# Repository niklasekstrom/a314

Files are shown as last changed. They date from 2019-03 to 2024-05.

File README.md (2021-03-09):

# A314

## What is it?

The *A314* is an expansion board for the Amiga 500 that goes in the trapdoor expansion slot. A Raspberry Pi (RPi) is attached to the A314, and the A500 and the RPi can communicate through a shared memory.

| | |
| --- |---|
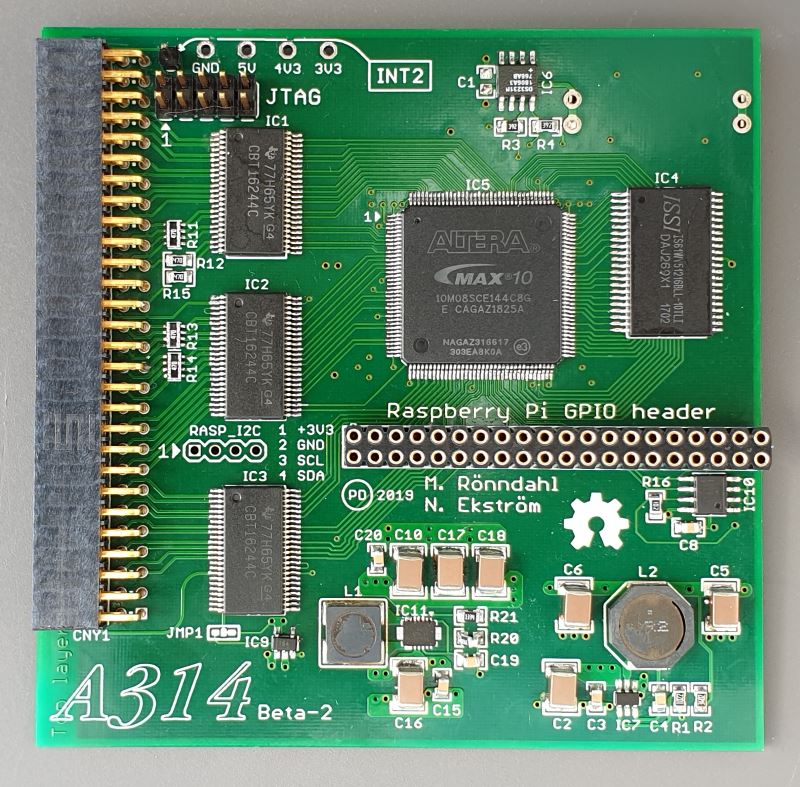
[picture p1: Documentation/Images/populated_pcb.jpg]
PCB
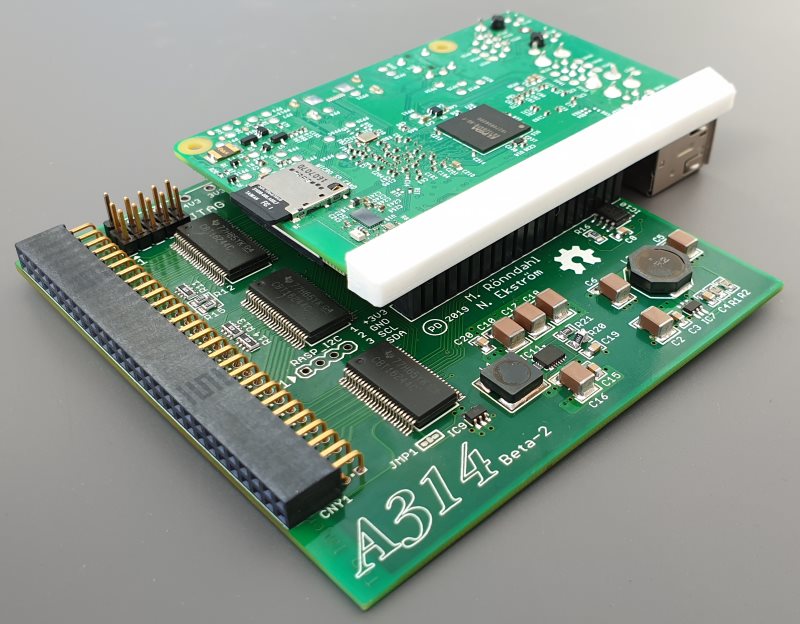
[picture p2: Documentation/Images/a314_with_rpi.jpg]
A314 with RPi attached
|  |  |

We have constructed a communication protocol through which associated processes on each platform (Amiga and RPi) can allocate logical channels, carried over one physical SPI channel. The protocol is handled by a driver on each side ([*a314.device*](Software/a314device) on the Amiga and [*a314d*](Software/a314d) on the RPi). The drivers are responsible for alerting receiving processes of incoming data via an interrupt.

## What can you do with it today?

We have implemented a few services that run on the RPi and on the A500:

*  [*a314fs*](Software/a314fs) is a file system that is mounted in AmigaDOS as a device, PI0:  
The volume in PI0: is called PiDisk:, and is mapped to a directory in the RPi.

*  [*pi*](Software/picmd) is a command that lets you invoke executables on the RPi from the AmigaDOS CLI. For example, if your current working directory is on PiDisk: and you run "pi vc hello.c -o hello", then the vc program (the VBCC cross-compiler) is executed on the RPi with the given arguments. It will cross-compile “hello.c” into the Amiga executable file “hello”. The resulting binary is immediately accessible through the a314fs.  
You may also launch Interactive applications using the pi command, such as "pi mc -a" which will run Midnight Commander. Running pi without any arguments is equivalent to "pi bash" and will present you with a bash prompt from the RPi.

| | |
| --- |---|
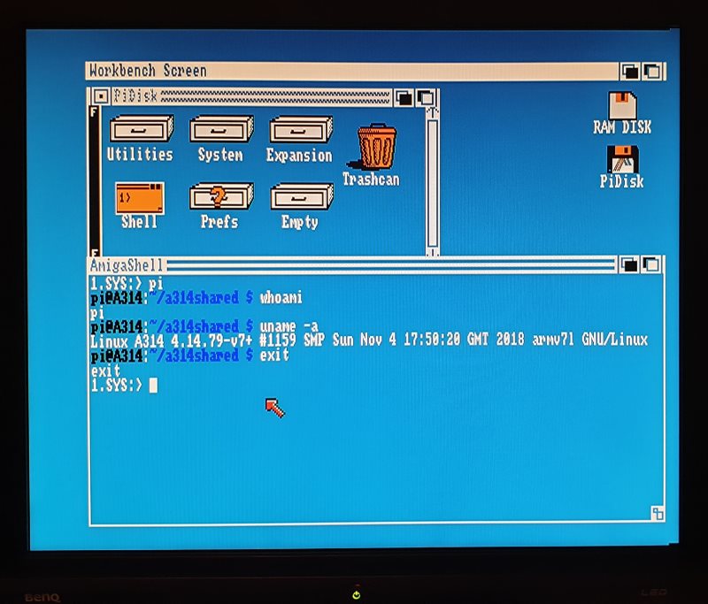
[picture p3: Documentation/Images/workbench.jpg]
Pi command
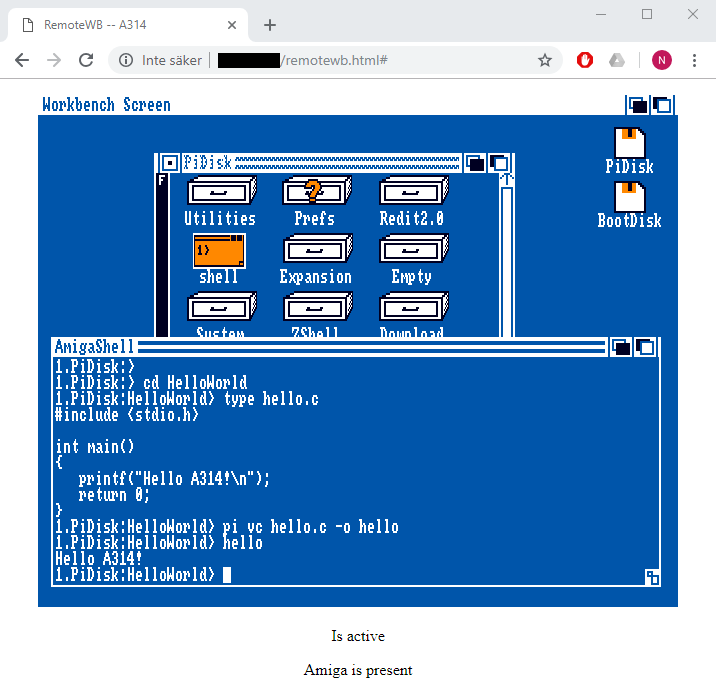
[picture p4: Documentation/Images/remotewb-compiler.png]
Cross-compiling in RemoteWB
|   |  |

* [*PiAudio*](Software/piaudio) lets the RPi stream audio samples directly to the shared chip memory, from where Paula plays those samples. PiAudio is integrated with [ALSA](https://www.alsa-project.org) on the RPi so that any program that plays audio through ALSA can be used, i.e. "pi mpg123 -a amiga song.mp3" plays song.mp3 using the program mpg123 to the Amiga.

*  [*RemoteWB*](Software/remotewb) works by moving the Workbench bitplanes over to the chip memory on the A314. This requires that the A500 has at least a 8372 Agnus. During drawing of each frame on the Amiga, the RPi reads those bitplanes, encodes them into a [GIF image](Software/bpls2gif), and transmits that image to a web browser through a web socket. The web browser in turn, returns key presses and mouse movements back to the Amiga through the same web socket. In effect, this becomes a web browser based remote control application, comparable to VNC but with near zero performance impact on the Amiga CPU!

*  [*VideoPlayer*](Software/videoplayer) is a simple program that displays a sequence of images on the A500 by letting the RPi write bitplanes directly to the shared memory (this again requires that the A314 memory is chip memory, and not "ranger" memory).

* [*ethernet*](Software/ethernet) is a SANA-II driver that forwards Ethernet packets to the network interface of the RPi. Together with an Amiga TCP/IP stack this provides network access to the Amiga.

## What could it potentially be used for in the future?

Here are some services that we have considered but not gotten around to implement:

* Networking through a *bsdsocket.library* implementation that forwards socket operations to the RPi and executes those operations there. This would give a higher degree of offloading than using the SANA-II driver with a TCP/IP stack running on the Amiga.

* Your ideas?

## Do you want to get involved?

If this sounds interesting, you'll probably want an A314 of your own to play with. We have released all the information needed to make a board, freely available in this GitHub repository.

In the [Hardware](Hardware) directory there are [schematics](Hardware/v1.1/Schematics/A314v1.1.pdf) and [Gerber files](Hardware/v1.1/Gerbers) that can be used to produce a PCB.

The Verilog source code used to generate a programming object file (.pof) for the Intel MAX 10 FPGA is available in the [HDL](HDL) directory. You'll need a USB-Blaster download cable (or a clone) to connect to the JTAG connector on the A314 board. You can compile the design using the [Quartus Prime Lite Edition](http://fpgasoftware.intel.com/?edition=lite).

The source code for the software that runs on the Amiga and on the RPi is available in the [Software](Software) directory.

If you have an idea about something cool to make using the A314, but you don't have the means to build a PCB on your own, then we have a small number of pre-built boards that we plan to hand out, given the idea sounds interesting enough. Send a message to Eriond on EAB and describe what you would like to make, and perhaps you can get one.

There used to be an IRC channel for discussing A314, but we have since moved to Discord. [Here's the invite link](https://discord.gg/TGZNKnA).

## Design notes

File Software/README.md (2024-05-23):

# A314 Software

The A314 software supports multiple variants of A314 hardware.
The variants of the software use the following acronyms:

- a314-td (trapdoor), works with A314-500 and A314-600
- a314-cp (clockport), works with A314-cp
- a314-fe (front expansion), works with A314-1000

## How to install

Software needs to be installed on both the Raspberry Pi side and on the Amiga side.

### Raspberry Pi

To build and install the software on the Raspberry Pi side, do the following:

- Install Raspberry Pi OS (I tend to use Raspberry Pi OS Lite 64-bit,
  but any recent version should work):
  <https://www.raspberrypi.com/software/operating-systems/>
- Update apt packages: `sudo apt update`, `sudo apt upgrade`
- Install Dependencies: `sudo apt install python3-dev python3-distutils python3-pip python3-virtualenv build-essential git iptables libraspberrypi-dev`
- Obtain a copy of the repository, either:
  - Clone the a314 repository: `git clone https://github.com/niklasekstrom/a314.git`, or
  - Download the sources from a release. Pick a release from
    <https://github.com/niklasekstrom/a314/releases>, download the file linked to as
    Source code (tar.gz), and extract with `tar xvf <filename>.tar.gz`.
- Change into the Software directory: `cd a314/Software`
- Run the installer script: `sudo ./install-pi.sh <model>`, where `<model>` is
  `td`, `cp` or `fe` depending on which variant of A314 is used.
- Reboot the Raspberry Pi: `sudo reboot now`

### Amiga

The binaries for the Amiga side are already built and are available as part of a release on the GitHub page: <https://github.com/niklasekstrom/a314/releases>

There are multiple sub directories in the release archive, and the files in those sub directories should be copied to the corresponding sub directories in the AmigaOS system volume.

Note that in the Devs directory there are multiple different versions of a314.device:
`a314-td.device`, `a314-cp.device`, `a314-fe.device`.
Copy only the version that matches your A314 hardware and rename it to `a314.device`.

After these files are copied to the Amiga it should be possible to run the pi command.
The pi command can be invoked by `pi` without any arguments to get an interactive bash terminal,
or with arguments to run a particular Linux command.

#### Configuration file

For the a314-cp driver it is possible to write a configuration file to `DEVS:a314.config`.
The configuration file is a text file, where each line has the format `<key> = <value>`.
The keys are:

- `ClockportAddress`: the address (in hexadecimal) of the clock port.
- `Interrupt`: the interrupt number used, either: 2 (INT2), 3 (Vertical blank), or 6 (INT6).

If the configuration file is not present then the default values are used, which for
a314-cp are:

```text
ClockportAddress = D80001
Interrupt = 6
```

#### Building

It is also possible to build the Amiga binaries from source, either on the Raspberry Pi or on a Linux PC.
To do so, follow these steps:

- Download and install VBCC:
  - On the bottom of this page, <http://www.compilers.de/vbcc.html>, there are archives with VBCC
    pre-compiled for different plattforms such as Linux (x64) and Raspberry Pi
  - Download the appropriate archive, e.g.: `wget http://www.ibaug.de/vbcc/vbcc_linux_x64.tar.gz`
  - Unpack to some suitable directory: `tar xvf vbcc_linux_x64.tar.gz -C ~/amiga/`
  - Set the VBCC environment variable: `export VBCC=~/amiga/vbcc`
  - Add VBCC to PATH: `export PATH=$VBCC/bin:$PATH`
- Download and add NDK3.2:
  - Download archive from Aminet: `wget http://aminet.net/dev/misc/NDK3.2.lha`
  - Install lha extraction software: `sudo apt install lhasa`
  - Extract archive: `lha xw=~/amiga/NDK3.2 NDK3.2.lha`
  - Add environment variable: `export NDK32=~/amiga/NDK3.2`
- Clone the a314 repo: `git clone https://github.com/niklasekstrom/a314.git ~/amiga/a314`
- Change into the Software directory: `cd ~/amiga/a314/Software`
- Build binaries by running: `make -f Makefile-amiga`

The binaries are now available in the sub directories of the `bin_amiga` directory.

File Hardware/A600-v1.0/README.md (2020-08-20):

# A314-600 PCB v1.0

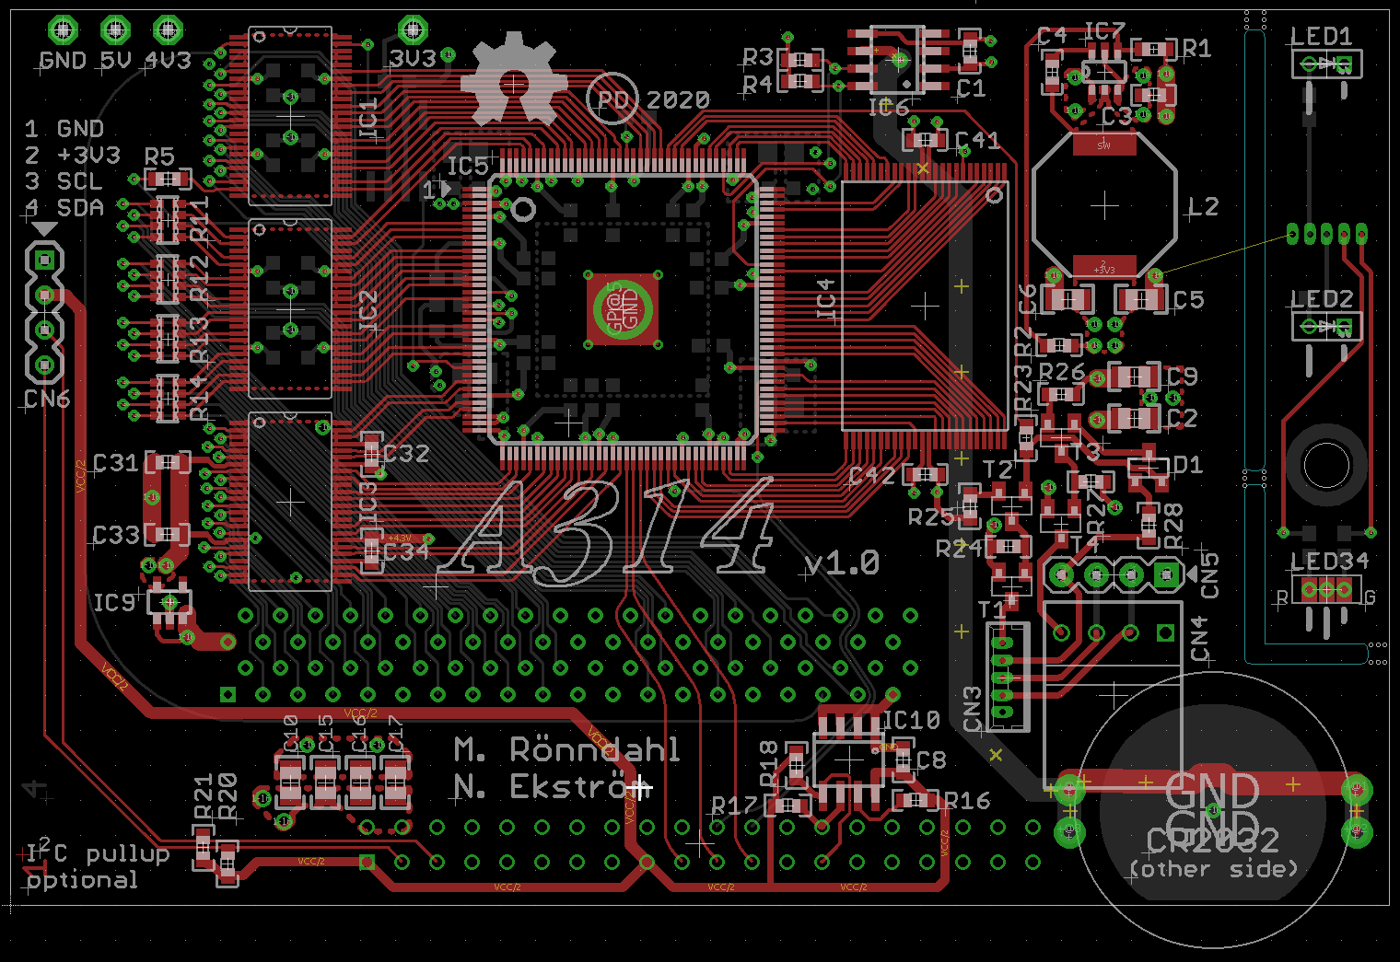
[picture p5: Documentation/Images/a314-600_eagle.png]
Layout screenshot

## Changelog

Initial commit of the **Amiga 600** version of the A314 board. Main differences compared to the Amiga 500 version:
 - 2MB chipRAM available as A314 shared memory (Disables the motherboard RAM)
 - Mechanical restrictions of the expansion bay implies Raspberry *Zero* form factor. The low power consumption and more generous voltage tolerances of the Zero* allowed for a simpler design, elliminating the 5V DC/DC converter (IC11 & Co.). 
 *see: https://raspberry-projects.com/pi/pi-hardware/raspberry-pi-zero/raspberry-pi-zero-hardware-general-specifications
  - Replacement LED board included. Allows for distinction between HardDrive and A314 activity on the same LED (Bi-colour)
 - Original LED overlay. If you don't want to use the included replacement LED board, then use your existing one, but connect it through the A314! A314 activity is then multiplexed on the HDD LED.
## Notes
This PCB has NPT milled slots with a narrow width (1.5mm) which some board houses won't accept. I have successfully used WellPCB with excellent results. Check with you favourite board house if they accept such narrow slots, before submitting a job.
At the moment of writing, AllPCB and JLCPCB could not handle this PCB. This may change in the future.

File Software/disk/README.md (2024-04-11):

# Disk Service

The disk service lets you mount disk images (ADF or HDF files) on the Raspberry
Pi as disk drives on the Amiga, PD0: through PD3:.

The a314disk.device is *romable* so it is possible to add it to a kickstart ROM
image and then it is possible to boot from a virtual drive. In the following
we focus on using a314disk.device as a normal device driver stored on disk.

## Disk geometry

The first time that a disk image (an ADF/HDF file) is inserted in a virtual
drive, the size of the ADF file is read, and from the size the disk geometry is
inferred. If the size of the image is 80\*2\*11\*512 = 901120 bytes then
the disk is assumed to be a standard floppy, with CHS geometry (80, 2, 11).
Otherwise the image is assumed to be an HDF file that has geometry (1, 32, x)
where x is the size of the image divided by 16384 (16 kB). This means that the
size of the disk image must be a multiple of 16 kB. The HDF image must also be
at least 1 MB.

The first time after each Amiga reboot that a disk image is inserted into a
virtual drive, the disk geometry for that drive becomes locked to the geometry
of the image. If the disk image is ejected from the drive and another image is
inserted then the newly inserted image must have the same geometry as the
previous one.

## Auto-insert

In the configuration file `/etc/opt/a314/disk.conf` on the Pi it is possible to
configure disk images that are automatically inserted when a virtual drive is
mounted on the Amiga. You specify the name of the disk image, which drive unit
the image should be inserted into, and if the image should be writable
(`"rw": true`) or only readable (`"rw": false`). A list of images can be
specified to be inserted into different drives.

## Manually insert and eject images

It is possible to manually insert and eject images. The commands for doing so
are a bit cryptic, and perhaps someone can write scripts that make this simpler.

The command to insert the disk image `/home/pi/disk.adf` into drive unit 0 and
make it readable and writable is:

`echo insert 0 -rw /home/pi/disk.adf | nc localhost 23890`

Remove the `-rw` to not make the image writable (i.e., only readable).

The above command should be executed on the Pi. By using the `Pi` command you
can run it from the Amiga as:

`pi bash -c "echo insert 0 -rw /home/pi/disk.adf | nc localhost 23890"`

Ejecting the image from drive unit 0 is done similarly using the following
command:

`echo eject 0 | nc localhost 23890`

## Mounting the drive

Before being able to use the virtual drive you have to mount it on the Amiga.
This is done using the `Mount` command. If you have an entry for drive PD0: in
the mount list file `DEVS:MountList` then you can mount PD0: with the command:

`mount PD0: from DEVS:MountList`

Note that you must first edit the mount list to set the geometry (Surfaces,
BlocksPerTrack, LowCyl and HighCyl) to match the geometry of the disk image.
I'm not sure if there is some way that the geometry can be taken from the values
reported by a314disk.device.

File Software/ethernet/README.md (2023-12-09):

# a314eth.device - SANA-II driver for A314

This SANA-II driver works by copying Ethernet frames back and forth between the Amiga and a virtual ethernet interface (tap0) on the Raspberry Pi. The Pi will, when configured properly, do network address translation (NAT) and route packets from the Amiga to the Internet.

## Configuring the Raspberry Pi

If the `install-pi.sh` script was run to setup the Raspberry Pi then the following
steps have already been carried out, and no more configuration should be needed
unless your network require some special configuration.

- Install pytun: `sudo pip3 install python-pytun`.
- Copy `ethernet.py` to `/opt/a314/ethernet.py`.
- Update `/etc/opt/a314/a314d.conf` with a line that starts `ethernet.py` on demand.
  - In order for `a314d` to pick up the changes in `a314d.conf` you'll have to restart `a314d`, either by `sudo systemctl restart a314d` or by rebooting the Pi.
- Copy `pi-config/tap0` to `/etc/network/interfaces.d/tap0`. This file creates a tap device with ip address 192.168.2.1 when the Raspberry Pi is booted up.
- Enable ip forwarding by uncommenting the line in `/etc/sysctl.conf` that says `net.ipv4.ip_forward=1`.
- Add the lines in `pi-config/rc.local` to the bottom of `/etc/rc.local` just before `exit 0`. This create iptables rules that forwards packets from the `tap0` interface to the `wlan0` interface.
  - Please note that if the Pi is connected using wired ethernet then `wlan0` should be changed to `eth0`.

## Configuring the Amiga

This has been tested with the Roadshow and the MiamiDX TCP/IP stacks. These instructions show how to configure Roadshow and Miami for a314ethernet, they do not describe how to install either.

### Common

- Copy `a314eth.device` to `DEVS:`.

### Roadshow

- Copy `amiga-config/A314Eth` to `DEVS:NetInterfaces/A314Eth`.
- Copy `amiga-config/routes` to `DEVS:Internet/routes`.
- Copy `amiga-config/name_resolution` to `DEVS:Internet/name_resolution`.
  - You should change the nameserver to a DNS server that works on your network.
  - Note that there may be settings in the above two files (`routes` and `name_resolution`) that you wish to keep, so look through the changes you are about to make first.

Reboot the Amiga and with some luck you should be able to access the Internet from your Amiga.

### Miami

- Create new device entry under **Hardware**
  - Click **New** and select **Ethernet**
  - Name it accordingly, for example `a314eth`
  - **Type** should be **SANA-II driver**
  - For **Driver**, type in, or browse to and select, `DEVS:a314eth.device` and click **OK**
- Create a new network interface in **Interfaces**
  - Click **New** and select **Ethernet** and **Internet**, click **OK**
  - Select the previously created **a314eth** and click **OK**
  - Set **IP** to **static** and type in `192.168.2.2`
  - Set **Netmask** to **static** and type in `255.255.255.0`
  - Set Gateway to **static** and type in `192.168.2.1`
  - Click **OK**
- Add a nameserver in **Database**
  - Select **DNS servers** from the spinner
  - Click **Add** and type in the address of your DNS server and press enter (you can use for example Google's DNS server at `8.8.8.8` if unsure)
- Remember to save your settings!

Click **Online** and hopefully your Amiga now has internet access.

Autostarting Miami and further configuration is left to the user.

## Networking Tips and Tricks

### Accessing services on your Amiga from other computers on the network

The above described configuration uses a method called masquerading to create a separate network for your Amiga behind the Pi. While this has the advantage of shielding it from attacks from other computers, sometimes you may want to be able to access network services on your Amiga from other computers besides the Pi.

To facilitate that access, the firewall on the Pi needs to be configured to forward incoming traffic on specific ports on the external interface to the Amiga. The example below assumes that the Pi and Amiga have both been setup as described earlier in this document.

```bash
iptables -A PREROUTING -t nat -i wlan0 -p tcp --dport 21 -j DNAT --to 192.168.2.2:21
iptables -A FORWARD -p tcp -d 192.168.2.2 --dport 21 -j ACCEPT
```

By adding these lines to `/etc/rc.local` directly following the other /iptables/ lines, the Pi firewall will start accepting connections to port 21 (FTP) and forwarding them to port 21 on the Amiga allowing an FTP client to connect to an FTP server running on the Amiga.

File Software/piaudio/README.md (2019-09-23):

# PiAudio

PiAudio is a service that integrates with ALSA, the sound sub-system on the Raspberry Pi, and lets sound samples be played via Paula on the Amiga.

The *piaudio* program should run on the Amiga. It allocates two sounds channels, one left and one right. Using the following command the piaudio program can run in the background:
```
run piaudio >NIL:
```

The file *.asoundrc* should be stored in `/home/pi` on the RPi. Most programs that play audio on the RPi can then be used. One such program is mpg123, which is started as:
```
mpg123 -a amiga song.mp3
```

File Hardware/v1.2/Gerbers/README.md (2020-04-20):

# Note
These Gerber files in this folder have been prepared according to the recommendation of JLCPCB.
If you whish to use them with a different board house, you may have to adapt some of the file extensions. Check what your favourite board house requires.

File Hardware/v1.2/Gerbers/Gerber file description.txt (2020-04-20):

The following files are supplied, and should be stacked as follow (top to bottom):

GKO : Board outline information

GTO : Top silkscreen
GTS : Top soldermask
GTL : Gerber top layer
G2L : Gerber first inner layer (Ground plane)
G3L : Gerber second inner layer (Power plane and some signals)
GBL : Gerber bottom layer
GBS : Bottom soldermask
GBO : Bottom silkscreen

TXT : Excellon Drill data

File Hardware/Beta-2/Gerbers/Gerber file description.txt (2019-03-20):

The following files are supplied, and should be stacked as follow (top to bottom):

GOL : Board outline information

GTO : Top silkscreen
GTS : Top soldermask
GTL : Gerber top layer
G1  : Gerber first inner layer (Ground plane)
G2  : Gerber second inner layer (Power plane)
GBL : Gerber bottom layer
GBS : Bottom soldermask
GBO : Bottom silkscreen

TXT : Excellon Drill data

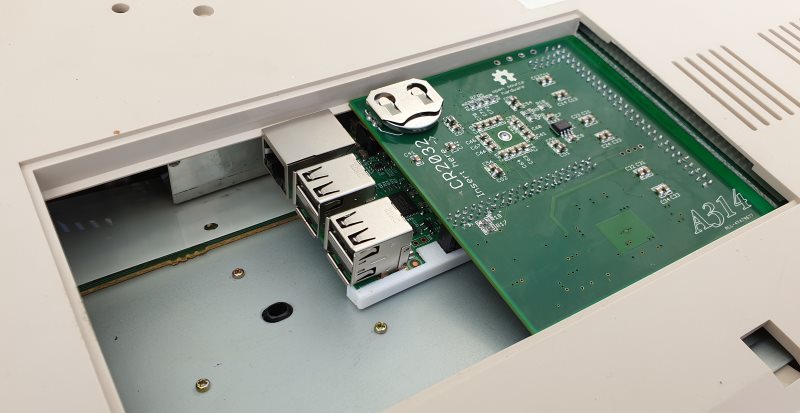
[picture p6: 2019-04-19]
Documentation/Images/a314_inserted.jpg

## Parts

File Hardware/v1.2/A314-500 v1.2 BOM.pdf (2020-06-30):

Mfg. part # | Mfg. | Digi-Key part # | Part | Amount Description
RC0805FR-0710K2L | Yageo | 311-10.2KCRCT-ND | R1 | 1 | RES SMD 10.2K OHM 1% 1/8W 0805
RC0805JR-071KL | Yageo | 311-1.0KARCT-ND | R10,16,22 | 3 | RES SMD 1K OHM 5% 1/8W 0805
EXB-V8V470JV | Panasonic Electronic Components Y4470CT-ND | R11,12,13,14 | 4 | RES ARRAY 4 RES 47 OHM 1206
RMCF0805JT68R0 | Stackpole Electronics Inc | RMCF0805JT68R0CT-ND | R15 | 1 | RES 68 OHM 5% 1/8W 0805
RC0805FR-0734KL | Yageo | 311-34.0KCRCT-ND | R2 | 1 | RES SMD 34K OHM 1% 1/8W 0805
RC0805FR-07143KL | Yageo | 311-143KCRCT-ND | R20 | 1 | RES SMD 143K OHM 1% 1/8W 0805
RC0805FR-071M33L | Yageo | 311-1.33MCRCT-ND | R21 | 1 | RES SMD 1.33M OHM 1% 1/8W 0805
RMCF0805JT3K90 | Stackpole Electronics Inc | RMCF0805JT3K90CT-ND | R3,4,17,18 | 4 | RES 3.9K OHM 5% 1/8W 0805
RMCF0805JT10K0 | Stackpole Electronics Inc | RMCF0805JT10K0CT-ND | R5,6,7,8,9,19 | 6 | RES 10K OHM 5% 1/8W 0805
CL21B104KACNNNC | Samsung Electro-Mechanics | 1276-1099-1-ND | C generic | 42 | CAP CER 0.1UF 25V X7R 0805
C4532X5R1E226M250KA TDK Corporation | 445-1444-1-ND | C2,5,6,10,16,17,18 | 7 | CAP CER 22UF 25V X5R 1812
GRM21BR60G336ME15L Murata Electronics | 490-16621-1-ND | C50,51,52,53 | 4 | CAP CER 33UF 4V X5R 0805
744062001 | Würth Elektronik | 732-3670-1-ND | L1 | 1 | FIXED IND 1UH 4.8A 14 MOHM SMD
7440650022 | Würth Elektronik | 732-1055-1-ND | L2 | 1 | FIXED IND 2.2UH 6.2A 15 MOHM SMD
BAT-HLD-001-THM | Linx Technologies Inc. | BAT-HLD-001-THM-ND | BAT1 | 1 | BATTERY RETAINER COIN PC PIN
SSW-128-02-S-D-RA | Samtec Inc. | SAM1218-28-ND | CNY1 | 1 | CONN RCPT 56POS 0.1 GOLD PCB R/A
76342-320LF | Amphenol ICC (FCI) | 609-5996-ND | RP1 | 1 | CONN RCPT 40POS 0.1 GOLD PCB
PRPC001SAAN-RC | Sullins Connector Solutions | S1011EC-01-ND | INT2 | 1 | CONN HEADER VERT 1POS
M20-9980245 | Harwin Inc. | 952-2119-ND | JMPB3 | 1 | CONN HEADER VERT 4POS 2.54MM
SPC02SYAN | Sullins Connector Solutions | S9001-ND | JUMPER | 3 | CONN JUMPER SHORTING GOLD FLASH
0022112026 | Molex | WM19460-ND | ACT.LED | 1 | CONN HEADER VERT 2POS 2.54MM
0797580015 | Molex | WM15725-ND | LED cbl.C | 2 | KK 8500113, 22 AWG,UL1061,300MM
0022013027 | Molex | 900-0022013027-ND | LED cn | 1 | CONN HOUS 2POS .100 W/RAMP/RIB
SSL-LXA228SYC | Lumex Opto/Components Inc. | 67-1139-ND | LED | 1 | LED YELLOW CLEAR AXIAL T/H AXIAL
MMBT4401LT1G | ON Semiconductor | MMBT4401LT1GOSCT-ND | T1 | 1 | TRANS NPN 40V 0.6A SOT23
SN74CBT16244CDLR | Texas Instruments | 296-19177-1-ND | IC1,2,3 | 3 | IC SWITCH BUS 16BIT FET 48-SSOP
CAT24C512WI-GT3 | ON Semiconductor | CAT24C512WI-GT3OSCT-ND IC10 | 1 | IC EEPROM 512K I2C 1MHZ 8SOIC
TPS63020DSJR | Texas Instruments | 296-36491-1-ND | IC11 | 1 | IC REG BCK BST ADJ 3.5A 14VSON
IS61WV51216BLL-10TLI ISSI, Integrated Silicon Solution Inc 706-1107-ND | IC4 | 1 | IC SRAM 8M PARALLEL 44TSOP II
10M08SCE144C8G | Intel | 544-3070-ND | IC5 | 1 | IC FPGA 101 I/O 144EQFP
DS3231MZ/V+ | Maxim Integrated | DS3231MZ/V+-ND | IC6 | 1 | IC RTC CLK/CALENDAR I2C 8-SOIC
TPS565208DDCR | Texas Instruments | 296-48755-1-ND | IC7 | 1 | IC REG BUCK ADJ 5A TSOT23-6
NB3N502DG | ON Semiconductor | NB3N502DGOS-ND | IC8 | 1 | IC CLK MULTIPLIER PLL 8-SOIC
TPS73643DBVR | Texas Instruments | 296-17498-1-ND | IC9 | 1 | IC REG LINEAR 4.3V 400MA SOT23-5

# A314 Bill Of Materials

Resistors

Capacitors

Integrated circuits

Inductors

Connectors & other HW

Semiconductors

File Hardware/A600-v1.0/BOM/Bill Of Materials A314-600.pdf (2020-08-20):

General Notes:

Mfg. Part Number | Manufacturer | Supplier | Supplier Part Number | PCB Reference | Quantity Unit Price Extended Price Description
BAT‐HLD‐001‐THM | Linx Technologies Inc. | Digi‐Key | BAT‐HLD‐001‐THM‐ND | BAT1 | 1 | 0,26 | 0,26 € BATTERY RETAINER COIN PC PIN
CL10B104KO8NNNC | Samsung Electro‐Mechanics | Digi‐Key | 1276‐1005‐1‐ND | Decoup. gen. | 38 | 0,031 | 1,17 € CAP CER 0.1UF 16V X7R 0603
CL21A226KQCLRNC | Samsung Electro‐Mechanics | Digi‐Key | 1276‐6687‐1‐ND | Decoupl. medium | 8 | 0,17 | 1,36 € CAP CER 22UF 6.3V X5R 0805
C2012X5R0J336M125AC | TDK Corporation | Digi‐Key | 445‐5986‐1‐ND | Decoupl. FPGA | 4 | 0,79 | 3,16 € CAP CER 33UF 6.3V X5R 0805
? | Valcon | Toby.co.uk | VEC‐127‐080‐R | CN1 | 1 | 0,69 | 0,69 £ 1.27mm Pitch Right Angle Card Edge Connector
76342‐320LF | Amphenol ICC (FCI) | Digi‐Key | 609‐5996‐ND | CN2 | 1 | 4,16 | 4,16 € CONN RCPT 40POS 0.1 GOLD PCB
0530470510 | Molex | Digi‐Key | WM1734‐ND | CN3, CN7 | 2 | 0,29 | 0,58 € CONN HEADER VERT 5POS 1.25MM
171826‐4 | TE Connectivity AMP Connectors | Digi‐Key | A112643‐ND | CN4 | 1 | 0,56 | 0,56 € CONN HEADER R/A 4POS 2.5MM
PH1RA‐04‐UA | Adam Tech | Digi‐Key | 2057‐PH1RA‐04‐UA‐ND | CN5, CN6 | 2 | 0,15 | 0,3 | CONN HEADER R/A 4POS 2.54MM 0 €
RB715UMTL | Rohm Semiconductor | Digi‐Key | 846‐RB715UMTLCT‐ND | D1 | 1 | 0,20 | 0,2 | RB715UM IS SCHOTTKY BARRIER DIOD 0 €
SN74CBT16244DGGR | Texas Instruments | Digi‐Key | 296‐6399‐1‐ND | IC1, IC2, IC3 | 3 | 1,30 | 3,90 € IC 16‐BIT FET BUS SW 48‐TSSOP
IS61WV102416DBLL‐10TLI | ISSI, Integrated Silicon Solution Inc | Digi‐Key | 706‐1541‐ND | IC4 | 1 | 12,18 | 12,18 € IC SRAM 16M PARALLEL 48TSOP I
10M08SCE144C8G | Intel | Digi‐Key | 544‐3070‐ND | IC5 | 1 | 15,90 | 15,90 € IC FPGA 101 I/O 144EQFP
DS3231MZ/V+ | Maxim Integrated | Digi‐Key | DS3231MZ/V+‐ND | IC6 | 1 | 6,88 | 6,88 € IC RTC CLK/CALENDAR I2C 8‐SOIC
TPS565208DDCR | Texas Instruments | Digi‐Key | 296‐48755‐1‐ND | IC7 | 1 | 1,32 | 1,3 | IC REG BUCK ADJ 5A TSOT23‐6 2 €
NB3N502DG | ON Semiconductor | Digi‐Key | NB3N502DGOS‐ND | IC8 | 1 | 3,01 | 3,01 € IC CLK MULTIPLIER PLL 8‐SOIC
TPS73643DBVR | Texas Instruments | Digi‐Key | 296‐17498‐1‐ND | IC9 | 1 | 1,42 | 1,42 | IC REG LINEAR 4.3V 400MA SOT23‐5 €
CAT24C512WI‐GT3 | ON Semiconductor | Digi‐Key | CAT24C512WI‐GT3OSCT‐NDIC10 | 1 | 0,51 | 0,51 € IC EEPROM 512K I2C 1MHZ 8SOIC
7440650022 | Würth Elektronik | Digi‐Key | 732‐1055‐1‐ND | L2 | 1 | 1,64 | 1,64 € FIXED IND 2.2UH 6.2A 15 MOHM SMD
SSL‐LX2573GD | Lumex Opto/Components Inc. | Digi‐Key | 67‐1046‐ND | LED1 | 1 | 0,37 | 0,37 € LED GREEN DIFF RECT 2MMX5MM T/H
SSL‐LX2573YD | Lumex Opto/Components Inc. | Digi‐Key | 67‐1050‐ND | LED2 | 1 | 0,43 | 0,43 € LED YELLOW DIFF RECT 2MMX5MM T/H
SSL‐LX2577IGW | Lumex Opto/Components Inc. | Digi‐Key | 67‐1051‐ND | LED34 | 1 | 0,54 | 0,54 € LED GRN/RED DIFF RECT 2X5MM T/H
RMCF0603FT10K2 | Stackpole Electronics Inc | Digi‐Key | RMCF0603FT10K2CT‐ND R1 | 1 | 0,09 | 0,09 € RES 10.2K OHM 1% 1/10W 0603
RMCF0603FT34K0 | Stackpole Electronics Inc | Digi‐Key | RMCF0603FT34K0CT‐ND R2 | 1 | 0,09 | 0,09 € RES 34K OHM 1% 1/10W 0603
RMCF0603JT3K90 | Stackpole Electronics Inc | Digi‐Key | RMCF0603JT3K90CT‐ND | R3,4,17,18,20,21 | 6 | 0,09 | 0,54 € RES 3.9K OHM 5% 1/10W 0603
RMCF0603JT47R0 | Stackpole Electronics Inc | Digi‐Key | RMCF0603JT47R0CT‐ND | R5 | 1 | 0,09 | 0,09 € RES 47 OHM 5% 1/10W 0603
RMCF0603JT10K0 | Stackpole Electronics Inc | Digi‐Key | RMCF0603JT10K0CT‐ND | R6,8,9,24,27 | 5 | 0,09 | 0,45 € RES 10K OHM 5% 1/10W 0603
RMCF0603JT150R | Stackpole Electronics Inc | Digi‐Key | RMCF0603JT150RCT‐ND | R7,15,19,22 | 4 | 0,09 | 0,36 € RES 150 OHM 5% 1/10W 0603
RMCF0603JT1K00 | Stackpole Electronics Inc | Digi‐Key | RMCF0603JT1K00CT‐ND | R10, R16 | 2 | 0,09 | 0,18 € RES 1K OHM 5% 1/10W 0603
RMCF0603JT4K70 | Stackpole Electronics Inc | Digi‐Key | RMCF0603JT4K70CT‐ND | R23, R28 | 2 | 0,09 | 0,18 € RES 4.7K OHM 5% 1/10W 0603
RMCF0603JT470R | Stackpole Electronics Inc | Digi‐Key | RMCF0603JT470RCT‐ND | R25, R26 | 2 | 0,09 | 0,18 € RES 470 OHM 5% 1/10W 0603
EXB‐V8V470JV | Panasonic Electronic Components | Digi‐Key | Y4470CT‐ND | R11,12,13,14 | 4 | 0,13 | 0,52 € RES ARRAY 4 RES 47 OHM 1206
MMBT4403LT1G | ON Semiconductor | Digi‐Key | MMBT4403LT1GOSCT‐ND T1, T4 | 2 | 0,13 | 0,26 € TRANS PNP 40V 0.6A SOT23
MMBT4401LT1G | ON Semiconductor | Digi‐Key | MMBT4401LT1GOSCT‐ND T2, T3 | 2 | 0,13 | 0,26 € TRANS NPN 40V 0.6A SOT23
0151340501 | Molex | Digi‐Key | WM15261‐ND | CBL1 | 1 | 3,31 | 3,31 € PICOBLADE 5 CIRCUIT 100MM
106 60,41 €
171822‐4 | TE Connectivity AMP Connectors | Digi‐Key | A121828‐ND | CBL2 | 1 | 0,25 | 0,25 € CONN RECEPT HOUSING 4POS
170262‐4 | TE Connectivity AMP Connectors | Digi‐Key | A100881CT‐ND | CNP1,2,3,4 | 4 | 0,20 | 0,80 € CONN SOCKET 20‐26AWG CRIMP TIN
110990080 | Seeed Technology Co., Ltd | Digi‐Key | 1597‐1502‐ND | CBL2, CBL3 | 1 | 3,13 | 3,13 € 4 PIN DUAL‐FEMALE JUMPER WIRE 30 (x5)
Floppy power cable assy. | ? | eBay | 1 | 4,00 | 4,00 € May need adjustments. Buy at least 80mm long.

Option A

Option B

This BOM is for a single board. Most components become cheaper when you buy more of them. Some are even cheaper in lots of 10 than in single quantaties.
The two options at the bottom of the list are for connecting the motherbords LED header to the A314. If you don't intend to use the new LED board, you don't need the cable.

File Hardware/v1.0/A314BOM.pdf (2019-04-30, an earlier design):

Amount Part | Description | Mfg. Part # | DigiKey Part #
1 | R1 | RES SMD 10.2K OHM 1% 1/8W 0805 | RC0805FR-0710K2L | 311-10.2KCRCT-ND
1 | R2 | RES SMD 34K OHM 1% 1/8W 0805 | RC0805FR-0734KL | 311-34.0KCRCT-ND
4 | R3,4,17,18 | RES 3.9K OHM 5% 1/8W 0805 | RMCF0805JT3K90 | RMCF0805JT3K90CT-ND
6 | R5,6,7,8,9,19 | RES 10K OHM 5% 1/8W 0805 | RMCF0805JT10K0 | RMCF0805JT10K0CT-ND
2 | R10,16 | RES SMD 1K OHM 5% 1/8W 0805 | RC0805JR-071KL | 311-1.0KARCT-ND
3 | R11,13,14 | RES ARRAY 4 RES 47 OHM 1206 | EXB-V8V470JV | Y4470CT-ND
2 | R12,R15 | RES 47 OHM 5% 1/8W 0805 | RMCF0805JT47R0 | RMCF0805JT47R0CT-ND
1 | R20 | RES SMD 143K OHM 1% 1/8W 0805 | RC0805FR-07143KL | 311-143KCRCT-ND
1 | R21 | RES SMD 1.33M OHM 1% 1/8W 0805 | RC0805FR-071M33L | 311-1.33MCRCT-ND
7 | C2,5,6,10,16,17,18 | CAP CER 22UF 25V X5R 1812 | C4532X5R1E226M250KA | 445-1444-1-ND
42 | C generic | CAP CER 0.1UF 25V X7R 0805 | CL21B104KACNNNC | 1276-1099-1-ND
4 | C50,51,52,53 | CAP CER 33UF 4V X5R 0805 | GRM21BR60G336ME15L | 490-16621-1-ND
1 | L1 | FIXED IND 1UH 4.8A 14 MOHM SMD | 744062001 | 732-3670-1-ND
1 | L2 | FIXED IND 2.2UH 6.2A 15 MOHM SMD | 7440650022 | 732-1055-1-ND
1 | CNY1 | CONN RCPT 56POS 0.1 GOLD PCB R/A | SSW-128-02-S-D-RA | SAM1218-28-ND
1 | RP1 | CONN RCPT 40POS 0.1 GOLD PCB | 76342-320LF | 609-5996-ND
1 | JTAG | CONN HEADER VERT 10POS 2.54MM | TSW-105-07-F-D | SAM8999-ND
1 | INT2 | CONN HEADER VERT 1POS | PRPC001SAAN-RC | S1011EC-01-ND
1 | BAT1 | BATTERY RETAINER COIN PC PIN | BAT-HLD-001-THM | BAT-HLD-001-THM-ND
3 | IC1,2,3 | IC SWITCH BUS 16BIT FET 48-SSOP | SN74CBT16244CDLR | 296-19177-1-ND
1 | IC4 | IC SRAM 8M PARALLEL 44TSOP II | IS61WV51216BLL-10TLI | 706-1107-ND
1 | IC5 | IC FPGA 101 I/O 144EQFP | 10M08SCE144C8G | 544-3070-ND
1 | IC6 | IC RTC CLK/CALENDAR I2C 8-SOIC | DS3231MZ/V+ | DS3231MZ/V+-ND
1 | IC7 | IC REG BUCK ADJ 5A TSOT23-6 | TPS565208DDCR | 296-48755-1-ND
1 | IC8 | IC CLK MULTIPLIER PLL 8-SOIC | NB3N502DG | NB3N502DGOS-ND
1 | IC9 | IC REG LINEAR 4.3V 400MA SOT23-5 | TPS73643DBVR | 296-17498-1-ND
1 | IC10 | IC EEPROM 512K I2C 1MHZ 8SOIC | CAT24C512WI-GT3 | CAT24C512WI-GT3OSCT-ND
1 | IC11 | IC REG BCK BST ADJ 3.5A 14VSON | TPS63020DSJR | 296-36491-1-ND

# A314 Bill of Materials

Resistors

Capacitors

Inductors

Connectors & other HW

Integrated circuits

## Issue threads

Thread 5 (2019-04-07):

JTAG pin header is slightly too close to trapdoor pin list

niklasekstrom, 2019-04-07:
The JTAG connector cannot be inserted all the way down on the JTAG header, because the connector hits the pins on the trapdoor pin list. The JTAG connection works fine anyway, but if the JTAG pin header is moved 1 mm (or so) away from the trapdoor the problem will likely go away.

Closed 2019-04-28.

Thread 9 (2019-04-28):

Alter footprint for IC11 to improve solderability

Eriond, 2019-04-28:
Due to the boards DIY nature, the footprint of IC11 should include a stopmask at the bottom layer to allow for through-PCB-heating reflow process as shown in this video: https://www.youtube.com/watch?v=d-f-SBC0GrU
Adding such a stopmask won't affect other mounting methods of the component.
To further enhance the through-PCB-heating process, a GND polygon should be placed in layer 3 (power layer) beneath the IC. This should assist heat conductivity through the board at that specific location.

Closed 2019-04-28.

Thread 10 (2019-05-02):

Add jumper that either connects EXMEM to ground or leaves it disconnected

niklasekstrom, 2019-05-02:
The mod that makes A500 rev 6A get 1 MB chip mem (instead of 0.5 MB chip and 0.5 MB slow) which is described here, https://s6.postimg.cc/53hat1xkh/A500_6a_1_MBCHIP.png, requires soldering two jumpers on the motherboard. By adding a jumper on A314 it would be possible to avoid soldering JP7; however JP2 still needs soldering.

Eriond, 2019-09-10:
Modifications are done. New PCBs are ordered, and once we get to verify them in the coming weeks, the repo will be updated with new files.

niklasekstrom, 2019-09-28:
Fixed by the PCB 1.1 update.

Closed 2019-09-28.

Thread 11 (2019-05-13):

Add jumper that disconnects RAS0

niklasekstrom, 2019-05-13:
It is possible to cut traces on JP3 on the A500 motherboard, and thereby disable the on-motherboard DRAM. In that case, A314 should respond to DRAM-requests for RAS0 as well as RAS1. But if the firmware is modified so that A314 responds to RAS0-requests then there will be collisions when running on an A500 whose JP3 traces are not cut. Therefore a jumper on A314 would be useful to disconnect RAS0 when the JP3 traces are not cut.

This jumper would also be useful for A500+, so that a single FPGA programming file can be used regardless if the A314 is going to be used in an A500 or an A500+.

Eriond, 2019-09-10:
Modifications are done. New PCBs are ordered, and once we get to verify them in the coming weeks, the repo will be updated with new files.

niklasekstrom, 2019-09-28:
Fixed by the PCB 1.1 update.

Closed 2019-09-28.

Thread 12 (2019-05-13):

Replace GetA314MemBase with a more generic function

niklasekstrom, 2019-05-13:
Currently the a314.device driver exports a function named GetA314MemBase, which returns a memory base address, such that the A314 memory starts at this position in the Amiga memory map.

However, this is a bit restricting. If the A500's internal DRAM is disabled it is possible to let A314 take over all memory, but in that case the memory mapping could be more complicated. For example, the 0-0.5 MB chip mem could be mapped to 0-0.5 MB A314 memory, but $c00000-$c80000 is mapped to 0.5-1MB A314 memory.

A more general solution would be to let a314.device export a function that takes an Amiga address and returns the corresponding A314 address. This would replace GetA314MemBase completely. Thus, all existing applications would have to be updated (which is still easy because they are all in this repository).

Closed 2019-08-17.

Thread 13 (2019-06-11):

Create a preconfigured boot floppy

niklasekstrom, 2019-06-11:
It would help if there was a preconfigured floppy that could be download with all software on it needed to boot up an A314 board.

arnljot, 2020-01-24:
This could be built upon the AROS m68k boot floppy. This way all license issues are avoided, and one still has a floppy in adf (I presume) that one can write, boot and install from on the amiga.

niklasekstrom, 2023-08-13:
The files for this disk are now available in the release, so I'm closing the issue for now.

Closed 2023-08-13.

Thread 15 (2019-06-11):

The repo shouldn't contained compiled binaries; instead make releases

niklasekstrom, 2019-06-11:
Currently the compiled binaries are included in the Git repository. It turns out it's easy to forget to compile one binaries after a change, and then the source and binaries are out of sync; this has already happened and led to unnecessary trouble shooting. Probably remove the binaries from the repo and make proper releases (that can be hosted on GitHub as well.)

terriblefire, 2019-08-16:
My suggestion would be a top level makefile that traverses the structure and produces all the binaries in a new top level folder.

Make clean would wipe all the binaries in the repo.

You could probably even get a Quartus docker container and build the firmware at the same time. I’d have to look into that latter bit. Container might be too big to be practical

niklasekstrom, 2019-08-16:
"My suggestion would be a top level makefile that traverses the structure and produces all the binaries in a new top level folder."

This sounds like a good improvement. I tried to do something like this but wasn't able to have make automatically create the sub-folders in the output folder corresponding to the sub-folders in the source folder. Probably creating the needed sub-folders explicitly in the Makefile should be good enough.

I was also thinking about setting it up so that files can be compiled on a raspberry pi, as some people may use Windows laptops, but everyone with an interest in this project has at least one RPi.

niklasekstrom, 2023-08-13:
This was fixed at some point.

Closed 2023-08-13.

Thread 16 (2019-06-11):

Add power buffer to allow for proper RPi shutdown

Eriond, 2019-06-11:
Add a power buffer to the A314 5V power line, possibly in the form of a supercap, in order to maintain a short-lived supply to the RPi after the Amiga has been powered off. Also connect a "power sense" to an unused GPIO pin, to trigger proper shutdown procedure on the RPi.

Eriond, 2019-09-10:
This enhancement did not make into the 1.1 update. It is still pending for now; there is no committed time-frame.

arnljot, 2020-01-23:
This can be done in software, no need for any special hardware. Many open souce raspi based projects have solved this. OctoPi, and also MISTER Fpga for instance is running of a read only system partition, and has the read write partitions as memdisks. If the user wants a persistant r/w partition on the SD card, it can be provided, but just as with a real amiga hd, he'd be warned not to power on without letting write operations "settle in". Could even send an "unmount" command before power off.

I'd rather suggest that effort is spent by raspbian able techs so make a A314 distro that can download updates from this github, and mostly only be mounted in r/w mode for online updates.

Normal operation r/w is either in a memdisk or a user-partition that can be recovered without risking loosing system partition integrity. The boot partition should be read only, given the hw limitations of the raspi which is shares with it's host, the amiga.

Closed 2024-05-21.

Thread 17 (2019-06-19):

Does that board also allow CHIP RAM extensions?

hlide, 2019-06-19:
It is not very clear if that board also offers true chip RAM extension to allow A500 rev6A to get 1 MB or A500+ to get 2 MB. Moreover, there are some moddings which allow to get 2 MB on an A500 ev6A involving the change of an Agnus chip.

There is also the case of [the Boobip board](http://www.boobip.com/hardware/A500_2MB) which allow a clever way to maximize the chip RAM size and getting the rest as slow RAM. I wonder if it would be possible to make A314 compatible with the Boobip in such a way you only need a Gary adapter board, connecting cables and jumper wires (for full 2MB mod) while A314 may acte as the memory board.

niklasekstrom, 2019-06-20:
Hi!

> It is not very clear if that board also offers true chip RAM extension to allow A500 rev6A to get 1 MB or A500+ to get 2 MB.

A314 has 1MB SRAM on the board, and behaves as a normal A501(+) memory expansion. This means that on an A500 rev 6A with the 1MB chip mem mod (as described here https://s6.postimg.cc/53hat1xkh/A500_6a_1_MBCHIP.png) the A314 provides another 512kB chip mem, for a total of 1MB chip. In an A500+ A314 provides an extra 1MB chip mem, for a total of 2MB chip mem. We actually tried the A314 in an A500+ for the first time yesterday night and it works well; currently there's a separate branch for A500+, https://github.com/niklasekstrom/a314/tree/one_mb, but it will be merged into master shortly.

> There is also the case of the Boobip board which allow a clever way to maximize the chip RAM size and getting the rest as slow RAM.

There is currently no support for using the other 512kB memory in an A500 rev 6A with a Gary adapter, as is done with the Boobip board, but maybe that is something that someone can add in the future?

Another option is to disable the internal 512kB chip mem in an A500 rev 6A, as described here https://github.com/niklasekstrom/a314/issues/11, and let A314 provide all 1MB chip; the benefit is that the whole 1MB is then accessible to the raspberry pi.

Closed 2019-07-19.

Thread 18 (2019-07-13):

A600 support

tangorri, 2019-07-13:
Would be nice to add support for Amiga 600, or if it is allready supported, validate it by test and clarify the support in documentation and description of the project.

Eriond, 2019-07-13:
We're working on a A600 version of the hardware, and while it's still in the design phase, we can already now conclude it will only be able to support the Pi Zero form factor due to mechanical restrictions. More info will be posted once there is some real hardware produced. Probable time frame is Q1 2020.

Eriond, 2019-11-09:
**Update:** A600 version is now actively being worked on. We can already now see that there will be a couple of differences compared to the A500 version:
- The memory will be increased to 2MB, thus allowing for all chip memory to reside on the A314. (prices for 2MB SRAM chips have dropped recently to apx the same levels as 1MB had previously)
- Our intention is that programming (and re-programming) of the FPGA flash is made possible directly from the Raspberry Pi, without any additional hardware. Those who wish to continue using a classic JTAG interface can still do so, but will have to make a custom adaptor cable.

plasticuser, 2020-03-01:
If the A600 version can only support a Pi Zero due to physical limitations, could it alternatively support a CM3 compute module?

Eriond, 2020-03-01:
It could, but it won't because we see it as a too big re-design for very little, if any, advantages. So the cost/performance ratio is not justifiable.

plasticuser, 2020-03-02:
The cost is exactly the same as being able to use a full Pi 3 B+. It's more than a Pi Zero, but then the design brief calls using a Pi Zero a "design limitation"... ;)

The physical advantages are numerous.  Being able to place the connectors exactly where they are best suited. Being able to place only the connectors required. Lower power footprint by not using devices that are not installed. Extremely compact form.

I'd be happy to design this PCB.

niklasekstrom, 2020-03-02:
@plasticuser If you feel up to designing and building a version of A314 for A600 using a CM3 compute module then of course that would be a very positive development :)

My initial thoughts about such a design is: how will you add back networking (wifi) and USB capabilities that are not available in CM3 (as compared to in Pi Zero)? And what is the combined cost of CM3 + additional chips? If the cost is not a lot more than a Pi3 then this sounds very interesting.

plasticuser, 2020-03-03:
I recognize it would cost a "little" more. I'm estimating about $7-$9.

The fun bit is that I could supply the board with build time configuration options to lower the price point. Happy with ethernet? Cool! Want lots of I2C or SPI break outs on the board? Cool! 2MB SRAM? Yisss!

It is worth $10 on the final product price to have the four cores, and the option of SSD or eMMC - which is MUCH faster and more reliable. The CM4 is going to have a different pinout, but it would be easy to adapt the design at that point for the new connector.

So, yes, I'll happily do it, and I'd prefer to do it within your project than forking it and creating confusion and lots of extra work for myself ;)

niklasekstrom, 2020-03-03:
@plasticuser That sounds great! Let us know if you have any questions or need help with anything.

plasticuser, 2020-03-04:
I shall.

niklasekstrom, 2020-08-21:
Fixed by commit c04a5190c468d0750ad19860da7e57ba250490ec.

Closed 2020-08-21.

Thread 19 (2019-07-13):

Raspian usecase?

apocalypse2012, 2019-07-13:
Hello,
Thanks for this innovative contribution.
I wanted to ask about use-cases for the a314. I am wondering if this device would make it possible to use the Amiga 500 as a peripheral dock for an Amibian based Raspberry Pi? Either using the Pi’s HDMI output or the a500s graphics via the shared graphics memory? Either way, using all the Amigas IO devices (floppy, mouse, ports, etc) as devices exposed to Amibian through the a314 device. This would allow a great old school user experience while enabling a much broader and more modern set of functionality that emulation provides.
Is this part of your concept or otherwise on the roadmap?

Raymond

niklasekstrom, 2019-07-14:
Hi Raymond,

Thanks for sharing your idea! It's not something I had considered before.

The way we have been thinking about A314 is that the RPi becomes a co-processor to the Amiga. It seems that what you are proposing is turning that assumption upside down, and instead the A500 (or at least the input/output devices of the A500) are under the control of the RPi.

I guess what you are proposing should be doable for some motivated individual, but at the same time it seems non-trivial. I don't think it's something that me or Eriond is going to pursue, as none of us is using Amibian. If you or anyone else wants to pursue this idea I'll be happy to answer any questions about A314!

apocalypse2012, 2019-07-14:
I would be interested in pursuing this, but it would be slow going in the near term with my current load. I am a developer with some programming experience. My question is where to start. It seems you already have a base driver, and building a higher level protocols and driver APIs should be possible, possibly trivial for the most basic features. Can you give me any guidance on how to proceed from a hardware perspective? How are you provisioning dev hardware for yourselves?
I have a 500 and an rpi3 I can dedicate to this right now, but my hardware and soldering skills are not up to board fabrication.

Eriond, 2019-07-15:
As mentioned in the EAB A314 thread, there is a "program" where we are giving away hardware to motivated programmers with bold/interesting ideas, but that lack the skill to assemble the boards themselves. You may fall into that category :)
However, the supply of free boards is extremely limited, so we would like to see some sort of proof that you may be up to the task you're pursuing. One way to go would be to read up on the currently available source, and tell us your strategy on how you intend to proceed. Asking relevant programming-related questions, maybe forking the project, etc. will help as well.
At best, we could send you a board somewhere mid-August (since I'm on vacation right now).

Closed 2019-07-14.

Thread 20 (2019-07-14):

Create an audio device in Linux (running on the RPi) that outputs sound via Paula

niklasekstrom, 2019-07-14:
I'm not sure how hard this would be, but if possible it could be nice to make a sound device for Linux, running on the RPi, that writes the sound samples to A314 memory and then sets it up on the Amiga side so that the sound is played by Paula. I'm guessing this would allocate two of the four Amiga audio channels.

aiobofh, 2019-07-15:
This would be really cool. Kind of a channel-mixer outputting 14-bit sound!? :)

niklasekstrom, 2019-07-16:
It seems like it may be possible to use the ALSA file (or shm) plugin (https://www.alsa-project.org/alsa-doc/alsa-lib/pcm_plugins.html) to obtain samples in a format suitable to write to Amiga chip memory.

This is what I've got so far for .asoundrc:

pcm.tofile {
    type file
    format raw
    file /tmp/out.raw
    slave.pcm null
}

pcm.amiga {
    type plug
    slave {
        pcm tofile
        format S8
        channels 2
        rate 16000
    }
    hint {
        description "Changes format to match Amiga"
    }
}

Closed 2019-07-18.

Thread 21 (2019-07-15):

Idea: Make Chucky add this to the ReAmiga1200 and ReAmiga3000 motherboards in the future

aiobofh, 2019-07-15:
By being able to access chip-RAM the same ways on these new-school remakes of Amiga motherboards there should be a solid user-base that would be able to benefit from A314 :D

I guess the guys behind Amy and remakes of varius A4000 PCB's could do it too.

Just a crazy idea.

aiobofh, 2019-07-15:
:) he's looking in to it

niklasekstrom, 2019-07-15:
This idea isn't exactly an issue related to A314, but to those motherboards you mention. That being said, I think it would be completely awesome if someone integrated A314 into an Amiga motherboard! I'm all for it.

Closed 2019-07-15.

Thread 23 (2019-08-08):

Component kits?

aiobofh, 2019-08-08:
Is there somewhere I can get already sourced komponent kits? I already have the PCB on the way, but just sourcing a few components (if you're not a die-hard electronics hoarder) is quite boring. :) I'm looking forward to be USING my A314 and start developing interesting things A.S.A.P. :) And not being used to sourcing, it feels both time consuming and quite pricy ordering just a few components here and there (or a shit-load of them that will just lay around).

A zip-loc with all the things needed for the build for sale? Someone? :) - I could also go for a already built one if anyhone have one extra.

nonarkitten, 2019-08-08:
https://octopart.com/bom-tool/1Z6N9nNS

aiobofh, 2019-08-08:
Brilliant! Thanks @nonarkitten :) You learn every day.

Eriond, 2019-08-08:
I made a DigiKey BOM a while ago that still should be valid: https://www.digikey.se/BOM/Create/CreateSharedBom?bomId=7822225
And to comment on _aiobofh_'s statement; yes, sourcing and building DIY hardware is not everybody's cup of tea. It is both time consuming and sometime pricey. That's just a decision you have to make: Either take on the challenge of building it yourself or wait around until someone else makes a batch that you could buy from.
It's not my intention to scare you away, but do mind that the A314 PCB is not a beginners project. I would place it somewhere 3-4 on a scale to 5. (1 being breadboard projects and 5 being BGA components) Considering myself a senior hardware developer, I have still made soldering mistakes/fails on 3 out of the 6 boards that I've built so far. And I had to use a really good microscope to find and correct two of them.
I sincerely wish you the best of luck, and hope that you will be able to enjoy our own A314 as soon as possible. If you get stuck, drop us a message on EAB forum, and we will do our best to help you out.

aiobofh, 2019-08-08:
@Eriond ordered the stuff :) Build time is comming. The BOM-import thing was quite convenient. Did not know about it :D

Closed 2024-05-21.

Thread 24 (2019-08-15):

Docker suggestion

terriblefire, 2019-08-15:
Hi, great project

You could reuse my dockerfile and docker code to give people build environments for the drivers...

Take a look

https://github.com/terriblefire/cdtv.device

terriblefire, 2019-08-15:
I just did this for you quickly.. here's a pull request.. doesnt touch any existing files

https://github.com/niklasekstrom/a314/pull/25

niklasekstrom, 2019-08-15:
Hey Stephen, that's a great suggestion. I will try it out this evening. Thanks!

niklasekstrom, 2019-08-16:
That's excellent, thanks again.

I was planning to reorganize the directory structure a bit at some point, related to issue #15. If you have any thoughts or ideas about ways to do that I would be happy to hear them :)

Closed 2019-08-16.

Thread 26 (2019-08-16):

A2000 support?

amipieTOASTER2K, 2019-08-16:
Great work...

  Amiga 2000 support should be fairly straight forward... Has a version for the A2000 commenced? Do I need to produce an adapter board of sorts for the A500 version to fit in an A2000? Unlike the A600, space shouldn't be an issue here.

  I already have a raspberry PI mounted on a blank PCB in an unoccupied slot inside my A2000 case. A2000 supplying only power. Also using some KVM switches and sum A234 and more for I/O... Running AmiBerry... Need to have some Ami-Pie sex happening soon... Faster File transfers?, Perhaps shared storage and more... I do have an A500... I would rather install the A314 in the A2000... Currently sourcing components for build... Thanks guys...

niklasekstrom, 2019-08-16:
Hi amipieTOASTER2K,

Amiga 2000 support is actually not as straight forward as one might think. The A500 expects the board that is inserted in the trapdoor expansion slot to be DRAM chips and not much else, so the FPGA on the A314 must communicate using the same protocol as expected from DRAM chips. A board in an A2000 however communicates with the Amiga using the Zorro II protocol, which is quite different.

Moreover, memory that sits on a board in a Zorro II slot cannot be directly accessed by the custom chips (i.e. is not chip mem), which prevents some applications (VideoPlayer, PiAudio, RemoteWB) from working. There are, however, several applications that would still work well (a314fs, pi, bsdsocket.library), so I think a version for A2000 could still be interesting.

I don't know of any effort to build a Zorro II-version of A314. My feeling is that it shouldn't be all that hard, especially since the A500 version of A314 already exists. If someone were to design a Zorro II board I would certainly help out with adapting the A314 Verilog and software for it.

nonarkitten, 2019-08-16:
What you would want to do is make a small board that sockets into Agnus, this is where most of the signals from the Amiga 500 trapdoor come from as well as a few from Gary. This could be combined with a pin-shift to use the more common 8375 Agnus and would almost be a simple straight pin-out to the header.
```
DRD 15:0     AGNUS
DRA 8:0      AGNUS
_EXTICK      GARY
_CASL        AGNUS
_CASU        AGNUS
_RAS0        AGNUS
_RAS1        AGNUS
_WE          AGNUS
_CCK_A       AGNUS, Invert CCK*
_CLKRD       GARY
_CLKWR       GARY
D 3:0        AGNUS
A 5:2        AGNUS
```
* Note about CCK_A; the Amiga 500 inverts CCK to make CCK_A using a 74F04.

amipieTOASTER2K, 2019-08-17:
Hi Guys,
  Thanks for the quick response. I will initially test an A314 on my A500... I was planning on using a non occupied Zorro-II slot (ultimately my current non-linked ami-pie slot). A Zorro board incorporating a header plug for your A314 board as well as a shielded ribbon cable to an Agnus socket module/board (daughter-board). I would hope to include the Megachip 2MB on the zorro card. Shielded clip (or solder) leads to Gary or A larger Agnus socket daughter-board incorporating a Gary via a through socket? (old wire wrap i.e long legs).
  Yes, the Amiga's ability (or lack thereof) to drive signals as well as signal interference is a concern. I am willing to try though.... Out of the question with modern hardware. The Amiga is a little more forgiving at its frequencies.... Though I lack the experience here. A shielded ribbon cable might not be enough. Impedance mismatches, signalling/timing issues-skew/overshoot etc.
  I have a modified Amiga 2000 utilizing a [Super-obese (EXTREMELY-FAT-LADY) Agnus 8372B 318069-03] he...he... ;-) and 2MB chip ram.
Compatibilty issues with the Toaster also I guess... I would remove it first... Thanks for the heads up on the Hex inverter... which would live on the daughter-board with other buffering...
  A2000 support could be a real can-o-worms... at least in my perceived form factor. Perhaps I should stop being a tight a$$ and just buy a Vampire... Anyone using a Vampire with a VideoToaster? I do love to tinker with my Amiga's... Cheers,

nonarkitten, 2019-08-19:
There should be no compatibility issues with Toaster with the A314 and we have users who use the Vampire and Lightwave all the time, so I'm assuming it works fine, but it's untested.

The Agnus/Gary adapter is the only solution for the A314 in the Amiga 2000. The Zorro slots will not work -- there is no try. It's a simple enough board -- maybe an afternoon of routing and adding one MOSFET to invert the CLK_A signal?

rdesaintleger, 2023-10-13:
Hi.

I'm quite new to Amiga Hardware addons. But according to schematics, the Amiga 2000 already have a clock chip on board. Isn't there a risk to have two clock chips sharing the same signals ?

A solution would be to use the _OVR signal to disable Gary address decoding process (but I have to admit that this way of doing things is not clear to me).

About Zorro implementation of the A314 it would be much more complicated. From my understanding of hardware and schematics, cards on the Zorro bus can master the 68k bus by issuing a request/acknowledge to buster. Once they do so, they can read/write anywhere including chip and fast as long as the target address is within the 24bits addressing of the original 68k bus (that may not be the case for the blizzard 2060 fast ram for example).

Closed 2024-05-21.

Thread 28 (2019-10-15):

AHI Audio via Raspi?

hgw77, 2019-10-15:
First of all, the a314 is a realy nice idea!
To use the trapdoor expansion slot in that way could bring complete new possiblitys to the Amiga500 :-)

As I read about `piaudio` the first idea was, why it is not the other way? For Amiga500 there is no modern soundcard available so I was thinking it would be very nice to have a `ahi.device` or something to play amiga audio through the soundcard of the raspi :-)

aiobofh, 2019-10-15:
I am also in to trying to create an AHI-device with 14bit paula playback... Stereo mixer in the pi in other words.

Also a MHI-device for decoding mp3:s and such would be wonderful.

I will try to get my card working tonight, if I am lucky

niklasekstrom, 2019-10-15:
Sounds like a great idea! 👍

Eriond, 2019-10-15:
@hgw77: Thank you for the kind words.
Before you do a driver to use the Raspberry Pi's audio output for the Amiga, you should consider the wide-spread criticism against the audio quality of Pi (https://hackaday.com/2018/07/13/behind-the-pin-how-the-raspberry-pi-gets-its-audio/ , the comments are especially interesting).
There is however a good reason for letting the Pi do the audio decoding, and that is if it was part of a RTG solution, where the HDMI would not only carry the video output from the Amiga, but the audio as well.
Even if the Amiga's "sound card" isn't modern, I would argue that it still produces audio with better quality compared to the output from the Raspberry's 3.5mm jack. But maybe it's just me being forgiving and nostalgic :) Perceived audio quality is such a personal experience.

hgw77, 2019-10-16:
@Eriond: thank you for your repsonse, and you are right the audio quality of the internal raspi is not that good but there are a wide range of USB-Soundcards with much better sound quality that you can use instead? :-)

By the way, I love the good old `Paula` and I am always impressed what this sound chip can do ;-) but on the other side I was always `dreaming` to have a better soundcard on my Amiga500 to play audio in 16bit quality.

aiobofh, 2019-10-16:
@hgw77 you can get as much as 14bit stereo at 56kHz (with more exotic screen modes) thats where AHI _mixing_ in the pi comes in, but then shuffle the mixed left/right as 14bit-hack sample data to Paula... it's an AWESOME upgrade without having to buy expensive audio hardware. :)

hgw77, 2019-10-16:
@aiobofh: yes thats what I mean with impressed. The `Paula` is more than 30 years old and can play audio in 14bit and 56kHz? Thats awesome and `C=` didn't know about that killer feature ;-)
But that feature comes at a cost, it needs a very powerfull CPU. With the installed Pi in the trapdoor maybe a standard Amiga500 (or with 68020/30) could play (with the help of the pi) an mp3 in 16bit quality ;-)

aiobofh, 2019-10-16:
@hgw77 yeah. But with a314 allowed to write chipmem the CPU usage (for playback) is close to zero om the Amiga side.

hgw77, 2019-10-16:
A now I understand! the PI is doing all the prepartions so the paula only needs to play :-)

On the other side if you have an PI-AHI Device you can use any player on amiga side (like Eagleplayer or AmigaAMP) to play audio on the PI, but than the amiga needs to handle the encoding of an mp3 or playing a mod file by itself and send the audio data to the PI.

aiobofh, 2019-10-16:
@hgw77 correct. And we could also have a MHI-device (the API used for stand-alone hardware mp3-decoders) too. just shuffle the mp3-data to the pi, let it decode it, and shuffle the 16bit wav back to the Amiga and then AmigaAmp or whatever shuffels it back to the PI using this AHI-device for 14bit stereo encoding. :) There could also be a short-cut raw-allocating paula directly with the MHI device, but it's not as system friendly, but would reduce the traffic between Amiga and Pi with that bidirectional raw 16bit stereo sample.

aiobofh, 2019-10-16:
... Hm. On second thought. I think MHI is supposed to hijack Paula directly, since it's constructed for stand-alon output devices. But I have not studied the interace enough to be 100% sure.

aiobofh, 2020-01-22:
OK, sadly newer AHI versions will probably not compile for a stock A500 with 68000. I guess if one have a 020-or-better accelerator the idea is still on. I will however not have such card in any near future :(

nonarkitten, 2020-01-23:
> OK, sadly newer AHI versions will probably not compile for a stock A500 with 68000. I guess if one have a 020-or-better accelerator the idea is still on. I will however not have such card in any near future :(

Have you tried [Run68017](http://aminet.net/package/util/misc/Run68017)? It implements many 68020 opcodes and might let your 68000 run AHI compiled for 68020.

aiobofh, 2020-01-24:
> Have you tried [Run68017](http://aminet.net/package/util/misc/Run68017)? It implements many 68020 opcodes and might let your 68000 run AHI compiled for 68020.

Nope, I have not tried this. Seems a bit of a flimsy solution. Besides... I can't really see why e.g. 6.0 should not work to compile for low-end 68k - at least not for just a simple PAULA mode (other drivers might not compile, but it's not really needed in this case since I've based my patch on the existing PAULA driver). I'll revisit this project... But then again. The Run68017 might be more useful to get any AHI-capable softwares (players) to actually run on 68000 tho. So it's stil a valuable tip. Thanks @nonarkitten :)

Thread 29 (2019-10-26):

Program FPGA firmware from RPi

niklasekstrom, 2019-10-26:
It chould be possible to connect additional pins from the RPi pin header to the FPGA JTAG pins, and then use the RPi for programming the FPGA firmware.

The program described on this page has been used successfully to program the firmware: https://weekly-geekly.github.io/articles/343524/index.html

niklasekstrom, 2019-12-22:
The program mentioned above have been modified by its author (as suggested by Marcin) to make it configurable which RPi pins are used for the JTAG connection. https://translate.google.com/translate?hl=&sl=ru&tl=en&u=https%3A%2F%2Fmarsohod.org%2F397-pi4-m2rpi

peon374, 2020-04-20:
The program talked about looks like it is intended to be a JTAG debugging server.  If you just wanted to use the connection to be able to upgrade the firmware on the MAX10, I think openOCD should be able to do this.  If the build process used to make the POF goes one step further and makes a SVF file as part of your release, it could be pulled in and flashed without any Quartus toolchain.

Eriond, 2020-04-20:
That sounds really interesting! We would appreciate it if you could consider trying it out?

Eriond, 2020-04-23:
Issue resolved with updated PCB layout, v1.2

Closed 2020-04-23.

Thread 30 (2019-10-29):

USB access via ANAIIS

nonarkitten, 2019-10-29:
This would grant access to the Pi's USB ports from ANAIIS, a USB stack for the Amiga which is compatible with the stock  7MHz 68000 CPU. They provide a libusb-based proxy driver for running on UAE which should serve as a good foundation. There is far less API here to implement than BSD sockets.

http://aminet.net/package/driver/other/anaiis_hostusb

aiobofh, 2019-10-31:
@nonarkitten yepp! Lovely! This is a good alternative for more powerful Amigas with A314, most def. For the purist this would be heavenly. Also Poseidon could be supported (since it seems more main-stream).

For low-end Amigas that want to benefit from the off-loading by the Pi other solutions are more appropriate - But the one does not rule out the other.

alexchaney, 2020-02-24:
Too much work.  Let Linux manage the mounting and unmounting of USB device natively and then just have a softlink to the pi0: directory.  Keep it super simple and let Linux just handle it all.

aiobofh, 2020-02-25:
@alexchaney the ANAIIS/Poseidon approach would enable more powerful A500/A600's to get ("any") USB device in native-world, not only storage devices. But I think the A314 makes most sense on an unaccelerated (or modestly accelerated) A500/A600 - hence doing the USB termination Linux-side and make special/minimal stuff to enable the Amiga-side to access it makes more sense, as you say.

But... It would still be a nice option to have the complete USB-stack Amiga-side, if someone is to implement #30 :)

neilDGD, 2023-12-20:
Been thinking of this, did anyone take this on and make a start and have anything to share? My thoughts are - PI side management of the usb itself (Os level or if need be another service), and hook into Poseidon on the Amiga side, but use the a314fs as a template because who wants to reproduce all that packet logic etc? Not sure i'm digging myself a hole into oblivion here...

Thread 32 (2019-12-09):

Include 2MB of ram and use it as chipmem with 2 extra pins for RAS/CAS

jcagigal, 2019-12-09:
It could be a good idea to add 2MB and use A314 for keeping the entire chipmem in A314. This could have many advantages like full control of the chipmem contents (autoboot may be possible creating the required structures on chipmem).

Check out this card that swaps expansion memory with on board chipmem:
http://www.boobip.com/hardware/A500_2MB/A500-_chip_RAM_mod

Mobo memory could be used as ranger/slow mem.

It would be even better if a Gary adapter was used so more addresses could be accessed. That way expansions could be mapped to memory, e.g. a window of 4MB of memory for RTG memory.

niklasekstrom, 2020-01-30:
The A600 version of A314 has 2MB SRAM. Using the /ROE pin which is available on A600 the trapdoor expansion port (but not on A500) the DRAM on the motherboard is disabled, so that all 2MB chip memory is provided by A314.

I don't believe there are currently any plans to add a Gary adapter, but anyone is certainly free and encouraged to do so.

Closed 2020-01-30.

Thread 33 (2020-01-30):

Implement more dynamic method for detecting A314 memory ranges

niklasekstrom, 2020-01-30:
The [current code](https://github.com/niklasekstrom/a314/blob/master/Software/a314device/a314driver.c#L105) for deciding which memory ranges are provided by A314 is fairly inflexible, and it has proved to cause problems on several occasions.

As an example, an A500+ with a Vampire has both 2MB chip memory and 0.5MB slow mem at address 0xc00000. This combination was not anticipated and therefore didn't work correctly. A fix for this particular configuration was easy to make, but in general it would be nice to have a more dynamic method of detecting which memory ranges are provided by A314.

One method I have been considering is that when a314.device is starting it could disable interrupts (and maybe DMA as well?) and then put the A314's FPGA in a special detection mode, and read and write to potential A314-addresses, and at the same time communicate with the FPGA through the clock port, to find out if a particular address is handled by A314.

The reason why DMA might have to be disabled is that the blitter can write to memory, and a write by the blitter during the detection procedure could be mistaken for a write by the CPU. Disabling all DMA, even bitplanes, could make for a slightly annoying user experience, if the screen goes blank (for a short period). It may be possible to only disable blitter DMA, but this is still not completely unproblematic since the copper could start blitter DMA, so maybe disabling both blitter and copper DMA would work (this needs some experimentation).

Another method would be to have a configuration file that is stored in DEVS: or S:, that describes which memory ranges are mapped to A314. This is less dynamic but avoids performing the detection procedure each time the Amiga boots up.

Closed 2020-08-07.

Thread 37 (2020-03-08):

Make a314d check spidev.bufsiz setting.

arnljot, 2020-03-08:
We've got experience that this setting is very important and that users are missing out on setting it correctly.

a314d should check this on startup, and refuse to run if not set correctly. Maybe just start in a minimal mode without services so that a314.device won't hang on the amiga side? Investigation needed.

if not spidev.bufsiz=65536 then log.error "spidev.bufsiz not set to correct value, check spelling?"

niklasekstrom, 2020-04-23:
I noticed that the value that is currently in use can be read from /sys/module/spidev/parameters/bufsiz, so it should be easy to do this check when a314d is started.

Closed 2023-11-18.

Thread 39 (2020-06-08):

Amiga 1200 version

w-A-L-L-e, 2020-06-08:
Really cool board, makes me want to swap my a1200 for an a500 (almost ;) ). I know the expansion port differs in the a1200 but would it theoretically be possible to have a similar expansion board for the a1200? This looks like a really cool way to get a modern linux combined with the old amiga I especially liked the cross compile and pi command line features that and the drive mounting and gfx/chip memory sharing gives endless possibilities. So the trick to share the chipmem ram is that possible on the a1200 also? Maybe we need to emulate a 68020 as well to allow this on a1200?

nonarkitten, 2020-06-08:
In theory yes. It would have to live on top of the clock port header and use pogo pins to hit the unpopulated header pads. There are two signals which I believe disable the on-board memory and could allow the board to take over. Ensuring good signal contact could be very challenging without a major motherboard modification (installing the missing headers).

w-A-L-L-e, 2020-06-08:
Cool, how do you know this ? I mean is there some good book or documentation you recommend? I have no problem in soldering some extra headers to my clockport and converting an a314 with jumper wires to an accelerator connector for my a1200 ;) (price is doable in belgium https://amigastore.eu/738-amiga-1200-accelerator-connector-for-the-edge-expansion.html). Also my trials might help you creating an a1200 version after this project is matured.

Eriond, 2020-06-08:
Hold your horses... Even though you'll probably get the signals from point A to point B correctly, there is the issue of "signal integrity", which will cause all kind of issues for you. I don't mean to rain on you parade, but if you rush into this without too fast, you will be disappointed.
This is an interesting idea though, and I will most certainly look into the matter.

nonarkitten, 2020-06-08:
To disable on-board chip RAM you need to bring /ROE high. This is pin 22 of P9A.

nonarkitten, 2020-06-08:
> Hold your horses... Even though you'll probably get the signals from point A to point B correctly, there is the issue of "signal integrity", which will cause all kind of issues for you. I don't mean to rain on you parade, but if you rush into this without too fast, you will be disappointed.

Yes, I did say that good signal contact would be the big challenge here.

niklasekstrom, 2020-06-08:
Hi @w-A-L-L-e!

The custom chip signals (those in the custom chip section in [this image](http://amigadev.elowar.com/read/ADCD_2.1/Hardware_Manual_guide/node02CB.gif)) are not available on the A1200 trapdoor expansion port unfortunately. The needed signals are available on the P9A/B ports however, but to get to those signals reliably you'd probably have to solder pin headers onto the motherboard (they are typically not populated, as seen in [this picture](https://bigbookofamigahardware.com/bboah/media/download_photos/a1200mb_rev1d4.jpg)).

Then there is the issue that the data bus to the chip ram is 32-bit on the A1200 but 16-bit on the A500. All pins on the MAX10 FPGA chip that is used on the current version of A314 are already taken, so another chip package would be needed (probably a BGA package). Moreover, the DRAM on the A1200 uses fast page mode, so the logic that arbitrates accesses between Amiga and Pi would have to be reworked completely probably.

So to your question if it is theoretically possible to build A314 for A1200; I guess so :) But in practice I think it would be a significant undertaking.

w-A-L-L-e, 2020-06-18:
Thanks for the more detailed info. I was indeed hoping for something only described in first paragraph (just some extra jumper wires and a header to solder). However your explanation in second paragraph clears a lot of questions up for me.

So basically a similar device could be made for the A1200 but we can't reuse the current A314 board. For A1200 we need a new pcb with larger fpga and quite some extra software development to make it possible. So maybe someday when you've exhausted customers from A500, A600, A1000 owners, hope you get around to the A1200 version of this type of expansion.

It's a really cool idea using a modern SBC as expansion device and if it ever gets an A1200 version I'll be first in line to pre-order one. What really surprised me is that just a 4 wire spi connection is fast enough to do that bi-directional memory copying back and forth between pi and amiga 500.

Closed 2020-06-12.

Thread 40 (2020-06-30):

V1.2 BOM is wrong

peon374, 2020-06-30:
This is why you should machine generate the BOM.  Your resistor pack in the BOM has the wrong quantity (3 instead of 4)

Eriond, 2020-06-30:
This has now been corrected. thank you for pointing it out.
The BOM is machine generated using the BOM.ulp from Eagle CAD. But there are components that aren't present in the schematic such as wires, LED connectors and jumpers, so manual modifications had to be made. I guess that during this process, a human error snuck by.

Closed 2020-06-30.

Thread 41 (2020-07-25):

a314eth.device should avoid calling AllocSignal() on the schedule of the client, which happens to be the TCP/IP stack

obarthel, 2020-07-25:
I know, a314eth.device is still new :-)

Some rules for device drivers are peculiar, and the device init/exit code still needs work.

But for network device drivers for which the TCP/IP stack (or Envoy) is the only client, there are additional perils. If you call AllocSignal() in the device open/close function, it may actually fail. You don't know how many free signals are still available for the taking.

At the minimum, please check if AllocSignal() returns failure.

If the point is just to have a signal for communicating with the unit Process, you can avoid calling AllocSignal() altogether by using SIGB_SIGNAL (and its corresponding flag SIGF_SIGNAL) instead. There are some precoditions for doing so, though.

Happy to help you out if you want me to :-)

niklasekstrom, 2020-07-25:
Thanks Olaf for pointing out this issue!

Please let me know if you see any other issues I should handle.

Closed 2020-07-27.

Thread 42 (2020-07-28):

Raspian lite doesn't come with some required python libs

peon374, 2020-07-28:
If you add
```
sudo apt install python3-distutils python3-dev
```
to your build instructions or the build script it will make sure they are present and you won't get:
```
**bpls2gif.c:5:10: fatal error: Python.h: No such file or directory
 #include <Python.h>
          ^~~~~~~~~~
compilation terminated.**
```
or
```
cd bpls2gif ; python3 setup.py install
Traceback (most recent call last):
  File "setup.py", line 4, in <module>
    from distutils.core import setup, Extension
ModuleNotFoundError: No module named 'distutils.core'
```

niklasekstrom, 2020-07-28:
Sound good to me. I will add it to the wiki.

Regarding the change to the makefile, would you like to fork the repo, do the change, and then create a pull request?

I can of course do the change to the makefile myself, but I think it's better if you do the pull request because then it it is clear that it was contributed by you.

aiobofh, 2020-07-28:
Side-note: I completely stoped using raspbian in favor of ubuntu-server - i feel it's more stable when bumping release versions than raspbian. and more current packages, along with a richer repository.

peon374, 2020-07-28:
Done.

Also I will give ubuntu-server a go with all the PI variants I have.  I assume that raspbian has a more comprehensive kernel but that is an assumption made because RPI foundation promotes Raspbian over other distros.

niklasekstrom, 2020-07-28:
Excellent, thanks!

Closed 2020-07-28.

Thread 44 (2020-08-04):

HowTo for flashing FPGA from Raspi on V1.2

MC68060, 2020-08-04:
Would be nice if there is a HowTo... I've never flashed a device from a Raspi.

Eriond, 2020-08-04:
I agree. We should add that to the wiki.
Today it's a bit cumbersome, because it requires specialized software. A preferable solution would be if there was a utility, command-line or other, that could do the complete flashing procedure "in one go". AFAIK we don't have that. It would be a much appreciated contribution to the project, if someone was willing to take on such a task.

The MAX10 FPGA that we use in this project has a dual configuration feature, that allows to have one config "running" and another one in stand-by. The concept is that you could either flash the stand-by area and then reset, swapping the two, or use one of them as a "factory default" for a fall-back scenario (in case something doesn't work out with the primary config).
This does in theory allow for flashing from the Amiga side too, but of course requires quite some additional work on the HDL. More information about this feature can be found in [https://www.intel.com/content/dam/www/programmable/us/en/pdfs/literature/hb/max-10/ug_m10_config.pdf](https://www.intel.com/content/dam/www/programmable/us/en/pdfs/literature/hb/max-10/ug_m10_config.pdf)

niklasekstrom, 2023-01-05:
A wiki page about this was created here: https://github.com/niklasekstrom/a314/wiki/Program-FPGA-using-openocd-on-the-Pi

Closed 2023-01-05.

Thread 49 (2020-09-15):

The latest versions of Raspbian are not working with A314

niklasekstrom, 2020-09-15:
It seems that something has changed in the latest versions of Raspbian in a way so that the communication with A314 is not working any longer. The latest version that has been tested and known to work is from February 2020.

Places I can think of to start looking is changes that were made to the SPI driver, or something with the device tree. Investigate.

From the bottom of this list, https://en.wikipedia.org/wiki/Raspberry_Pi_OS#Version_history, it seems that two versions of Raspbian were released in February, then a version in May, and then a version in August (all in 2020). The version in August has upgraded the kernel from 4.19 to 5.4.51. It would be helpful to know if the problem exists in the May version, or if the problem were introduced with the move to the new kernel version.

niklasekstrom, 2020-09-16:
Apparently the SPI_CS_HIGH handling has changed between Linux kernel 4.19 and 5.4: https://github.com/raspberrypi/linux/issues/3745#issuecomment-663078159

As far as I can tell, [the driver](https://github.com/raspberrypi/linux/blob/1c64f4bc22811d2d371b271daa3fb27895a8abdd/drivers/spi/spi-bcm2835.c) doesn't take the SPI_CS_HIGH flag into account at all.

Closed 2020-09-16.

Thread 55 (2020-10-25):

Attempting to move directory into subdirectory of itself should be an error

cnilsson, 2020-10-25:
Using WB 2.1 and a directory structure of a/b/c you can drag a into c without any error message on a314fs. This triggers a 202 object in use error when done on other devices.

Fortunately Linux refuses to do the impossible move on a filesystem level.

It is up to ACTION_RENAME_OBJECT to not allow this:

> In particular, the RENAME_OBJECT action allows
moving files across directory bounds and as such must ensure that it
doesn't create hidden directory loops by renaming a directory into a
child of itself.

Closed 2021-08-13.

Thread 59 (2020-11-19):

Implement support for ACTION_DISK_INFO and ACTION_INFO to a314fs

Eriond, 2020-11-19:
Implementing support for the two INFO commands isn't as trivial as one might think at first. This has to do with how the PiDisk volume is presented to the AmigaOS.
Normally a volume is the whole logical space on a physical disk, or in the case of a partitioned disk, part of that space. But generally, the AmigaOS assumes that it has exclusive control over that space, and as such it only asks for two key parameters: Total blocks and Used blocks, assuming that the obvious third parameter, Free blocks, can be calculated using the first two.
In the case of A314fs, where the presented volume (usually) is a sub-folder on the Raspberry OS disk, the "Total" amount of block presented to AmigaOS isn't necessary equal to the actual amount of blocks on Raspberry OS disk. Or is it?
This really depends on what the user is expecting to see when they, for instance open a PiDisk window on the WorkBench.
Consider this: The first time you open a PiDisk (after initial installation of A314), the a314shared folder on the RPi is empty. Let's assume you are using a 16GB SD card, where apx. 4GB is used by the Raspberry OS. What should the title bar of the PiDisk window display?
a) `0% full, 12 GB free, 0KB in use`
b) `25% full, 12 GB free, 4GB in use`
Option "a" may seem intuitive if you're only interested in the Amiga-part of things, but then you have to consider that the free space can suddenly change - regardless of any files you may, or may not have added to the volume, depending on what is happening over at the Raspberry side. Not so intuitive, and maybe confusing. "b" on the other hand makes no sense from a Amiga point of view; "how can there be 4GB in use when I can't see any files?"
One way to circumvent the issue, could be to create a real partition on the RPi SD card, that is exclusive to the AmigaOS, and this is where the a314fs.conf would point to.
There is (at least) one more thing to consider, and that is how the different sizes (Total, Used) are forwarded to the AmigaOS. It uses a concept of "blocks", not bytes, and accompanying these blocks is a conversion factor called "BLOCKSIZE", indicating number of bytes per block. The variables holding the sizes are of type LONG, ie. 32bits. This puts an upper limit on what can be reported back to the AmigaOS, depending on which blocksize is chosen. As storage media evolves, we see increasingly large SD cards, and it can be tempting to choose a large blocksize to accomodate for a very large Volume size. But this will then be at the expense of "resolution" or granularity; adding small amounts of data to the volume won't cause any changes in the reported used space, thus there is no visible change in usage to the Amiga user.

cnilsson, 2020-11-21:
Thought I would put my two cents in!

Regarding free space, in my opinion option b seems like the more reasonable one. Having the amount of used/free space changing is a lot less confusing than having the total size of the volume change. As a bonus I think the implementation would be more straight forward as you don't have to check how much space is used by the a314shared directory, you only care about the whole filesystem.

So, blocksize. Are there any good reasons against going for the native Linux filesystem block size (usually 4kB)? After all, that is the least amount of data a file can occupy on the filesystem anyway so reporting fractions of the native block size makes little sense. With 4kB blocks the max size is 16TB right? Good enough, at least for SD card storage, for a while I think. Famous last words perhaps? :)

Eriond, 2020-11-21:
If that is the case (4kB blocks), then it sounds like an obvious choice. I was not aware of it (getting too old, I guess :).
And yes, as long as the reason for the missing/occupied space is communicated to the end user, I think option b is the better one.

Eriond, 2020-11-21:
Given it some more though, I appreciate the concept of transparency towards AmigaOS even more. Basically, I didn't think that modern OS's used the concept of "blocks" any more, and were completely byte-oriented. So you're completely on target by forwarding the actual values from Linux. I noticed that there are even ready-to-use replies from the statvfs() method (f_blocks, f_bfree and f_bsize).
One thing to dig deeper about is how early versions on the AmigaOS handle the possibly large values that could come from modern SD-card sizes. My initial trials with AmigaOS 3.1.4 shows that it can handle values above 4GB  without issues. (up to 32GB tested OK)

niklasekstrom, 2020-11-23:
Option b sounds good to me too, for the reasons @cnilsson mentioned. os.statvfs() seems like a good function to use.

A question is whether AmigaDOS handles block sizes that are not 512 bytes. I know that a314fs assumes that blocks are 512 bytes in a few places, but that can be changed I guess. Another option is to keep the 512 byte block size and just recompute the number of blocks to match that (512 bytes); this will work for disk sizes up to 1 TB, which may very well be "forever" (or not, in which case the code needs to be changed again later).

idrougge, 2022-12-22:
AmigaDOS definitely handles varying block sizes; I have 4 kB blocks on some of my partitions to save memory.

dcutugno, 2024-08-08:
#96 fixed this

Closed 2024-08-09.

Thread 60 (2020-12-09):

a314fs crashes with yellow screen if directory does not exist

gmcn42, 2020-12-09:
Hi everyone!

First off: great work, I'm really impressed by the whole project, especially the professional-looking hardware design!

Today I tried to get mine working, it's a Rev. 1.1 I bought off AmiBay.
My System: A500+, Kick 3.1, TF536 68030/50MHz, Indivision ECS V2

The A314 is jumpered to 2MB mode and Amiga Test Kit is reporting 2M Chip, memory test runs flawless. INT2 is connected.

After working out I had to explicitly enable the SPI bus on the Pi, I was able to use the pi command and videoplayer.

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

When I try to use a314fs, though, the Amiga crashes (Blinking LED of death, Yellow Screen).

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

`mount PI0:` seems to work fine but once I either `cd PI0:` or click `PI0:` in DirOpus, the crash occurs.

<del>Any idea how I can narrow down what's wrong? I thought about removing the accelerator and trying it on plain 68000 but I'd have to scavenge the CPU from another machine.</del>

**EDIT2:** Sorry, nevermind, **my fault**. I had to copy `a314fs.conf` file to `/opt/a314` and create the a314shared directory. Now everything works fine. I am leaving this issue up though as I believe a314fs should handle this error more gracefully than throwing a Guru. Also apparently I can report compatibility between A314 and TF536, yay! :)

EDIT: a314eth.device is working great as well (even with an old version of MiamiDX I had lying around). <del>So I guess if a314fs refuses to work with my setup, FTP file transfer is just fine.</del> :)

niklasekstrom, 2020-12-10:
Hi @gmcn42,

First, well done with the troubleshooting and great to hear that everything is finally working well! We can add both A314+TF536 and a314eth+MiamiDX to the "tested and seems to work" list :)

Secondly, this is definitively a bug that should be fixed, so thanks for reporting it. That the Amiga crashes with a yellow screen is a bit surprising (and interesting!). I suppose it should be a simple fix though, to check in a314fs.py if the shared directory exists, and if not then perhaps create it, or print a helpful error message (and certainly not crash).

A related thing that has been talked about, but no one got around to (yet), is to write a small program that installs the software needed on the Pi, and verifies that all files and configurations are as they should.

cnilsson, 2021-08-13:
I've reproduced this using kickstart 2.0 (albeit without the yellow screen - guru "only").

There is no error handling when there is no a314shared directory leading to a314fs.py throwing an exception and bailing out and thus stops responding to requests. The easiest way to fix this is probably to have a314fs.py create the directory as suggested. It looks like @niklasekstrom already had plans to handle problems such as a non responsive a314fs in a314fs.c but understandably moved on since everything worked.

niklasekstrom, 2023-08-13:
An installer script has been added, that amongst other things creates an a314shared directory.

Possibly/probably the code for a314fs should handle that the a314shared directory is missing, but I'll close this issue for now in any case.

Closed 2023-08-13.

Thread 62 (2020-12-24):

PCB standoff holes for securing Raspberry PI

prgp, 2020-12-24:
I noticed that the image [a314_with_rpi.jpg](https://github.com/niklasekstrom/a314/blob/bc3836feaac5206eead7e3241f3c7c8cd64175b7/Documentation/Images/a314_with_rpi.jpg) shows a Raspberry Pi (model unknown) dangling from the GPIO pins - modern Raspberry PI (later revision 1 plus models and later IIRC) have common hole placements for standoffs, would it be possible to incorporate at least one if not two of the standoff holes on the top of the board so that the Raspberry Pi can be secured properly to the board (as one would a normal Raspberry HAT).

Likewise on both the A500 and A600 boards having at least one standoff hole that conforms with a Raspberry Pi Zero would also be most helpful.

Eriond, 2020-12-24:
The RPi in question on that picture is the Model 3. Yes, you're right about it not having any stand-offs, but that is the result of numerous iterations and thorough tests of the PCB and it's mechanical integrity. You see, stand-offs are intentionally excluded for several reasons:
1) Excluding them allow for a a better and more relaxed routing of the PCB traces, avoiding us to use unnecessary thin traces or close track spacing.
2) The A314 system (meaning the A314 board together with the RPi attached on top, inside an Amiga) is in a physically secure location in space, not prone to vibration or chock. The RPi is secured by the 40-pin header as well as being fixed between the A314 PCB and the Amiga keyboard backplate. The connector isolator which you see in the picture you linked to (the white TPU strip on top of the RPi GPIO connector) makes contact with said backplate. There is just no room for lateral movement.
3) Further, the RPi lays with its video and audio connectors resting on top of the trapdoor side ledge, providing excellent support for the board. The only situation where this could be a possible issue, is if you were to use your Amiga upside-down. I'd say that is a an edge-case scenario...
I hope this eases your worries about the mechanical aspects of the A314 construction.

prgp, 2020-12-24:
I just saw the reverse of the board on Ebay and noticed that one of the distance standoff holes would have in the same location as the CP2032 battery holder, so that one is definitely not practical :-D

I assume that whilst a Raspberry Pi Zero would not suffer from the same level mechanical stress as a full sized model, but it would also not benefit from the video and audio connectors positioning - looking at the current design it would also put a hole rather close to IC4 (SRAM) and that is impractical to move.

What are the expected height specifications for the GPIO socket and pin headers (I assume that the pins are assumed to add little to no separation, so something like [this header](https://thepihut.com/products/colour-coded-gpio-headers) would cause issues) ?

Eriond, 2020-12-24:
We have based the design upon the RPi 3 as it is supplied by the RPF. For that model (and compatible ones), you will find the appropriate header component listed in the BOM.

Closed 2024-05-21.

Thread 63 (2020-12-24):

Raspberry Pi Compatibility

prgp, 2020-12-24:
I checked the wiki and was not able to locate a Raspberry Pi compatibility list.

As I understand it the Raspberry Pi is drawing power via the A500's trapdoor - what are the draw limits that this imposes on the Rapsberry Pi ? (a Zero has a maximum draw of about 300 mA and a Model 2B has a maximum draw of about 820 mA, but a model 4B has a maximum draw of about 1250 mA)

Would it be possible to add to the wiki which Raspberry Pi models have been used successfully.

alestanga, 2020-12-30:
I'm using a RPi 2B in my Amiga 500 and it works flawlessly, well, if you don't mind the absence of WiFi.
ethernet works just fine though.

Eriond, 2020-12-30:
compatibility list added. Issue may be closed.

Closed 2021-02-09.

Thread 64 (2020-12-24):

Automatic Pi Shutdown

prgp, 2020-12-24:
The wiki suggests that before you power off the Amiga that

> Before powering off your Amiga you should do `pi sudo shutdown now` and wait a few seconds to let the Raspberry shutdown properly.

Would it be possible to have power loss on the Amiga trigger a safe shutdown on the Raspberry Pi ?

I have seen Raspberry Pi projects that have used 'soft power' buttons connected to he GPIO to trigger a safe shutdown, but there would still need to be power to facilitate the shutdown (other projects such as [this](https://www.sensorsiot.org/safe-shutdown-for-raspberry-pi-with-super-capacitors-133/) appear to provide this, but the capacitors seem a little large for that purpose - 2A @ 5V for 5s should need only about 2F unless my maths is way off and much less than that for a Zero).

This could be implemented as an optional 'sister-board` to the Raspberry Pi thus allowing the rating (or inclusion) to be determined by the person attaching the Raspberry Pi.  The board probably would not need that many pins - Vin and Vout, GND and the control ('shutdown') line.

Eriond, 2020-12-24:
I suggest this is linked with issue #16

prgp, 2020-12-25:
I looked at the open and closed issues to see if it had been suggested, some how completely missing #16 ...

The only issue that I could see and could not come up with a simple solution for was if the PSU power-cycles too quickly then the shutdown could complete after power has been restored which means that the Raspberry Pi would not turn on again.

Maybe some sort of timer / latch that begins on power loss and should not complete unless power is returned too soon then interrupt the power, but this feels kludgey to me - the grounding RUN (via resistor for safety) reset method seems to rely on pogo pins or modifying the Raspberry Pi.  Also the Zero,  model 3 and model 4 do no have RUN in the same location so pogos are probably doubly out.

Closed 2020-12-25.

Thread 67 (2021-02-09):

Change to Compute Module instead of RPI GPIO Header

ryanm101, 2021-02-09:
I was thinking that if the compute module was used it might provide for neater installation and it might also allow full size rpi to fit in the A600.

Key issue I see is that there is now CM3 and CM4 which use a different connector and it might mean seperate board layouts for each due to them being very different.
https://www.raspberrypi.org/documentation/hardware/computemodule/datasheet.md

This would also mean that if required things like ethernet connector could be offloaded to the A314 pcb

niklasekstrom, 2021-02-09:
The issue of using CM3 (or not) for the A314-600 version has been discussed a few times, see for example the discussion in issue #18. I think it comes down to the price of adding back the components that are missing on the CM3 (compared to the full Pi 3B+), and the work to redesign the board. If you are interested in taking on this work then definitively let us know, as it would be nice to have the power of the Pi 3 in the smaller form factor.

Closed 2021-02-09.

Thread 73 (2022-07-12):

Installation instructions miss out a step

Fastdruid, 2022-07-12:
On the software instructions it states to run
./rpi_docker_build.sh

If you follow the instructions exactly, this errors with
```
RPi:~/a314/Software $ ./rpi_docker_build.sh
docker: Got permission denied while trying to connect to the Docker daemon socket at unix:///var/run/docker.sock: Post "http://%2Fvar%2Frun%2Fdocker.sock/v1.24/containers/create": dial unix /var/run/docker.sock: connect: permission denied.
See 'docker run --help'.
FATAL ERROR: Couldn't open output file bin/spi-a314.dtbo: No such file or directory
chown: cannot access 'bin': No such file or directory
```
You need to log out and back in again to pick up the permissions that you granted in one of the previous steps ( sudo usermod -aG docker pi), once you have done this the build will then work.

Closed 2022-09-26.

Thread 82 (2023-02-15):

A314cp problems using a Pi4 or CM4 under emu68 (PiStorm/PiStorm32 Lite)

katzazakis, 2023-02-15:
Using a Pi4 or CM4 (both versions) with a PiStorm or PiStorm32 under emu68 unfortunately makes the A314 clockport version unusable. All inputs, e.g. in the shell, are processed at a snail's pace and sometimes require multiple calls. It was tested on A500 with Lazarustorm and Clockport Adapter on the 68k socket and CM4 Lite/CM4 EMMC, second test with PiStorm32 Lite and Raspberry Pi4.
No problem using a Raspberry 3A+ on either configuration.

niklasekstrom, 2023-10-01:
I was told that this issue has been fixed by an update to Emu68.

Closed 2023-10-01.

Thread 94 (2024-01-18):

`Unable to connect to picmd service` / `Unable to open a314.device` on A1200 with clockport if

gmcn42, 2024-01-18:
Hi there,

I am trying to set up the clockport version of A314 with no luck so far. I got the hardware from a nice person on Discord who seemed to know what he was doing and tested it thoroughly before sending it to me, so here's hoping it's not a hw fault.

# What I did

1. Installed everything in the Amiga, the Pi with a pre-setup SD card
2. Boot amiga, connect to raspi via ssh
3. follow raspi-side installation instructions from latest `main` and reboot. systemd reports:
```
sudo service a314d status
● a314d.service - A314 Daemon
     Loaded: loaded (/lib/systemd/system/a314d.service; enabled; vendor preset: enabled)
     Active: active (running) since Thu 2024-01-18 23:30:40 CET; 3min 14s ago
    Process: 504 ExecStartPre=/opt/a314/start_gpclk (code=exited, status=0/SUCCESS)
   Main PID: 513 (a314d)
      Tasks: 1 (limit: 421)
        CPU: 41ms
     CGroup: /system.slice/a314d.service
             └─513 /opt/a314/a314d

Jan 18 23:30:40 a314-1200 systemd[1]: Starting A314 Daemon...
Jan 18 23:30:40 a314-1200 start_gpclk[504]: Starting GPCLK0 with frequency=85 (requested=90), divisor=14
Jan 18 23:30:40 a314-1200 systemd[1]: Started A314 Daemon
```
4. copied over the Amiga binaries using ADF opus and FlashFloppy
5.  Copied everything from virtual floppy to hard disk using DOpus 4
6.  rename a314-cp.device to a314.device, delete -fe and -td devices
7. Try out `pi` command
```
Unable to connect to picmd service
```

# What I already tried

1. Re-flashing the CPLD using openFPGALoader and the v1.1 firmware blob available in the clockport_interface repo
    - openFPGALoader takes a long time to flash (minutes) but reports success
    - a314d is fine after reboot
    - still same error
2. Using a314d from 1.2.2 tag instead of main to match amiga binary versions
    - now I am getting a few seconds of wait after typing `pi`, and then `Unable to open a314.device`
3. reseating the module on the clockport header multiple times
    - no effect

# Ideas

* While the Pi side seems to have a good connection to the cpld, I am unsure about the Amiga side. Is there any way to get more verbose output and/or check if the CPLD is present without actually trying to connect to the Pi?

gmcn42, 2024-01-19:
Additional info: For flashing I used the instructions at https://github.com/katzazakis/A314cp-SD-brew/wiki/How-to-flash-your-A314cp with the JED file https://github.com/niklasekstrom/clockport_pi_interface/releases/download/v1.1/cp_pi_if.jed

The board is the original design, not the eriond one and carrying a Pi 3A+

niklasekstrom, 2024-01-19:
Hi,

If you are following instructions other than the ones given in this repo (or the clockport_pi_interface repo) then you need to ask whoever wrote those instructions if they are not working.

In general, if you are buying a board that someone else built, then the person who built that board should flash it and test it, and you should not need to flash it again. Please don't flash a working board.

gmcn42, 2024-01-19:
Alright, two remaining questions then:

1. For debugging: Does `Unable to connect to picmd service` imply the CPLD was reachable but not the Pi? Does `Unable to open a314.device` mean it can't reach the CPLD?

2. Regarding flashing instructions: Are there official ones? In the clockport-interface repo I am only seeing build instructions but nothing related to flashing the CPLD

niklasekstrom, 2024-01-19:
2. If you didn't build the board then you shouldn't have to flash the cpld. If you are building boards then likely you can figure out how to flash the cpld, or you can come to the Discord server to ask how to do it.

1. Unable to open a314.device typically means that the Amiga side is unable to communicate with the cpld. This can happen for several reasons, such as software configuration/versioning issues.

Feel free to ask more questions in the Discord server.

Closed 2024-01-19.

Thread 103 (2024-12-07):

Failed pi install

SanguineBrah, 2024-12-07:
I had a working system but messed up my pi install and had to rebuild again, so I followed the instructions in the software directory again. I'm using the trapdoor variant.

The pi command works on the Amiga side but the SANA driver no longer works. This is the log from systemctl (a314d)

Dec 07 17:29:51 a314 systemd[1]: Started a314d.service - A314 Daemon.
Dec 07 17:29:52 a314 a314d[541]: ERROR, 2024-12-07 17:29:52,646, __main__, line 218: Unable to open tap device at tap0
Dec 07 17:29:52 a314 a314d[541]: Traceback (most recent call last):
Dec 07 17:29:52 a314 a314d[541]:   File "/opt/a314/ethernet.py", line 263, in <module>
Dec 07 17:29:52 a314 a314d[541]:     tap.close()
Dec 07 17:29:52 a314 a314d[541]:     ^^^
Dec 07 17:29:52 a314 a314d[541]: NameError: name 'tap' is not defined. Did you mean: 'map'?

ifconfig does not list any tun0 inferface

This is the output from the install script:

g++ -DMODEL_TD=1 a314d/a314d.cc -O3 -o bin_pi/a314d-td
dtc -I dts -O dtb -o bin_pi/spi-a314.dtbo a314d/spi-a314-overlay.dts
created virtual environment CPython3.11.2.final.0-64 in 1570ms
  creator CPython3Posix(dest=/opt/a314/venv, clear=False, no_vcs_ignore=False, global=False)
  seeder FromAppData(download=False, pip=bundle, setuptools=bundle, wheel=bundle, via=copy, app_data_dir=/root/.local/share/virtualenv)
    added seed packages: pip==23.0.1, setuptools==66.1.1, wheel==0.38.4
  activators BashActivator,CShellActivator,FishActivator,NushellActivator,PowerShellActivator,PythonActivator
Looking in indexes: https://pypi.org/simple, https://www.piwheels.org/simple
Processing ./bpls2gif
  Preparing metadata (setup.py) ... done
WARNING: Retrying (Retry(total=4, connect=None, read=None, redirect=None, status=None)) after connection broken by 'NewConnectionError('<pip._vendor.urllib3.connection.HTTPSConnection object at 0x7f8289c9d0>: Failed to establish a new connection: [Errno -3] Temporary failure in name resolution')': /simple/pyudev/
Collecting pyudev
  Downloading https://www.piwheels.org/simple/pyudev/pyudev-0.24.3-py3-none-any.whl (62 kB)
     ━━━━━━━━━━━━━━━━━━━━━━━━━━━━━━━━━━━━━━━━ 62.8/62.8 kB 67.9 kB/s eta 0:00:00
Collecting websockets
  Downloading websockets-14.1-cp311-cp311-manylinux_2_17_aarch64.manylinux2014_aarch64.whl (169 kB)
     ━━━━━━━━━━━━━━━━━━━━━━━━━━━━━━━━━━━━━━━━ 169.4/169.4 kB 937.9 kB/s eta 0:00:00
Collecting python-pytun
  Downloading python-pytun-2.4.1.tar.gz (8.5 kB)
  Preparing metadata (setup.py) ... done
Building wheels for collected packages: python-pytun, bpls2gif
  Building wheel for python-pytun (setup.py) ... done
  Created wheel for python-pytun: filename=python_pytun-2.4.1-cp311-cp311-linux_aarch64.whl size=28170 sha256=f464f5e52f9bfd8bc69dbb53358c1d3ebc55e5ae5d0a42838aa9b2f43c9fe280
  Stored in directory: /root/.cache/pip/wheels/96/05/30/49ad90b4a08cc1fd6a875874f2c3f11b1650ae00ed279bec7b
  Building wheel for bpls2gif (setup.py) ... done
  Created wheel for bpls2gif: filename=bpls2gif-1.0-cp311-cp311-linux_aarch64.whl size=14423 sha256=ad20d7f726fd1cd9727d2b2126be862a66ae036d93bd565c9917617ea30727e2
  Stored in directory: /tmp/pip-ephem-wheel-cache-yv0ws32i/wheels/3f/57/8a/5111eee2bf6156a17289951e2ecf8e60a4b4678cf303d0402c
Successfully built python-pytun bpls2gif
Installing collected packages: python-pytun, bpls2gif, websockets, pyudev
Successfully installed bpls2gif-1.0 python-pytun-2.4.1 pyudev-0.24.3 websockets-14.1
./install-pi.sh: line 15: /etc/network/interfaces.d/tap0: No such file or directory
Created symlink /etc/systemd/system/multi-user.target.wants/a314d.service → /lib/systemd/system/a314d.service.
Created symlink /etc/systemd/system/multi-user.target.wants/a314net.service → /lib/systemd/system/a314net.service.

Installation complete
Restart the Raspberry Pi (sudo reboot now) to automatically start a314 software

niklasekstrom, 2024-12-08:
Hi, can you try running the script again? It looks in the output like the network connection was broken at some point, so something was likely not downloaded properly.

SanguineBrah, 2024-12-08:
I just redid everything from scratch - reimaged the SD card using raspberry pi imager to Lite 64bit then followed the instructions exactly. This is the output from the script:

g++ -DMODEL_TD=1 a314d/a314d.cc -O3 -o bin_pi/a314d-td
dtc -I dts -O dtb -o bin_pi/spi-a314.dtbo a314d/spi-a314-overlay.dts
created virtual environment CPython3.11.2.final.0-64 in 1567ms
  creator CPython3Posix(dest=/opt/a314/venv, clear=False, no_vcs_ignore=False, global=False)
  seeder FromAppData(download=False, pip=bundle, setuptools=bundle, wheel=bundle, via=copy, app_data_dir=/root/.local/share/virtualenv)
    added seed packages: pip==23.0.1, setuptools==66.1.1, wheel==0.38.4
  activators BashActivator,CShellActivator,FishActivator,NushellActivator,PowerShellActivator,PythonActivator
Looking in indexes: https://pypi.org/simple, https://www.piwheels.org/simple
Processing ./bpls2gif
  Preparing metadata (setup.py) ... done
Collecting pyudev
  Downloading https://www.piwheels.org/simple/pyudev/pyudev-0.24.3-py3-none-any.whl (62 kB)
     ━━━━━━━━━━━━━━━━━━━━━━━━━━━━━━━━━━━━━━━━ 62.8/62.8 kB 813.9 kB/s eta 0:00:00
Collecting websockets
  Downloading websockets-14.1-cp311-cp311-manylinux_2_17_aarch64.manylinux2014_aarch64.whl (169 kB)
     ━━━━━━━━━━━━━━━━━━━━━━━━━━━━━━━━━━━━━━━━ 169.4/169.4 kB 1.0 MB/s eta 0:00:00
Collecting python-pytun
  Downloading python-pytun-2.4.1.tar.gz (8.5 kB)
  Preparing metadata (setup.py) ... done
Building wheels for collected packages: python-pytun, bpls2gif
  Building wheel for python-pytun (setup.py) ... done
  Created wheel for python-pytun: filename=python_pytun-2.4.1-cp311-cp311-linux_aarch64.whl size=28169 sha256=e1e687cdfea72a4f2700c0ba30bd2b5158a377ae472413569453d177e58354e0
  Stored in directory: /root/.cache/pip/wheels/96/05/30/49ad90b4a08cc1fd6a875874f2c3f11b1650ae00ed279bec7b
  Building wheel for bpls2gif (setup.py) ... done
  Created wheel for bpls2gif: filename=bpls2gif-1.0-cp311-cp311-linux_aarch64.whl size=14423 sha256=ed922da99e6e219d2fbb2c14e0b1362e6cdf9cd16388f99a32e517a63485fd18
  Stored in directory: /tmp/pip-ephem-wheel-cache-umiecv69/wheels/3f/57/8a/5111eee2bf6156a17289951e2ecf8e60a4b4678cf303d0402c
Successfully built python-pytun bpls2gif
Installing collected packages: python-pytun, bpls2gif, websockets, pyudev
Successfully installed bpls2gif-1.0 python-pytun-2.4.1 pyudev-0.24.3 websockets-14.1
./install-pi.sh: line 15: /etc/network/interfaces.d/tap0: No such file or directory
Created symlink /etc/systemd/system/multi-user.target.wants/a314d.service → /lib/systemd/system/a314d.service.
Created symlink /etc/systemd/system/multi-user.target.wants/a314net.service → /lib/systemd/system/a314net.service.

Installation complete
Restart the Raspberry Pi (sudo reboot now) to automatically start a314 software

The SANA driver still fails; it seems like the line to add the tap0 inferface didn't do anything. There is no inferfaces.d in /etc/network

niklasekstrom, 2024-12-08:
In https://downloads.raspberrypi.com/raspios_lite_armhf/release_notes.txt it says " * Removed ifupdown from default install as it is not used and slows down boot", maybe this is the problem.

If you do `sudo apt install ifupdown`, and then run install-pi.sh again, does that help?

If you have a Discord account you could join the A314 discord server (link on https://github.com/niklasekstrom/a314?tab=readme-ov-file#do-you-want-to-get-involved) to get help more interactively.

SanguineBrah, 2024-12-08:
Installing ifupdown did the trick. Looks like it just needs adding to the dependencies in the install instructions.

niklasekstrom, 2024-12-08:
Ok great, thanks for reporting the issue!

If you know of some better way to configure the tap interface (than the current method) then feel free to drop by the discord server and let us know. Otherwise I'll add the ifupdown package to the dependencies in the install instructions.

Closed 2024-12-08.

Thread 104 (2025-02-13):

next adaptor

alow2004, 2025-02-13:
Hello,
Would you agree to develop such a solution for the next computer ? It's the same processor family as the Amiga (68040), but using nextstep as operating system. A think it could be feasible to adapt the 'amiga' part for another 68K computer. If you agreed, I could send you a next station so you could develop the prototype ?
What is your advice about that? Thanks for your response. And sorry using the issue channel, but it was the only way I found to contact you. best regards.

cnilsson, 2025-02-13:
What kind of functionality would you like to add to NextStep? Sure there may be  some niche use cases, but I am having a hard time seeing what features you are looking for, at least among the most commonly used a314 ones.

It is a unix system after all so if you want a shell on a Pi you are better off using ssh. You also already have access to file sharing such as NFS or SMB over ethernet. Storage, well I assume you need a disk (or SCSI emulator) anyway for the OS so no need for that. Audio - possibly better DAC on the Next than a Pi. Well it won't do Spotify if that is what you are after but you can ssh to another machine and get Spotify with GUI and everything over X.

Also, check the discord link for a better way to discuss with Niklas and others.

alow2004, 2025-02-13:
Hello, thank you for your response,
Well, first of all, we don’t have direct wi-fi functionalities available for Next, the nextbus, that is an avatar of Mac’s nubus is not so easy to interface because next used proprietary asics to manage
The protocol, and those ic’s are now rare to find, so I was thinking of a more simplified interface based on the 314-cp (clockport), after all, it’s only 8 bits data bus, some address lines, rw signals and one interrupt…
There is a signal processor available on the Next (DSP 56001) that could lead also to ’funny’ usage. The fs utilities because actually, next is based on scsi disk and let’s say it frankly, it could be very handy
To have the Raspberry pi totally integrated into the next box in place of juggling with external links, external computers etc…
By example, I also follow-up the pistorm project, actually, it’s not really useful because next are natively equipped by 68040 processors, but it’s only at 25 MHz, there is no accelerator available anymore, so I bet that
If the pistorm project continue its evolution (maybe using RPI5 ?), it would become a very attractive solution for next community if an adaptor is available in 68040 socket format...

Have anice day!

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

niklasekstrom, 2025-02-15:
Hi @alow2004,

Does the next station has some connector that would be suitable to connect it to a Raspberry Pi, possibly with a cpld/fpga in between?

alow2004, 2025-02-16:
Well, there is the NextBus, as said, it is the same as a Mac Nubus, but supporting twice the speed (20 MHz), the protocol is nubus Texas instrument based. But other than that, the only way I see is
Pluggin into the processor socket or the high speed serial links of the 56002 DSP processor

You can find the nextbus specs in attachment.

https://www.nextcomputers.org/NeXTfiles/Docs/Hardware/NeXTbus-NBIC/NeXTbus_Specification.pdf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

> Le 15 févr. 2025 à 23:51, Niklas Ekström ***@***.***> a écrit :
>
> Does
￼

niklasekstrom, 2025-02-16:
Building a hardware adapter that sits between the NextBus and a Raspberry Pi is likely possible, but it would be a significant effort. It requires designing and building hardware, writing and debugging FPGA logic, and writing and debugging software. As I don't have a NextStation (and never had), I don't have sufficient incentives to spend that effort.

One much simpler possibility might be if you connect the NextStation and the Pi together through a serial cable, and run some software (PPP?) that lets the NextStation use the Pi's network interface.

alow2004, 2025-02-16:
Yes, you advice is valuable in that sense, I think what I will do is also checking on the MAC community because as is said, NextBus is a direct ’successor’ of the Nubus standard for Mac,
And there were a lot of accelerators for the Mac at the time, I will try to check how they handle the protocols and see if there are opportunities.
Thanks for you help and advices, have a nice day!

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

Closed 2025-02-17.

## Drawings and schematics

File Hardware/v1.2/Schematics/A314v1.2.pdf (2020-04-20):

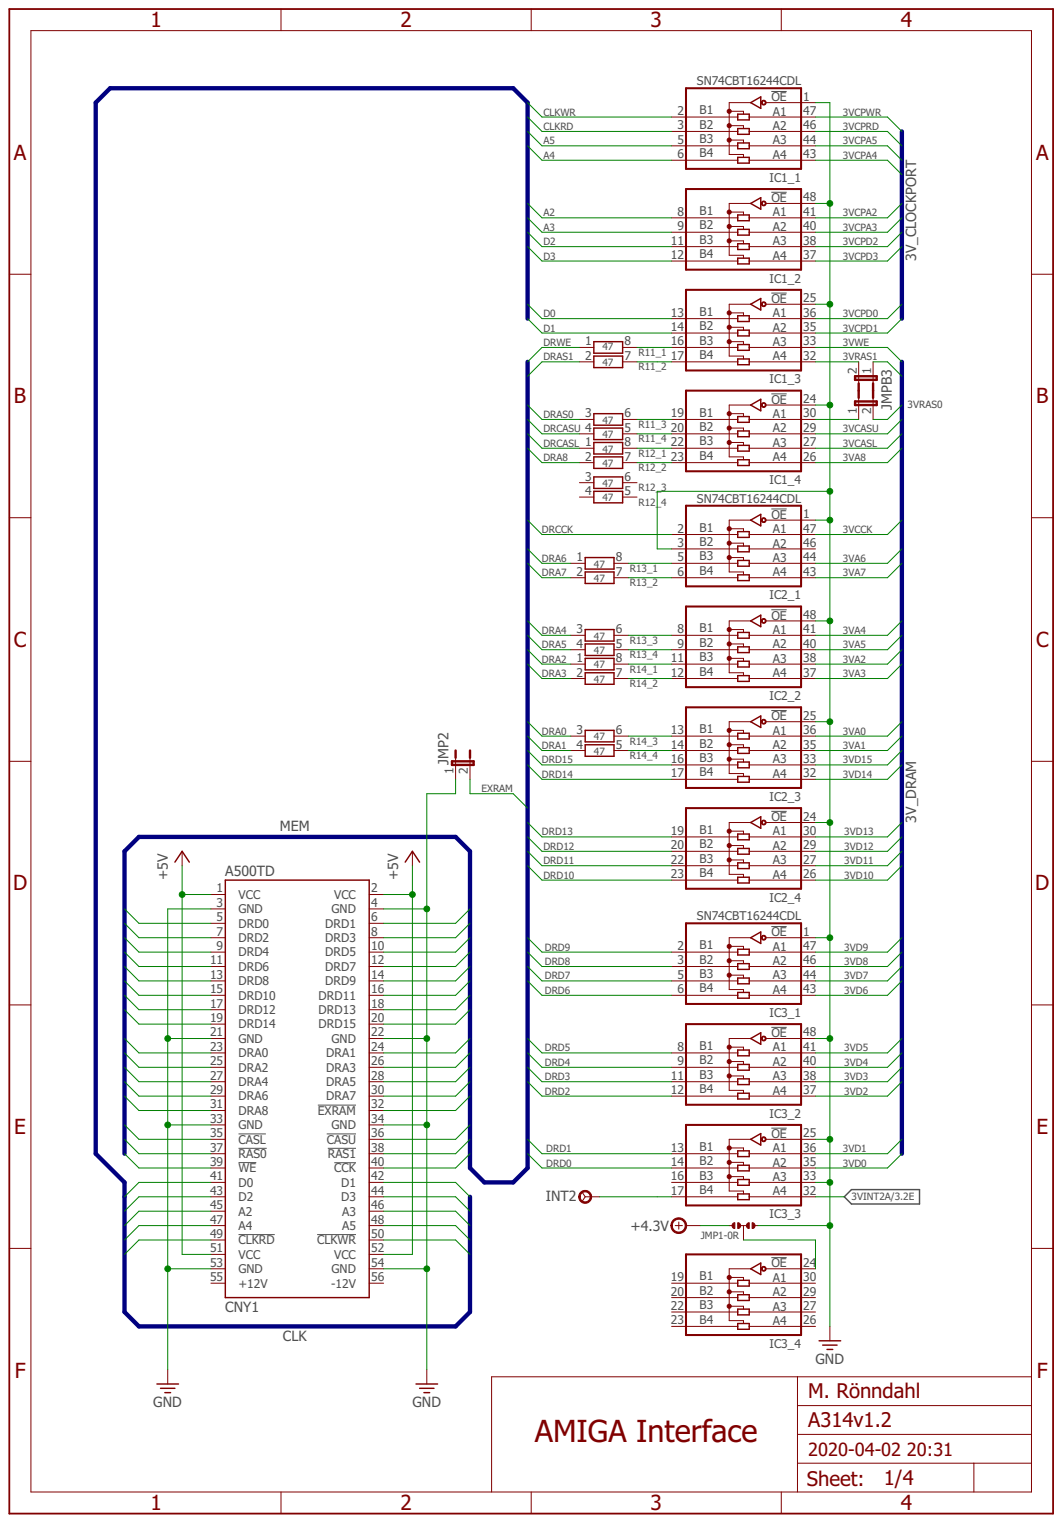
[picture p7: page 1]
A4 A500TD GND; GND ⁺⁵V; SN74CBT16244CDL SN74CBT16244CDL SN74CBT16244CDL; GND ⁺4.3V VCC 1; GND 3; DRD0 5; DRD2 7; DRD4 9; DRD8 13; DRD6 11; DRD10 15; DRD12 17; DRD14 19; DRA0 23; DRA2 25; GND 21; DRA4 27; DRA6 29; DRA8 31; GND 33; CASL 35; RAS0 37; VCC; 2 GND; 4 DRD1; 6 DRD3; 8 DRD5; 10 DRD7; 12 DRD9; 14 DRD11; 16 DRD15; 20 GND; 22 DRD13; 18 DRA1; 24 DRA3; 26 DRA7; 30 DRA5; 28 EXRAM; 32 CASU; 36 GND; 34 RAS1; 38 CCK; CLKRD 49; VCC 51; GND 53; 56 GND; 48 CLKWR; 50 VCC; 52 CNY1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

A

A

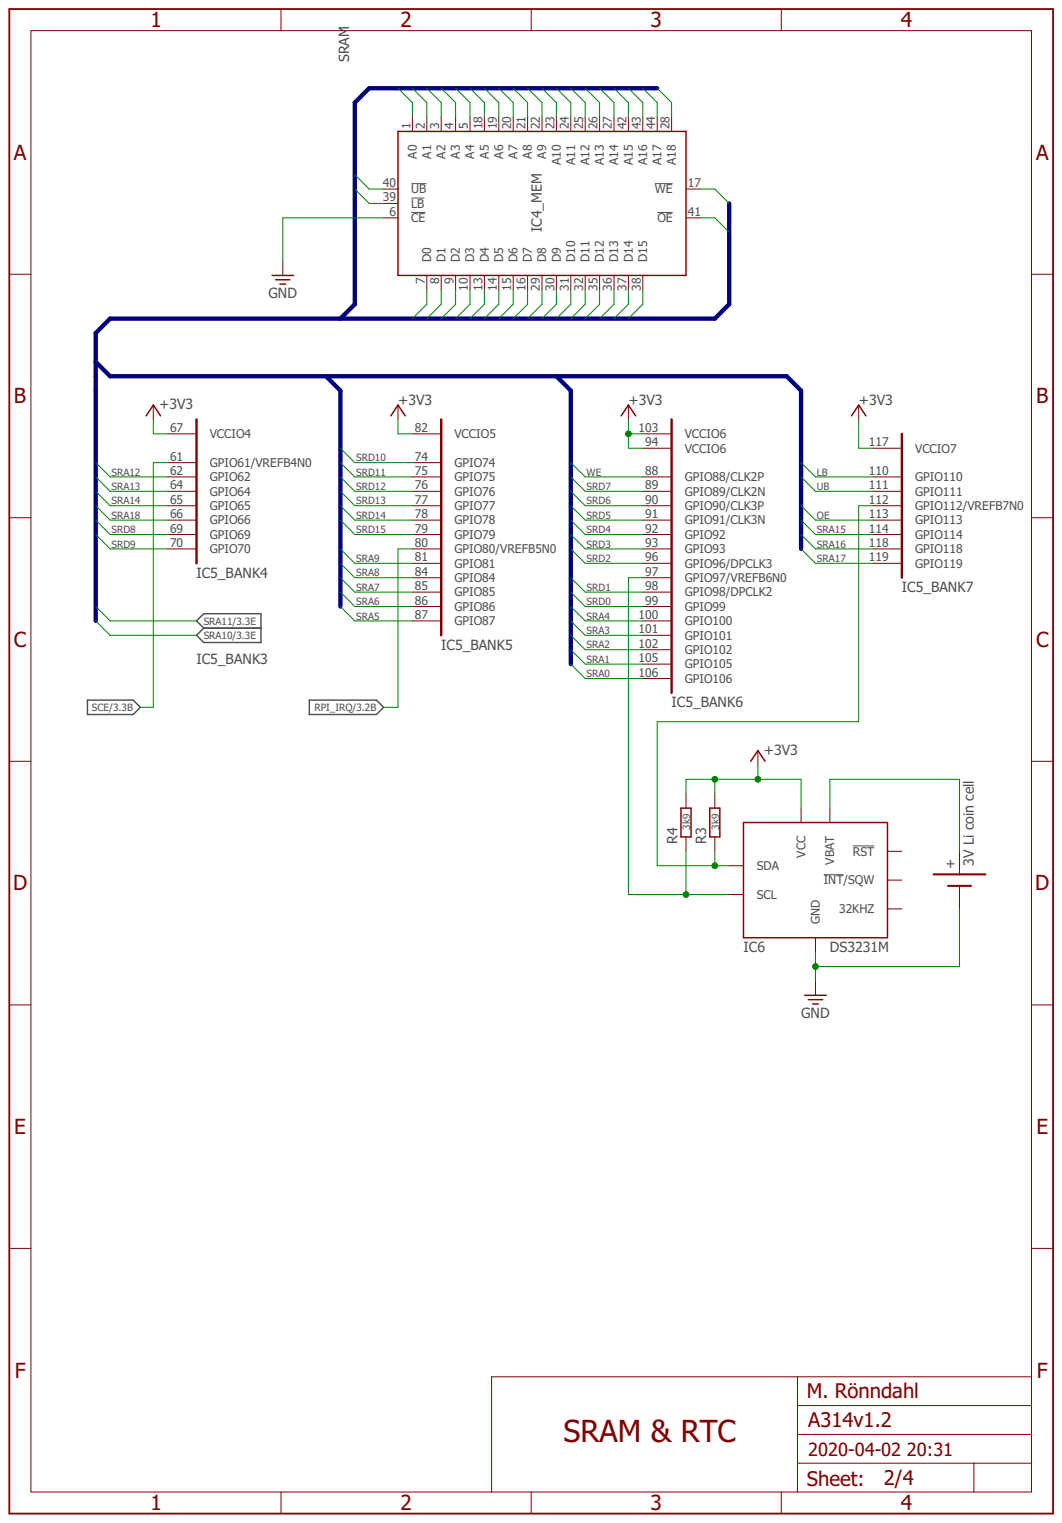
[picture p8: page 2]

A

A

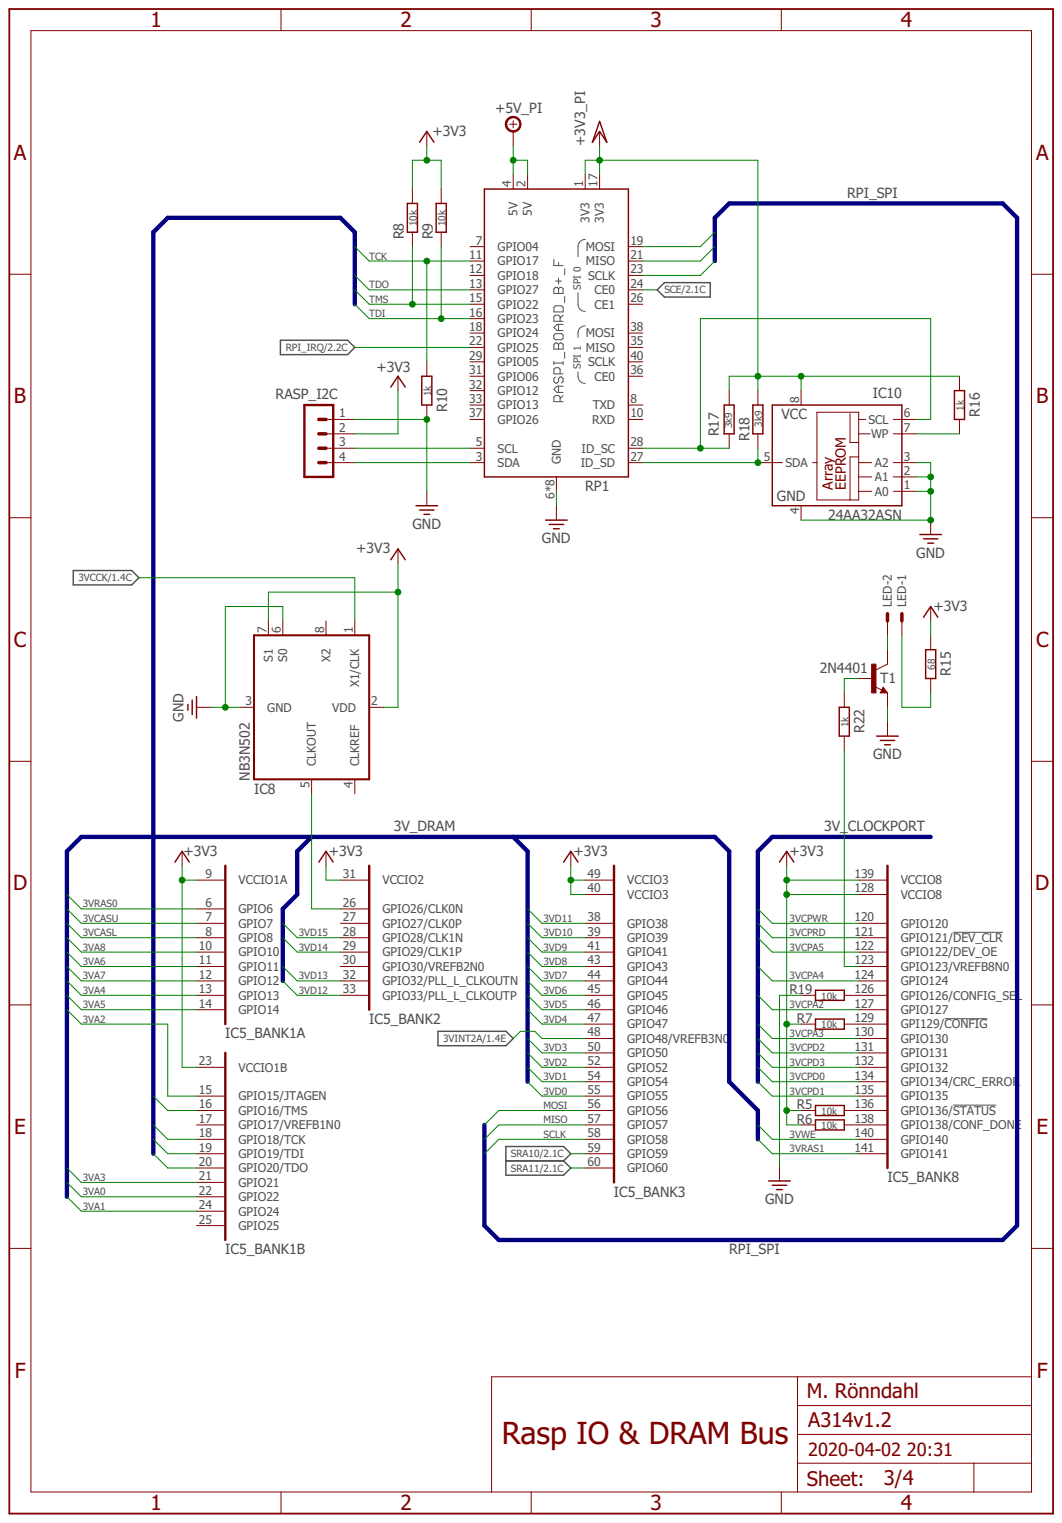
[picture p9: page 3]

3VCPWR | 120
3VCPRD

3VCPA3 | 10k | 130

Rasp IO & DRAM Bus

IC6 IC8 IC4 IC4 IC10 IC8 3.3V Regulator 4.3V Regulator 5.15V Regulator Measuring points are pins 2 & 4 of GPIO header GND 3V3 + 3V3 + 3V3 + V5 + +4.3V GND 100n k43 2k01 100n 2.2uH 22u 22u 22u 3V3 +V3. 4 + 100n 100n 100n 100n 100n 100n 100n 100n 100n 100n 100n 100n 100n 100n 100n 100n 100n 100n 100n 100n 100n 100n 100n 100n 100n 100n 100n 100n 100n 100n 33u 33u 33u 33u 100n 100n 100n 3V3 + +4.3V 10M08SCE144 GND TPS77033 100n 100n 100n 2/ CCV100n GND V5 + 1uH V5 + 100n 22u TPS63020DSJR GND 33 M1 k341 22u 22u 22u +5V_PI 100n 100n DNG 1 VIN 3 VFB 4 SW 2 VBST 6 NE 5 IC7 C4 2R 1RC3 1 2 L2 C2 C5 C6 C11 C12 C13 C14 C55 C56 C21 C22 C57 C58 C41 C59 C60 C61 C62 C63 C64 C65 C66 C67 C68 C69 C70 C71 C72 C23 C24 C31 C42 C54 C50 C51 C52 C53 C32 C33 C34 DNG 4 CCV 7 CCV 81 CCV 13 CCV 24 DNG 01 DNG 51 DNG 12 DNG 82 DNG 43 DNG 93 DNG 54 DNG 4 CCV 7 CCV 81 CCV 13 CCV 24 DNG 01 DNG 51 DNG 12 DNG 82 DNG 43 DNG 93 DNG 54 DNG 4 CCV 7 CCV 81 CCV 13 CCV 24 DNG 01 DNG 51 DNG 12 DNG 82 DNG 43 DNG 93 DNG 54 CCV 1 1ACCV 53 DNG 3 DNG 4 DNG 24 DNG 35 DNG 36 DNG 86 DNG 38 DNG 401 DNG 59 DNG 611 DNG 521 DNG 331 DNG 731 DNG 241 CCV 63 CCV 73 CCV 15 CCV 27 CCV 37 CCV 801 CCV 901 CCV 511 CCV 441 2ACCV 43 3ACCV 5 4ACCV 341 5ACCV 17 6ACCV 2 3ACCV 701 R WP_5CI PG 5*4 @BG DNG 21 DNG 43 DDV 33 DDV 11 IC4_PWR IN 1 EN 3 NC/FB 4 OUT 5 GND 2 IC9 C1 C7 C8 5V 3V3 4V3 GND C9 L1 C15 C16 EN 12 FB 3 1L 2*8 2L 2*6 PS/SYNC 13 VIN 10*2 VINA 1 DAPE 6*51 PG 14 VOUT 4*2 DNG 2 IC11 12R 02R C10 C17 C18 C19 C20 Power & Decoupling M. Rönndahl A314v1.2 2020-04-02 20:31 4/4 Sheet: ABCDE 1 2 3 4 5 6 7 8 ABCDE 1 2 3 4 5 6 7 8

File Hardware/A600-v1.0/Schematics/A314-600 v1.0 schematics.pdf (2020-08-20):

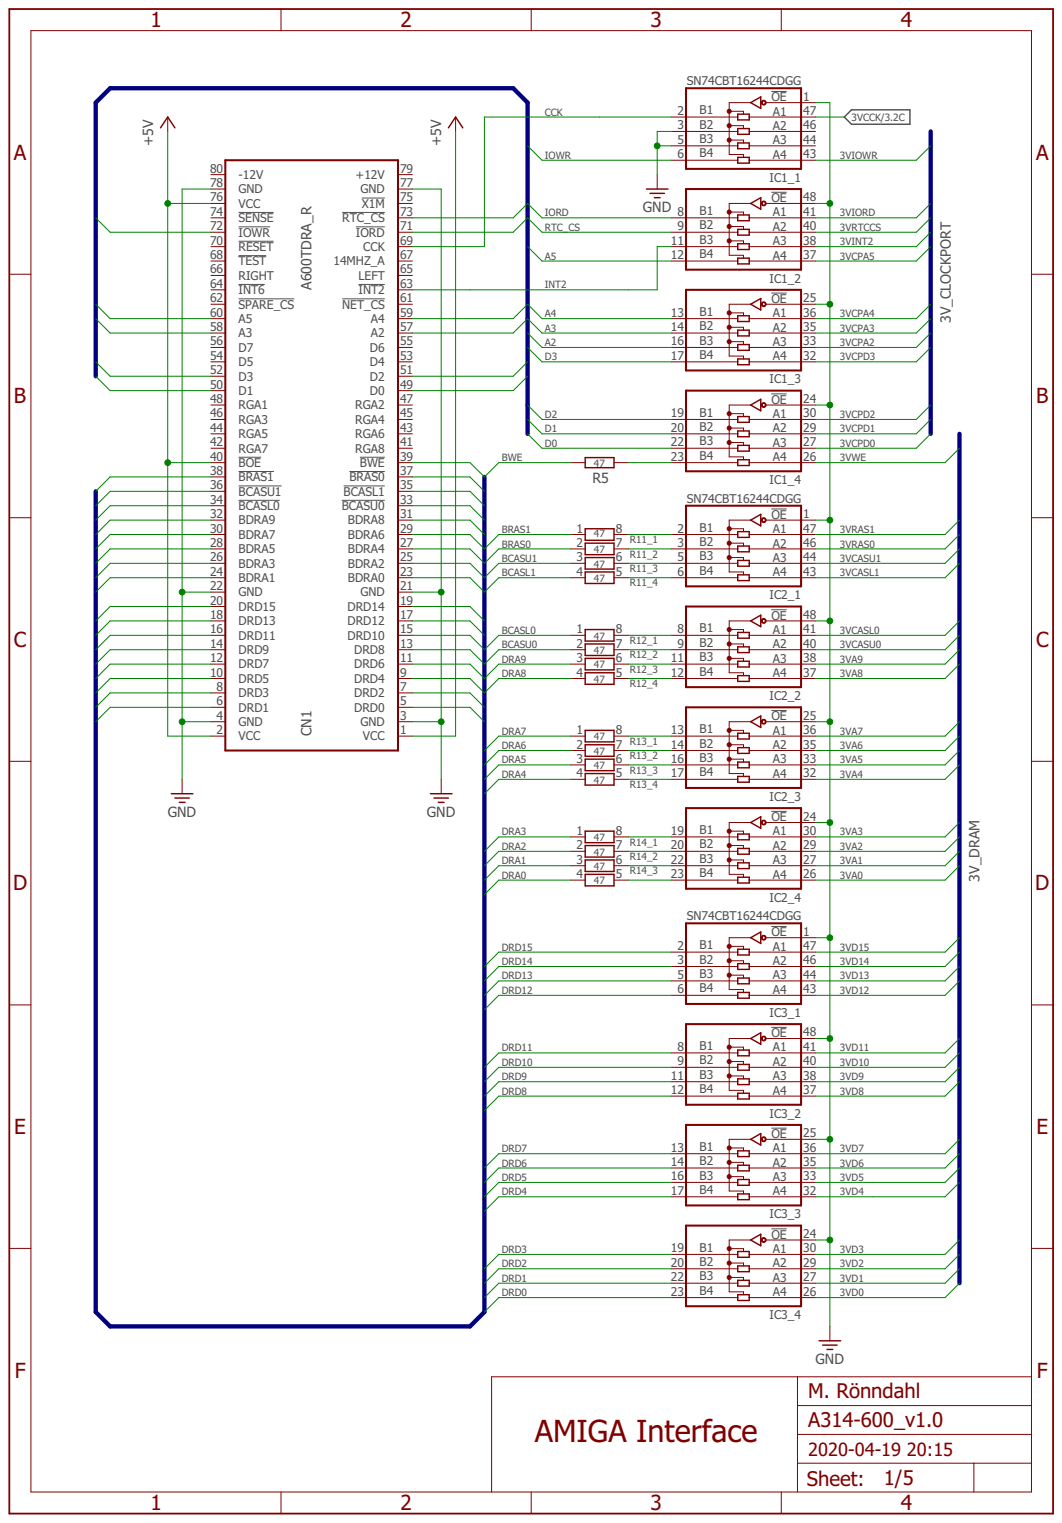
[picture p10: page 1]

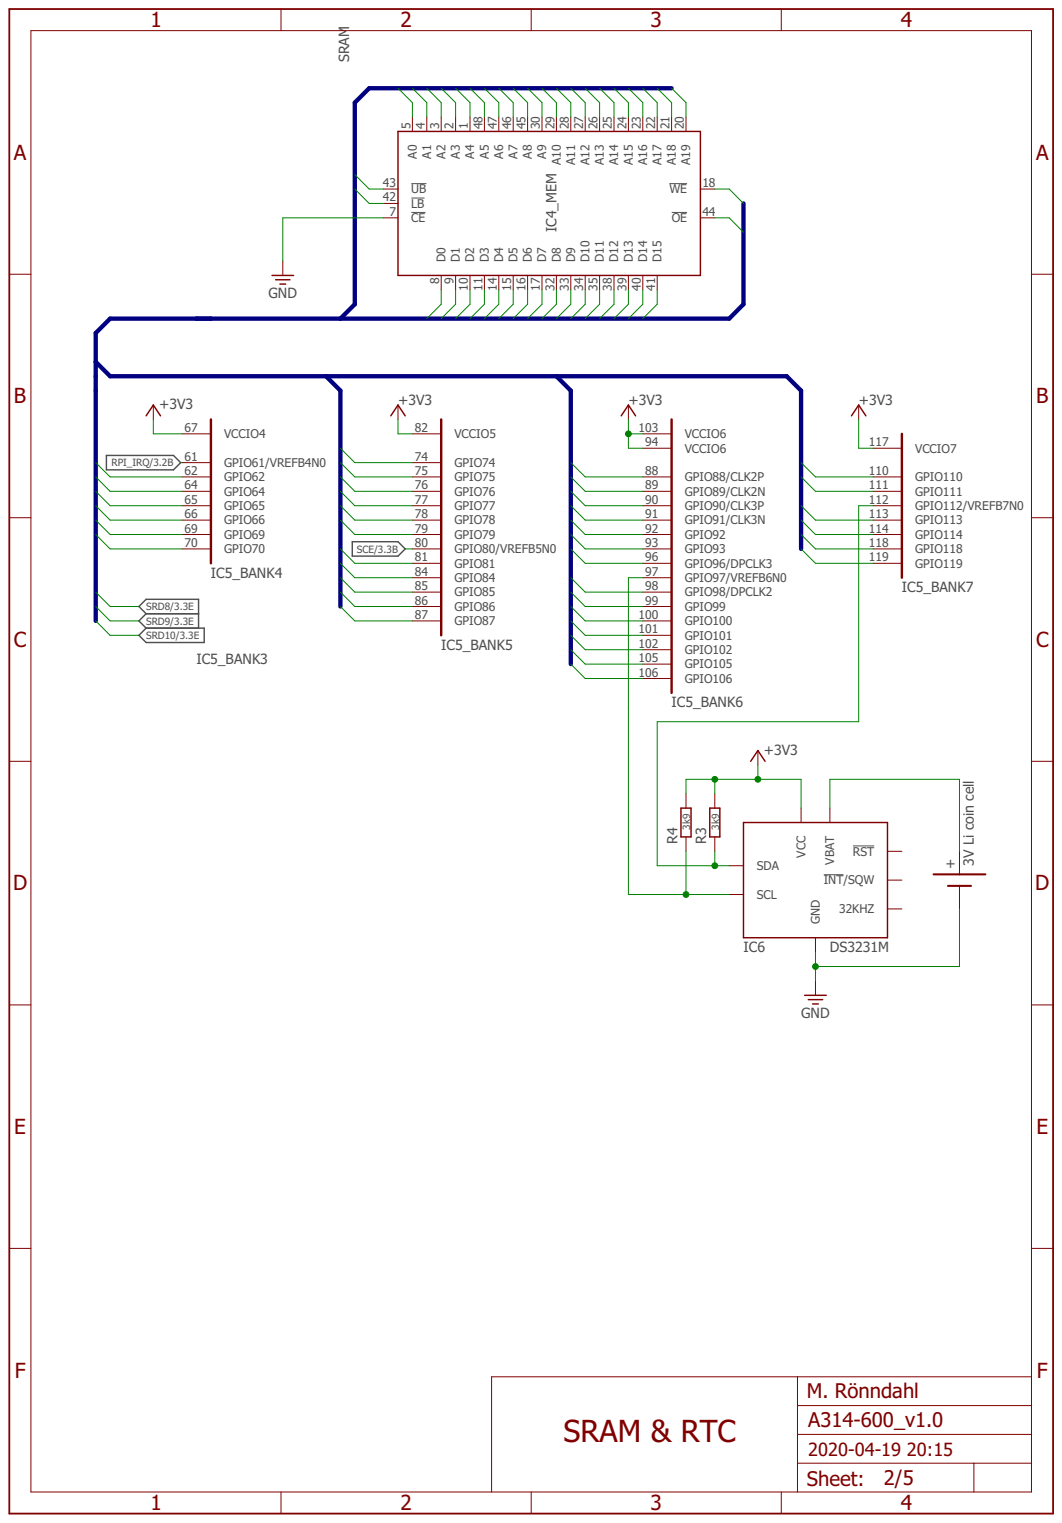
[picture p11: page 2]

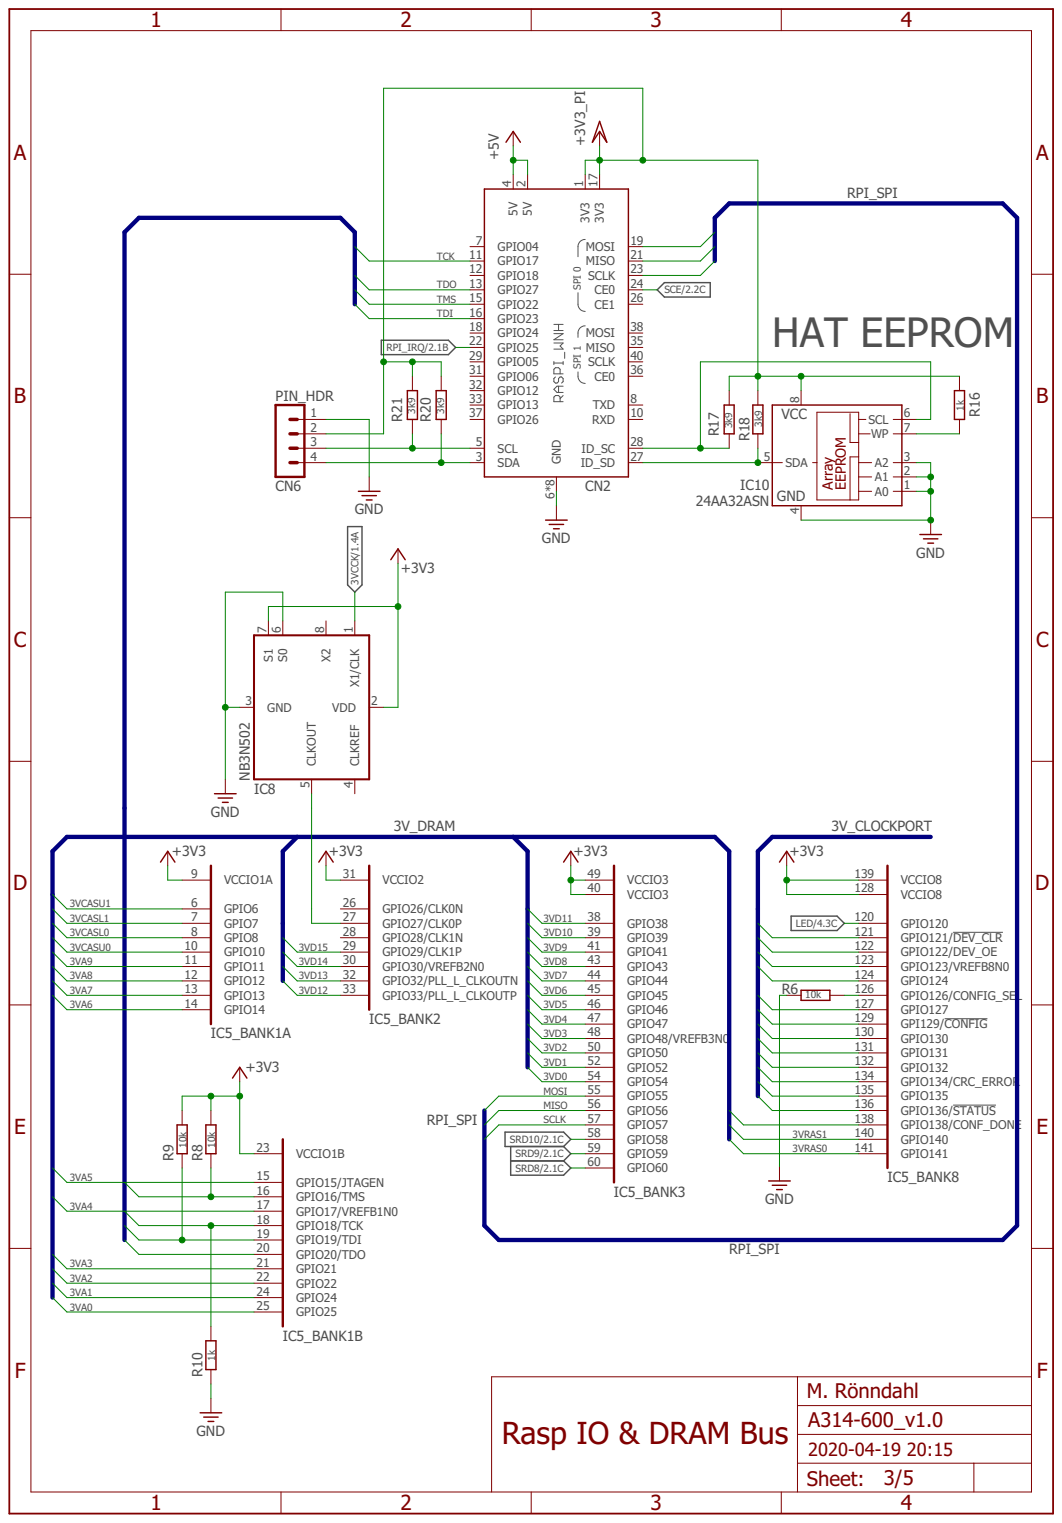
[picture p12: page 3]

Rasp IO & DRAM Bus

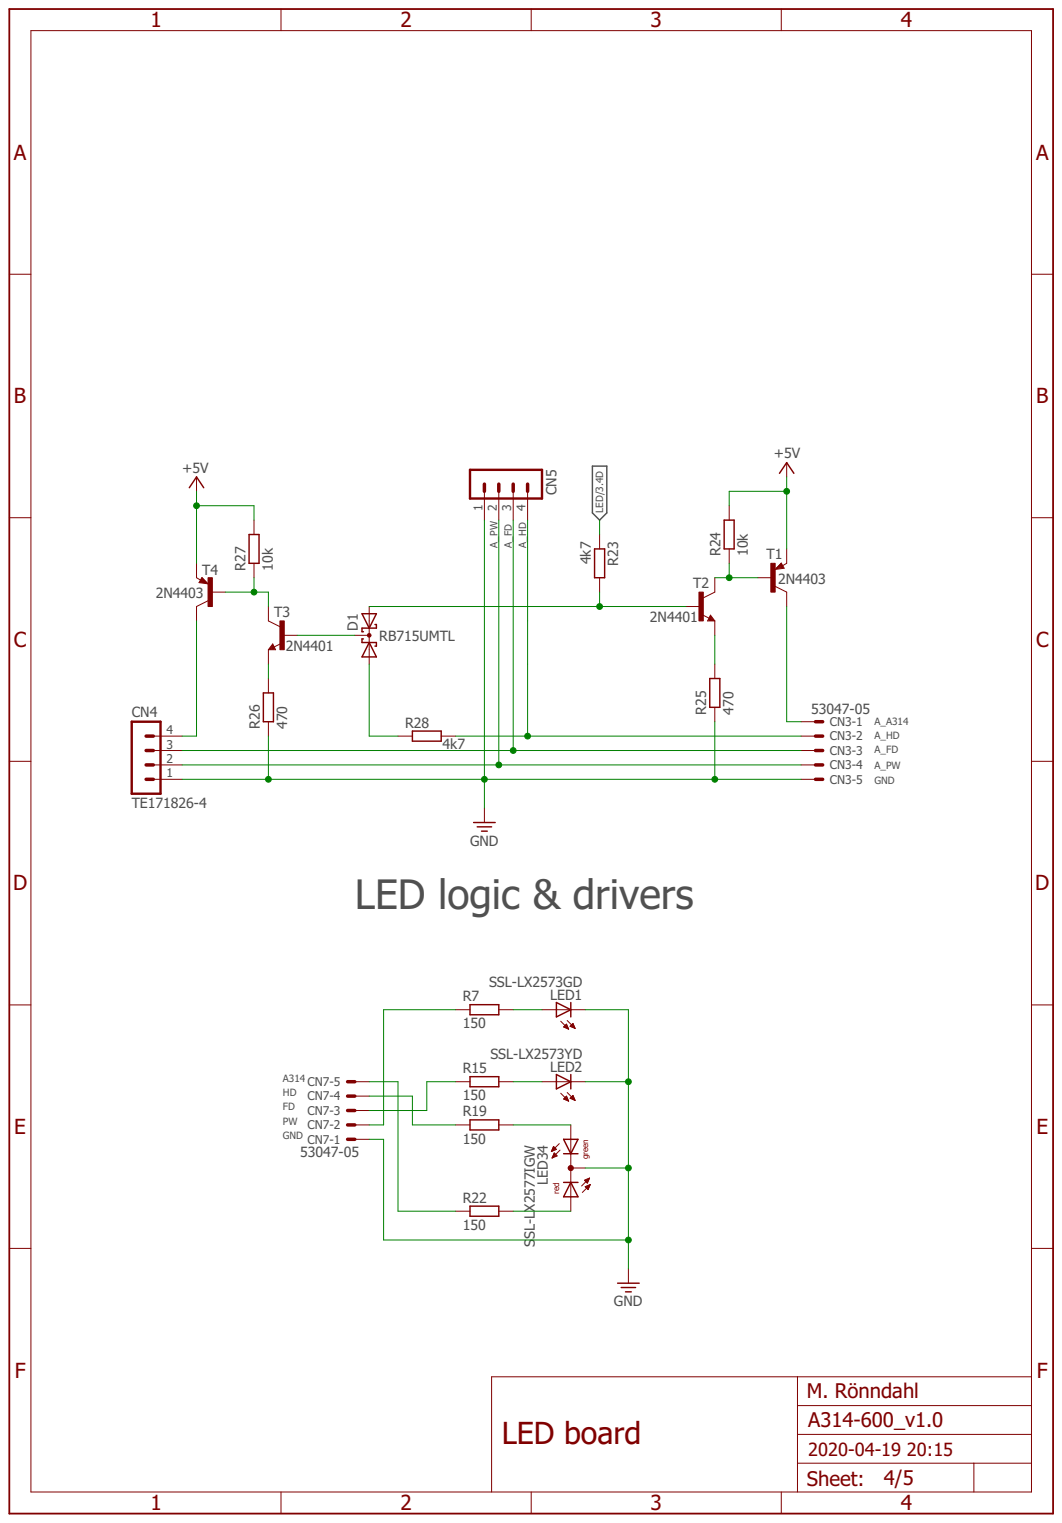
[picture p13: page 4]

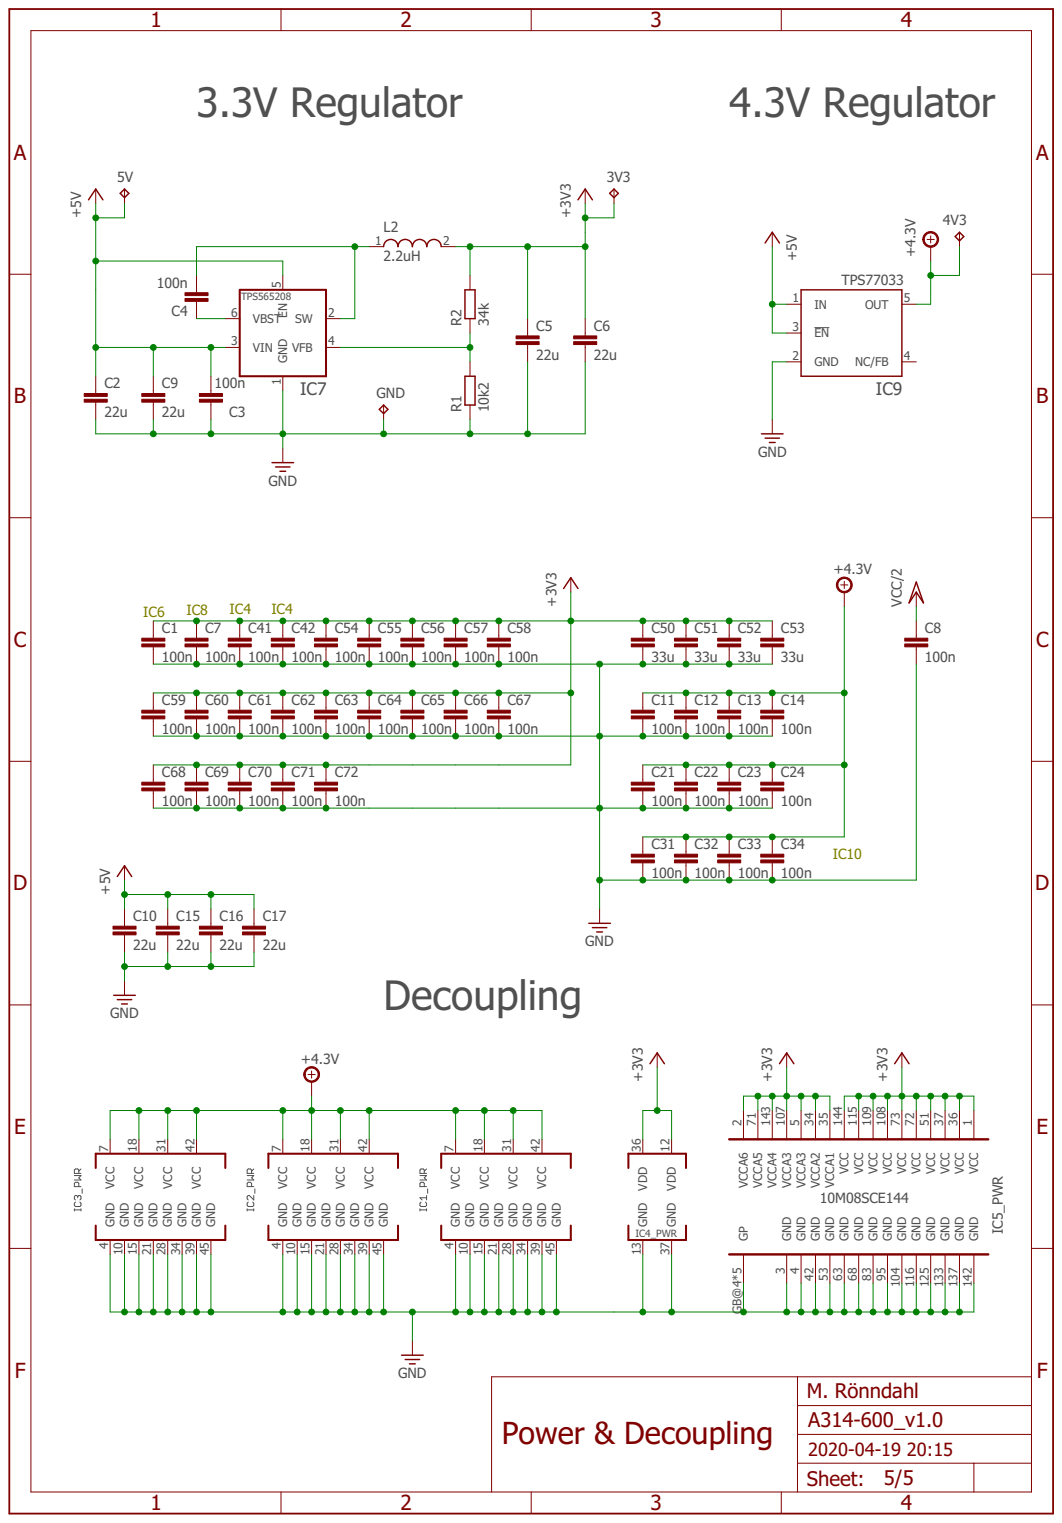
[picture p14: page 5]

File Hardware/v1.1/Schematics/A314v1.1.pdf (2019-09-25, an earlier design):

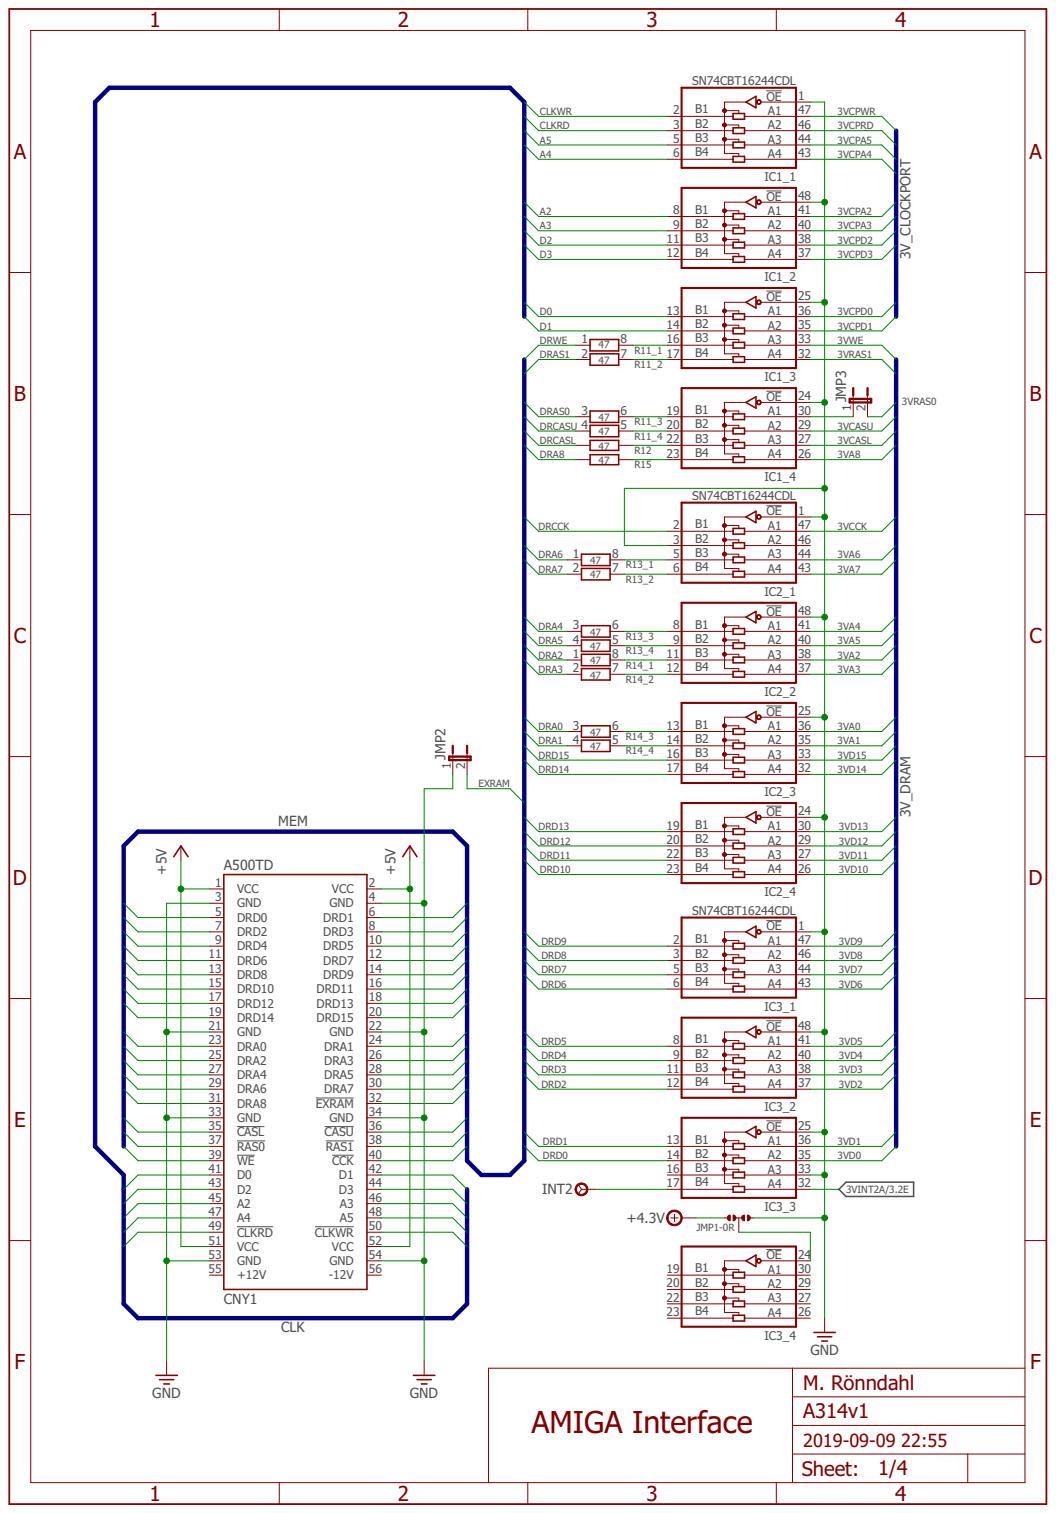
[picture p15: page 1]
A4 A500TD GND; GND ⁺⁵V; SN74CBT16244CDL SN74CBT16244CDL SN74CBT16244CDL; GND ⁺4.3V ⁴⁷⁴⁷ VCC 1; GND 3; DRD0 5; DRD2 7; DRD4 9; DRD8 13; DRD6 11; DRD10 15; DRD12 17; DRD14 19; DRA0 23; DRA2 25; GND 21; DRA4 27; DRA6 29; DRA8 31; GND 33; CASL 35; RAS0 37; VCC; 2 GND; 4 DRD1; 6 DRD3; 8 DRD5; 10 DRD7; 12 DRD9; 14 DRD11; 16 DRD15; 20 GND; 22 DRD13; 18 DRA1; 24 DRA3; 26 DRA7; 30 DRA5; 28 EXRAM; 32 CASU; 36 GND; 34 RAS1; 38 CCK; CLKRD 49; VCC 51; GND 53; 56 GND; 48 CLKWR; 50 VCC; 52 CNY1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

A

A

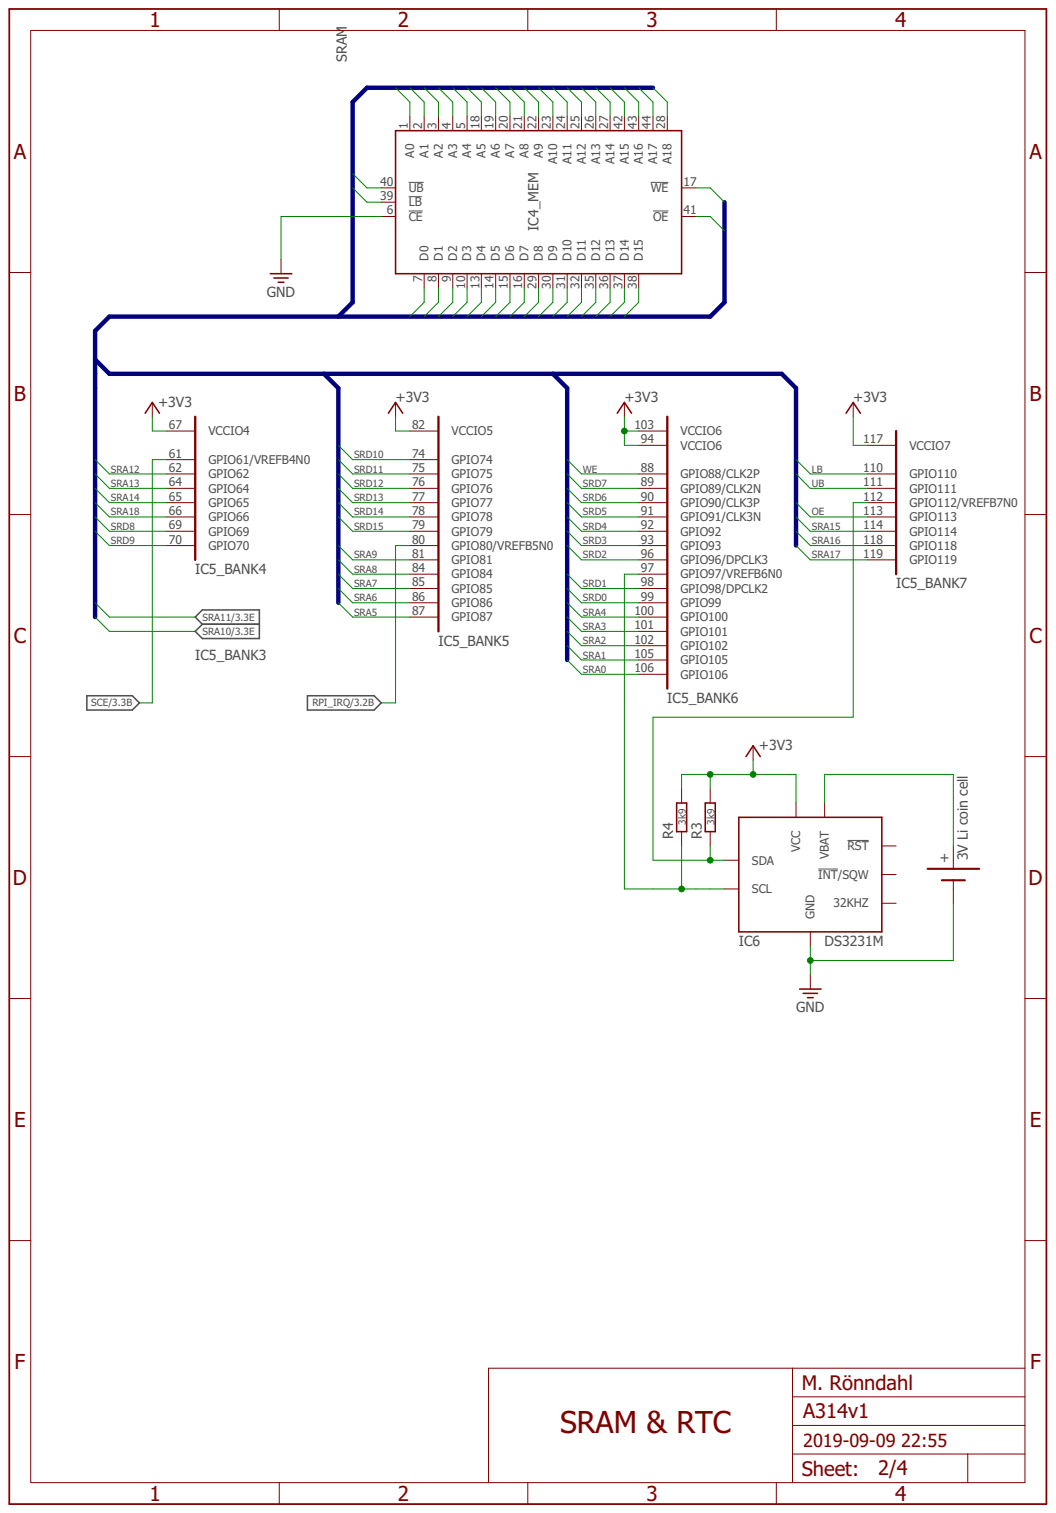
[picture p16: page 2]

A

A

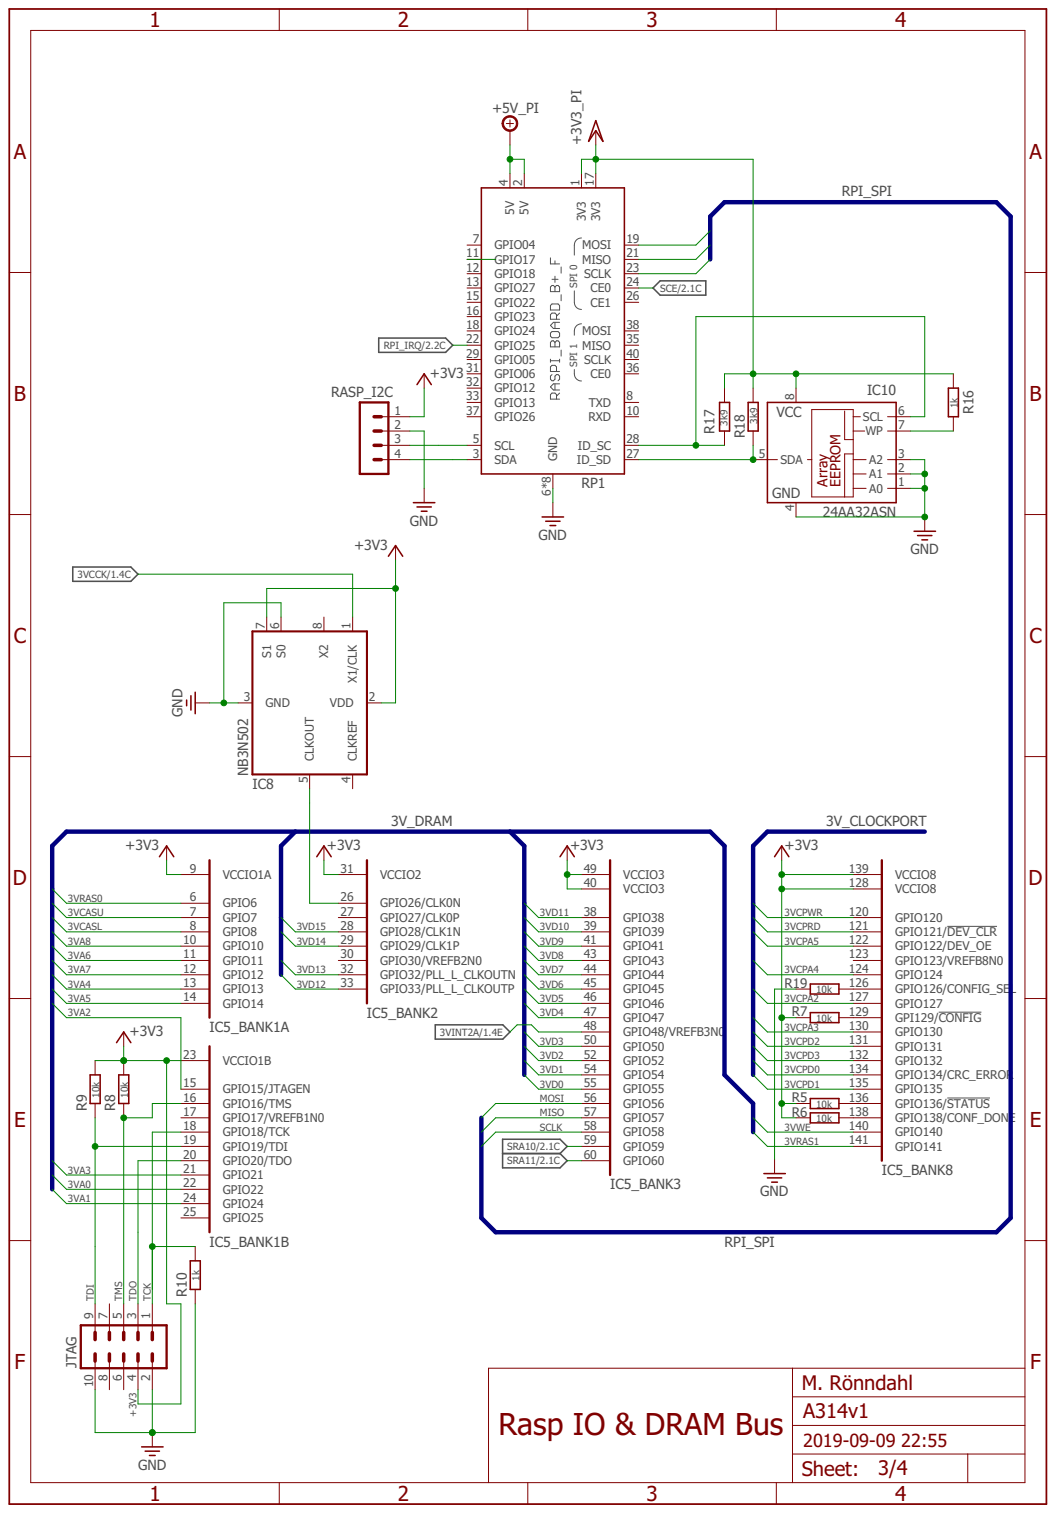
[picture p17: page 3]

Rasp IO & DRAM Bus

3.3V Regulator | 4.3V Regulator | 5.15V Regulator

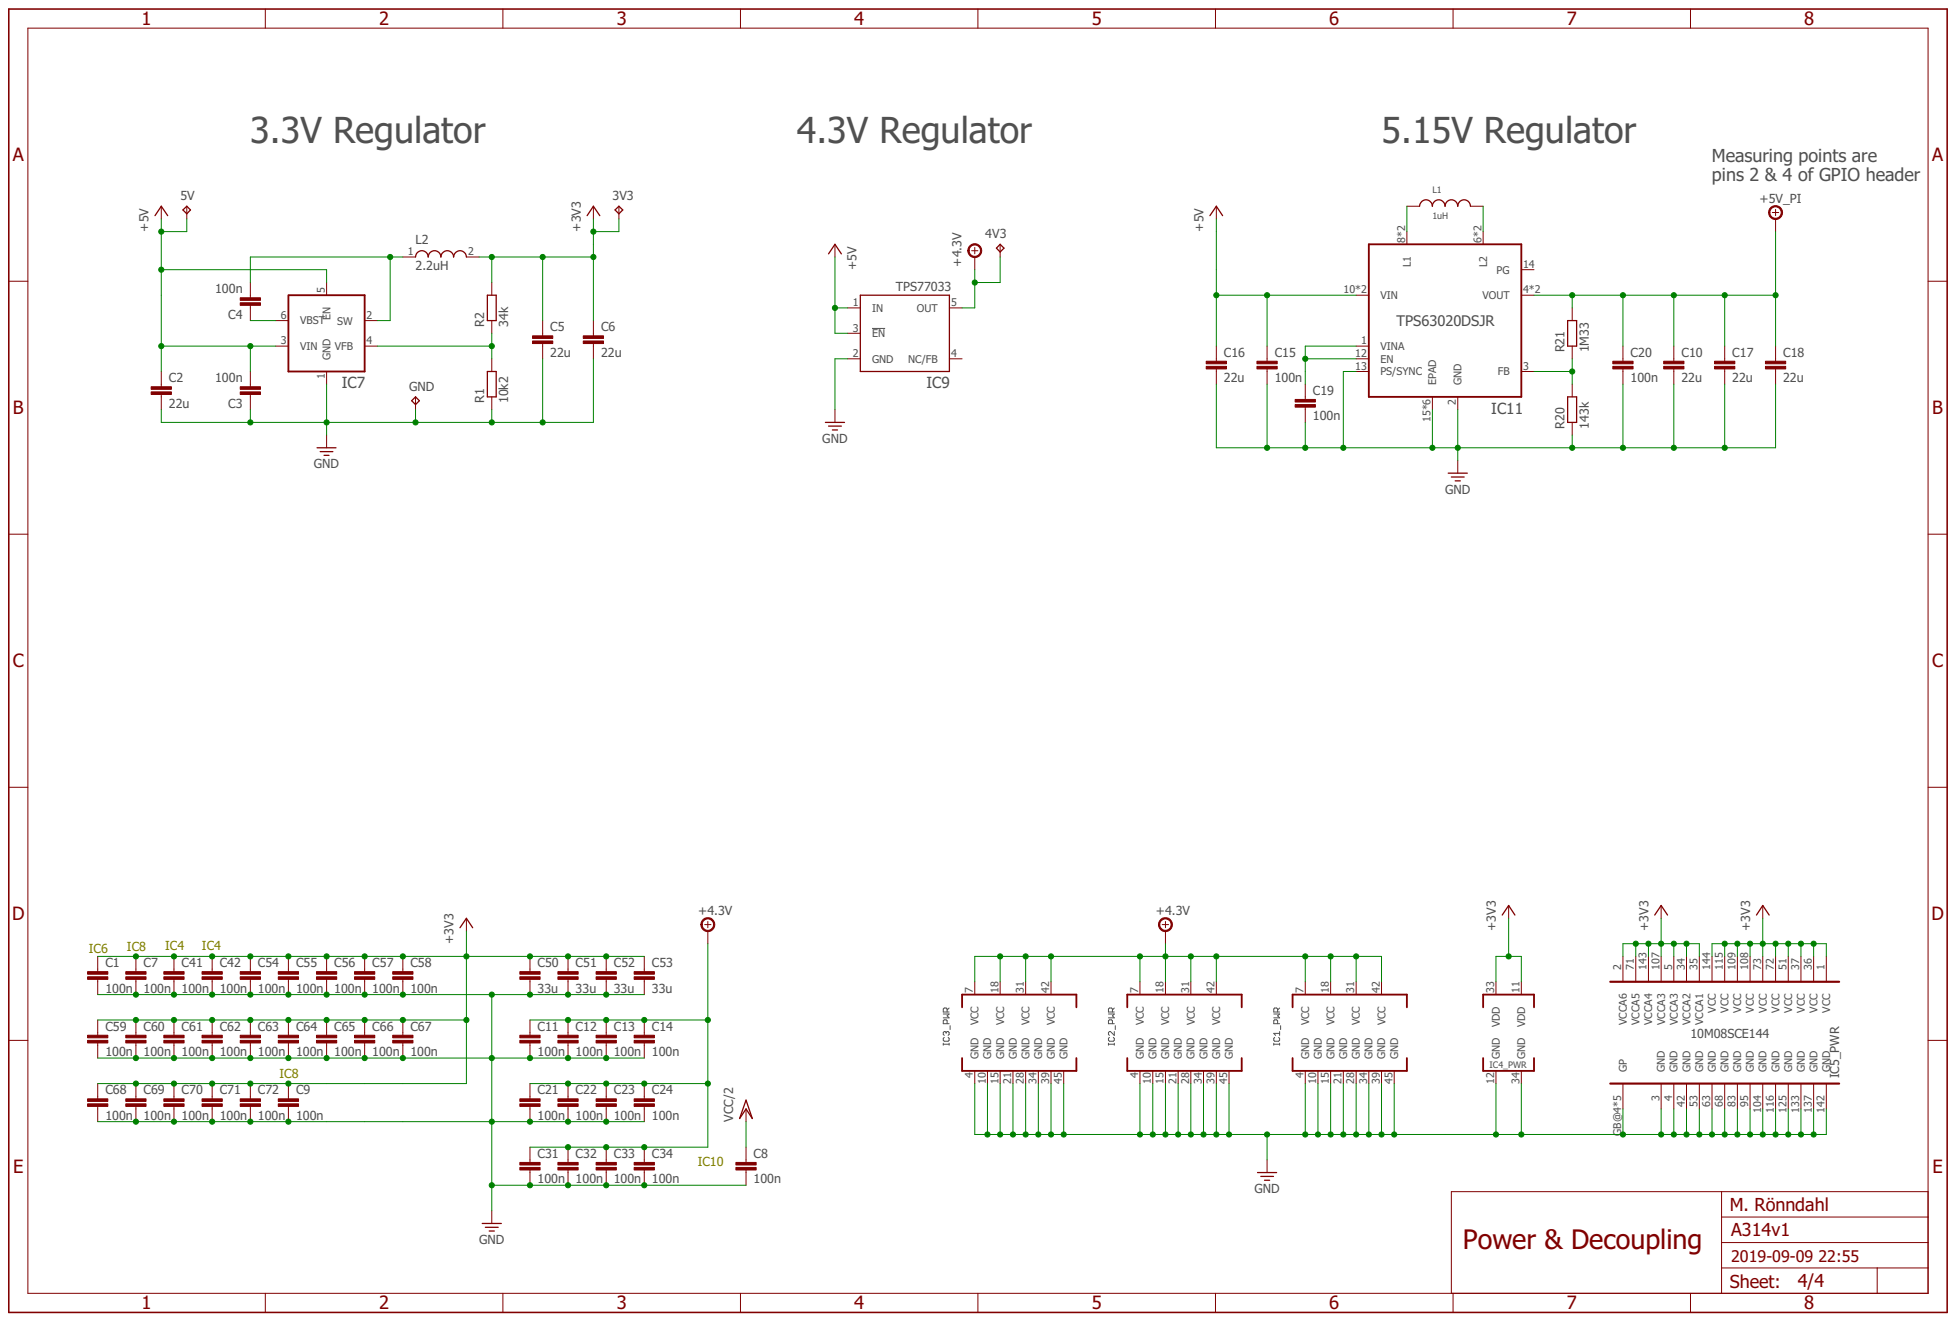
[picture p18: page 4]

Measuring points are pins 2 & 4 of GPIO header

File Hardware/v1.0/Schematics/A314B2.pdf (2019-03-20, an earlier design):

A4 A500TD GND; GND ⁺⁵V; SN74CBT16244CDL SN74CBT16244CDL SN74CBT16244CDL; GND ⁺4.3V ⁴⁷⁴⁷ VCC 1; GND 3; DRD0 5; DRD2 7; DRD4 9; DRD8 13; DRD6 11; DRD10 15; DRD12 17; DRD14 19; DRA0 23; DRA2 25; GND 21; DRA4 27; DRA6 29; DRA8 31; GND 33; CASL 35; RAS0 37; VCC; 2 GND; 4 DRD1; 6 DRD3; 8 DRD5; 10 DRD7; 12 DRD9; 14 DRD11; 16 DRD15; 20 GND; 22 DRD13; 18 DRA1; 24 DRA3; 26 DRA7; 30 DRA5; 28 EXRAM; 32 CASU; 36 GND; 34 RAS1; 38 CCK; CLKRD 49; VCC 51; GND 53; 56 GND; 48 CLKWR; 50 VCC; 52 CNY1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

A

A


A

A


Rasp IO & DRAM Bus

3.3V Regulator | 4.3V Regulator | 5.15V Regulator

## Measuring points are


pins 2 & 4 of GPIO header

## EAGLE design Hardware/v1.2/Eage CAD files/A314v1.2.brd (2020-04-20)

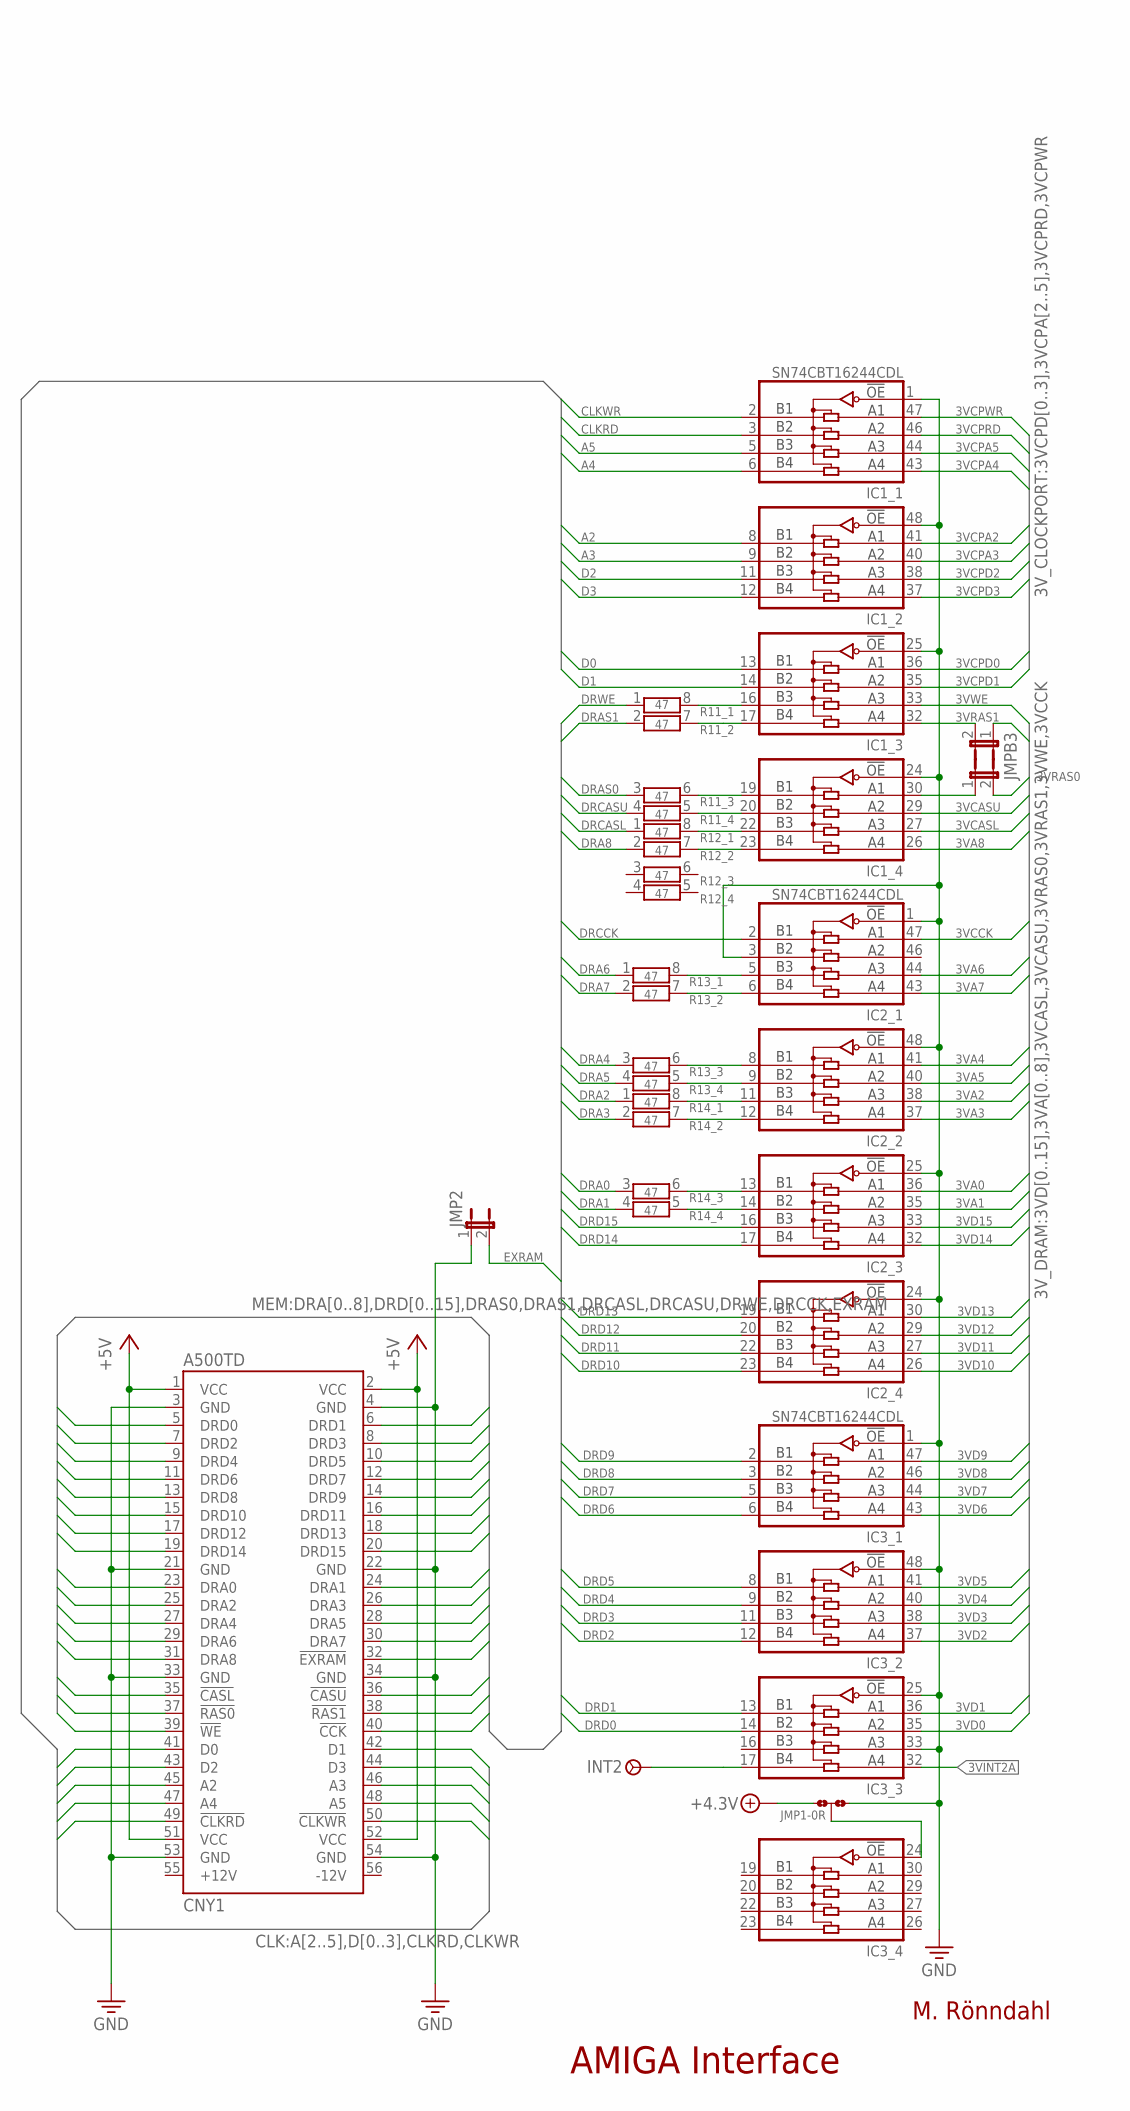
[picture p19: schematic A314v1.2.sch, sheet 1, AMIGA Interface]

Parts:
CNY1: A500TD; TRAPDOOR
IC1, IC2, IC3: SN74CBT16244CDL; SSOP-DL48
INT2: TP1; P1-08
JMP1: 0R-JUMPC; C0R-JMP
JMP2: JP1E; JP1
JMP3: RAS0; JP1
JMPB3: JP1E; JP1
R11, R12, R13, R14: 47; CTS742C083

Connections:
3VA0: IC2.36 (A1); also elsewhere on the board
3VA1: IC2.35 (A2); also elsewhere on the board
3VA2: IC2.38 (A3); also elsewhere on the board
3VA3: IC2.37 (A4); also elsewhere on the board
3VA4: IC2.41 (A1); also elsewhere on the board
3VA5: IC2.40 (A2); also elsewhere on the board
3VA6: IC2.44 (A3); also elsewhere on the board
3VA7: IC2.43 (A4); also elsewhere on the board
3VA8: IC1.26 (A4); also elsewhere on the board
3VCASL: IC1.27 (A3); also elsewhere on the board
3VCASU: IC1.29 (A2); also elsewhere on the board
3VCCK: IC2.47 (A1); also elsewhere on the board
3VCPA2: IC1.41 (A1); also elsewhere on the board
3VCPA3: IC1.40 (A2); also elsewhere on the board
3VCPA4: IC1.43 (A4); also elsewhere on the board
3VCPA5: IC1.44 (A3); also elsewhere on the board
3VCPD0: IC1.36 (A1); also elsewhere on the board
3VCPD1: IC1.35 (A2); also elsewhere on the board
3VCPD2: IC1.38 (A3); also elsewhere on the board
3VCPD3: IC1.37 (A4); also elsewhere on the board
3VCPRD: IC1.46 (A2); also elsewhere on the board
3VCPWR: IC1.47 (A1); also elsewhere on the board
3VD0: IC3.35 (A2); also elsewhere on the board
3VD1: IC3.36 (A1); also elsewhere on the board
3VD2: IC3.37 (A4); also elsewhere on the board
3VD3: IC3.38 (A3); also elsewhere on the board
3VD4: IC3.40 (A2); also elsewhere on the board
3VD5: IC3.41 (A1); also elsewhere on the board
3VD6: IC3.43 (A4); also elsewhere on the board
3VD7: IC3.44 (A3); also elsewhere on the board
3VD8: IC3.46 (A2); also elsewhere on the board
3VD9: IC3.47 (A1); also elsewhere on the board
3VD10: IC2.26 (A4); also elsewhere on the board
3VD11: IC2.27 (A3); also elsewhere on the board
3VD12: IC2.29 (A2); also elsewhere on the board
3VD13: IC2.30 (A1); also elsewhere on the board
3VD14: IC2.32 (A4); also elsewhere on the board
3VD15: IC2.33 (A3); also elsewhere on the board
3VINT2A: IC3.32 (A4); also elsewhere on the board
3VRAS0: JMP3.2; also elsewhere on the board
3VRAS1: JMPB3.1; also elsewhere on the board
3VWE: IC1.33 (A3); also elsewhere on the board
+4.3V: JMP1.1; also elsewhere on the board
+5V: CNY1.1 (VCC), CNY1.2 (VCC), CNY1.51 (VCC), CNY1.52 (VCC); also elsewhere on the board
A2: CNY1.45 (A2), IC1.8 (B1)
A3: CNY1.46 (A3), IC1.9 (B2)
A4: CNY1.47 (A4), IC1.6 (B4)
A5: CNY1.48 (A5), IC1.5 (B3)
CLKRD: CNY1.49 (!CLKRD), IC1.3 (B2)
CLKWR: CNY1.50 (!CLKWR), IC1.2 (B1)
D0: CNY1.41 (D0), IC1.13 (B1)
D1: CNY1.42 (D1), IC1.14 (B2)
D2: CNY1.43 (D2), IC1.11 (B3)
D3: CNY1.44 (D3), IC1.12 (B4)
DRA0: CNY1.23 (DRA0), R14.3
DRA1: CNY1.24 (DRA1), R14.4
DRA2: CNY1.25 (DRA2), R14.1
DRA3: CNY1.26 (DRA3), R14.2
DRA4: CNY1.27 (DRA4), R13.3
DRA5: CNY1.28 (DRA5), R13.4
DRA6: CNY1.29 (DRA6), R13.1
DRA7: CNY1.30 (DRA7), R13.2
DRA8: CNY1.31 (DRA8), R12.2
DRA8_L: IC1.23 (B4), R12.7
DRAS0: CNY1.37 (!RAS0), R11.3
DRAS0_L: IC1.19 (B1), R11.6
DRAS1: CNY1.38 (!RAS1), R11.2
DRAS1_L: IC1.17 (B4), R11.7
DRCASL: CNY1.35 (!CASL), R12.1
DRCASL_L: IC1.22 (B3), R12.8
DRCASU: CNY1.36 (!CASU), R11.4
DRCASU_L: IC1.20 (B2), R11.5
DRCCK: CNY1.40 (!CCK), IC2.2 (B1)
DRD0: CNY1.5 (DRD0), IC3.14 (B2)
DRD1: CNY1.6 (DRD1), IC3.13 (B1)
DRD2: CNY1.7 (DRD2), IC3.12 (B4)
DRD3: CNY1.8 (DRD3), IC3.11 (B3)
DRD4: CNY1.9 (DRD4), IC3.9 (B2)
DRD5: CNY1.10 (DRD5), IC3.8 (B1)
DRD6: CNY1.11 (DRD6), IC3.6 (B4)
DRD7: CNY1.12 (DRD7), IC3.5 (B3)
DRD8: CNY1.13 (DRD8), IC3.3 (B2)
DRD9: CNY1.14 (DRD9), IC3.2 (B1)
DRD10: CNY1.15 (DRD10), IC2.23 (B4)
DRD11: CNY1.16 (DRD11), IC2.22 (B3)
DRD12: CNY1.17 (DRD12), IC2.20 (B2)
DRD13: CNY1.18 (DRD13), IC2.19 (B1)
DRD14: CNY1.19 (DRD14), IC2.17 (B4)
DRD15: CNY1.20 (DRD15), IC2.16 (B3)
DRWE: CNY1.39 (!WE), R11.1
DRWE_L: IC1.16 (B3), R11.8
EXRAM: CNY1.32 (!EXRAM), JMP2.2
GND: CNY1.3 (GND), CNY1.4 (GND), CNY1.21 (GND), CNY1.22 (GND), CNY1.33 (GND), CNY1.34 (GND), CNY1.53 (GND), CNY1.54 (GND), IC1.1 (!OE), IC1.24 (!OE), IC1.25 (!OE), IC1.48 (!OE), IC2.1 (!OE), IC2.3 (B2), IC2.24 (!OE), IC2.25 (!OE), IC2.48 (!OE), IC3.1 (!OE), IC3.25 (!OE), IC3.33 (A3), IC3.48 (!OE), JMP1.3, JMP2.1; also elsewhere on the board
INT2A: IC3.17 (B4), INT2.TP
unnamed: IC2.14 (B2), R14.5
unnamed: IC2.13 (B1), R14.6
unnamed: IC2.12 (B4), R14.7
unnamed: IC2.11 (B3), R14.8
unnamed: IC2.9 (B2), R13.5
unnamed: IC2.8 (B1), R13.6
unnamed: IC2.6 (B4), R13.7
unnamed: IC2.5 (B3), R13.8
OUTPUT_EN: IC3.24 (!OE), JMP1.2
RAS0: IC1.30 (A1), JMP3.1
RAS1: IC1.32 (A4), JMPB3.2

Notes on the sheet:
AMIGA Interface
M. Rönndahl

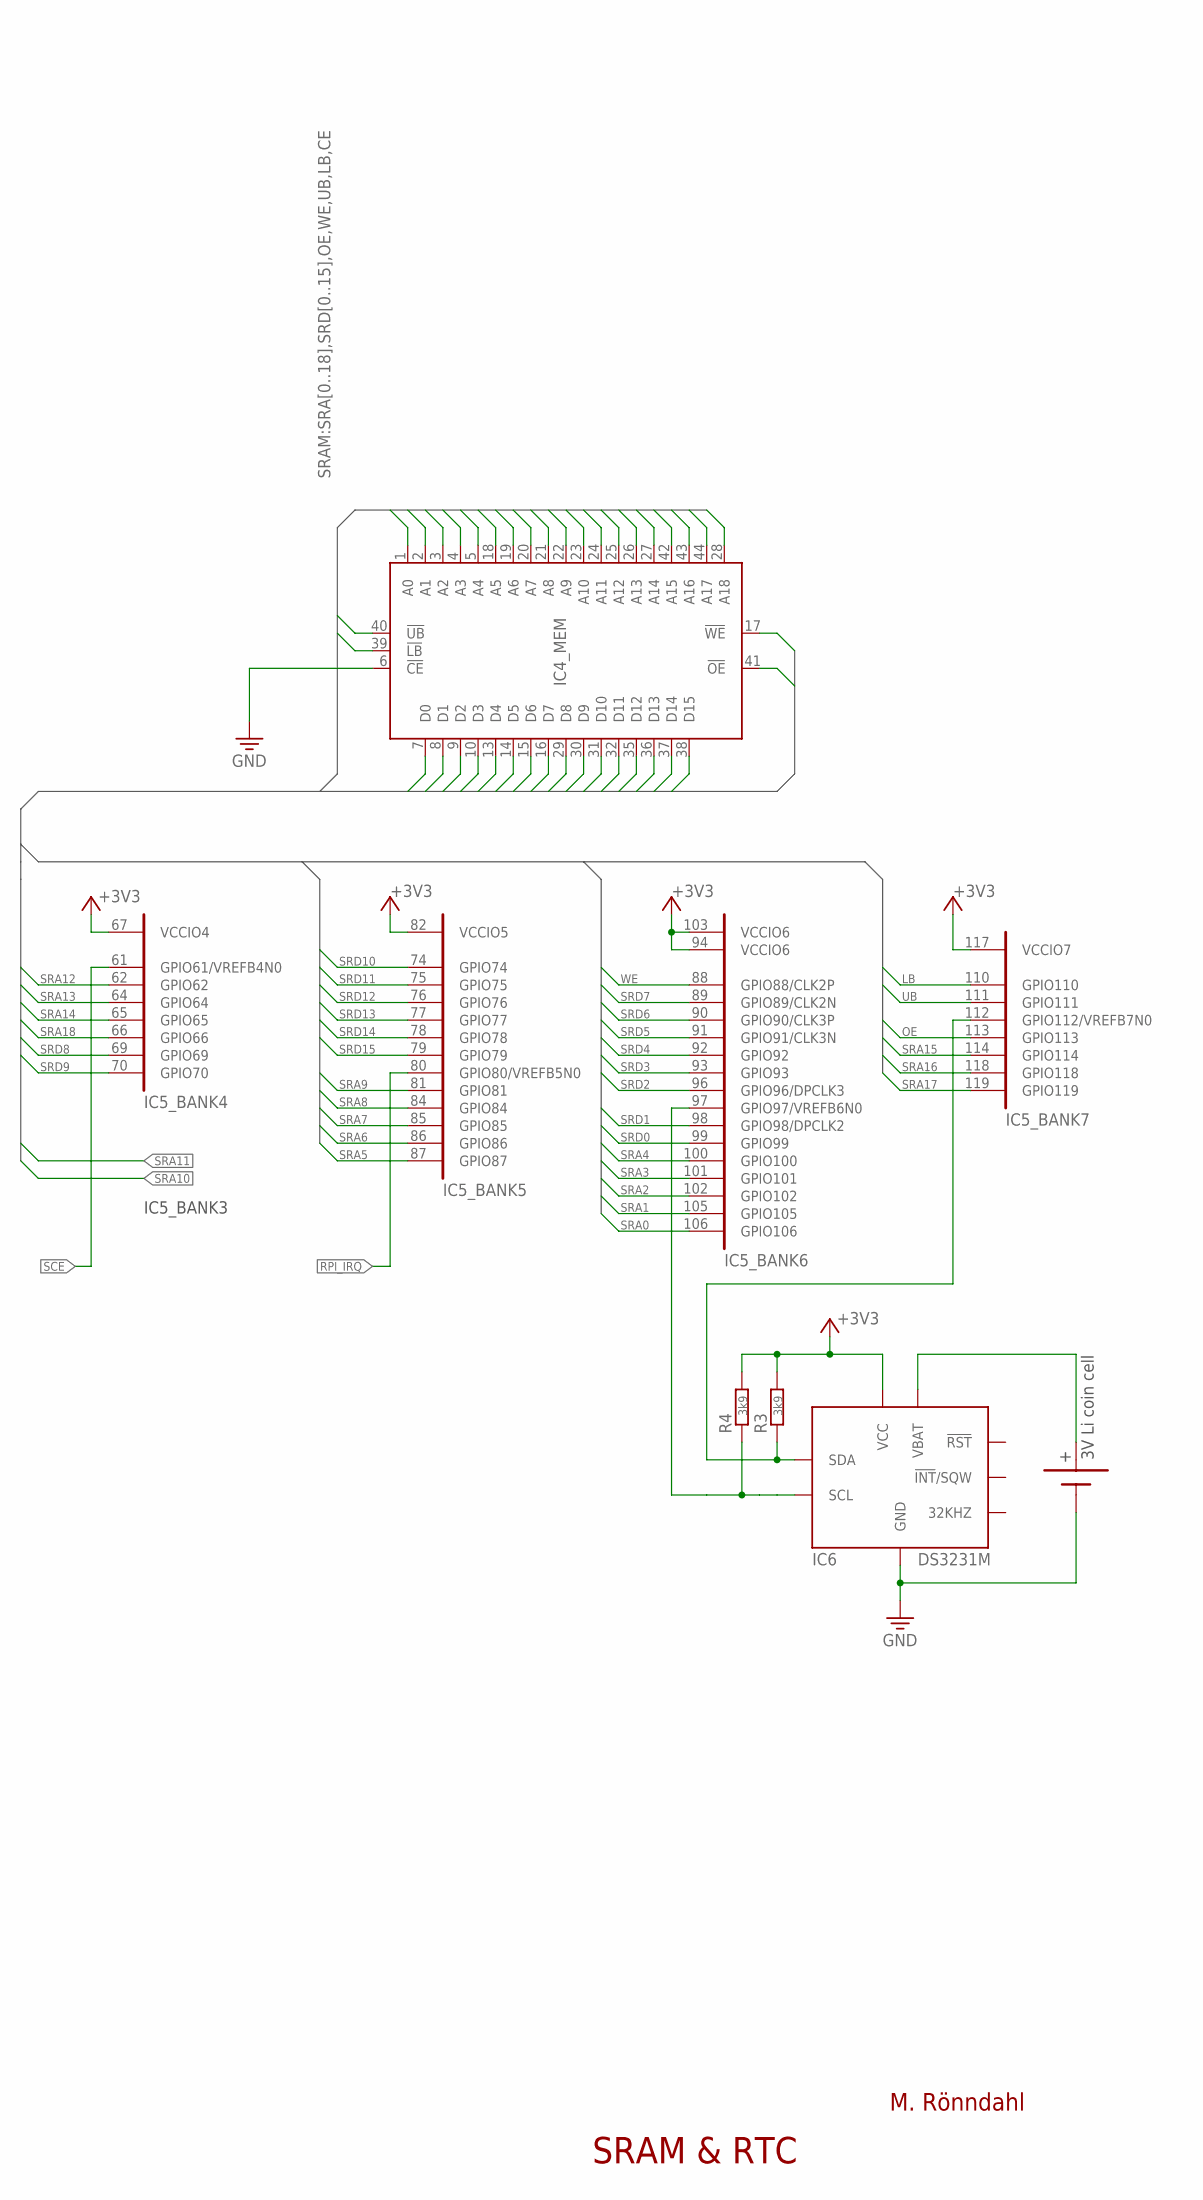
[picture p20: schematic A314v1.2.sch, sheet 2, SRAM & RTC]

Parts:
BAT1: CR2025/CR2032TH; LINX20XX-THM
IC4: IS61WV51216BLL-10TLI; TSOP-2
IC5: 10M08SCE144; SQFP-S-20X20-144
IC6: DS3231M; SOIC8
R3, R4: 3k9; R0805

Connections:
+: BAT1.+@1 (+), BAT1.+@2 (+), BAT1.+@3 (+), BAT1.+@4 (+), IC6.6 (VBAT)
+3V3: IC5.67 (VCCIO4), IC5.82 (VCCIO5), IC5.94 (VCCIO6), IC5.103 (VCCIO6), IC5.117 (VCCIO7), IC6.2 (VCC), R3.2, R4.2; also elsewhere on the board
GND: BAT1.GND (-), IC4.6 (!CE), IC6.5 (GND); also elsewhere on the board
LB: IC4.39 (!LB), IC5.110 (GPIO110)
OE: IC4.41 (!OE), IC5.113 (GPIO113)
RPI_IRQ: IC5.80 (GPIO80/VREFB5N0); also elsewhere on the board
SCE: IC5.61 (GPIO61/VREFB4N0); also elsewhere on the board
SCL: IC5.97 (GPIO97/VREFB6N0), IC6.8 (SCL), R4.1
SDA: IC5.112 (GPIO112/VREFB7N0), IC6.7 (SDA), R3.1
SRA0: IC4.1 (A0), IC5.106 (GPIO106)
SRA1: IC4.2 (A1), IC5.105 (GPIO105)
SRA2: IC4.3 (A2), IC5.102 (GPIO102)
SRA3: IC4.4 (A3), IC5.101 (GPIO101)
SRA4: IC4.5 (A4), IC5.100 (GPIO100)
SRA5: IC4.18 (A5), IC5.87 (GPIO87)
SRA6: IC4.19 (A6), IC5.86 (GPIO86)
SRA7: IC4.20 (A7), IC5.85 (GPIO85)
SRA8: IC4.21 (A8), IC5.84 (GPIO84)
SRA9: IC4.22 (A9), IC5.81 (GPIO81)
SRA10: IC4.23 (A10); also elsewhere on the board
SRA11: IC4.24 (A11); also elsewhere on the board
SRA12: IC4.25 (A12), IC5.62 (GPIO62)
SRA13: IC4.26 (A13), IC5.64 (GPIO64)
SRA14: IC4.27 (A14), IC5.65 (GPIO65)
SRA15: IC4.42 (A15), IC5.114 (GPIO114)
SRA16: IC4.43 (A16), IC5.118 (GPIO118)
SRA17: IC4.44 (A17), IC5.119 (GPIO119)
SRA18: IC4.28 (A18), IC5.66 (GPIO66)
SRD0: IC4.7 (D0), IC5.99 (GPIO99)
SRD1: IC4.8 (D1), IC5.98 (GPIO98/DPCLK2)
SRD2: IC4.9 (D2), IC5.96 (GPIO96/DPCLK3)
SRD3: IC4.10 (D3), IC5.93 (GPIO93)
SRD4: IC4.13 (D4), IC5.92 (GPIO92)
SRD5: IC4.14 (D5), IC5.91 (GPIO91/CLK3N)
SRD6: IC4.15 (D6), IC5.90 (GPIO90/CLK3P)
SRD7: IC4.16 (D7), IC5.89 (GPIO89/CLK2N)
SRD8: IC4.29 (D8), IC5.69 (GPIO69)
SRD9: IC4.30 (D9), IC5.70 (GPIO70)
SRD10: IC4.31 (D10), IC5.74 (GPIO74)
SRD11: IC4.32 (D11), IC5.75 (GPIO75)
SRD12: IC4.35 (D12), IC5.76 (GPIO76)
SRD13: IC4.36 (D13), IC5.77 (GPIO77)
SRD14: IC4.37 (D14), IC5.78 (GPIO78)
SRD15: IC4.38 (D15), IC5.79 (GPIO79)
UB: IC4.40 (!UB), IC5.111 (GPIO111)
WE: IC4.17 (!WE), IC5.88 (GPIO88/CLK2P)

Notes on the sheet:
IC5_BANK3
SRAM & RTC
3V Li coin cell
M. Rönndahl

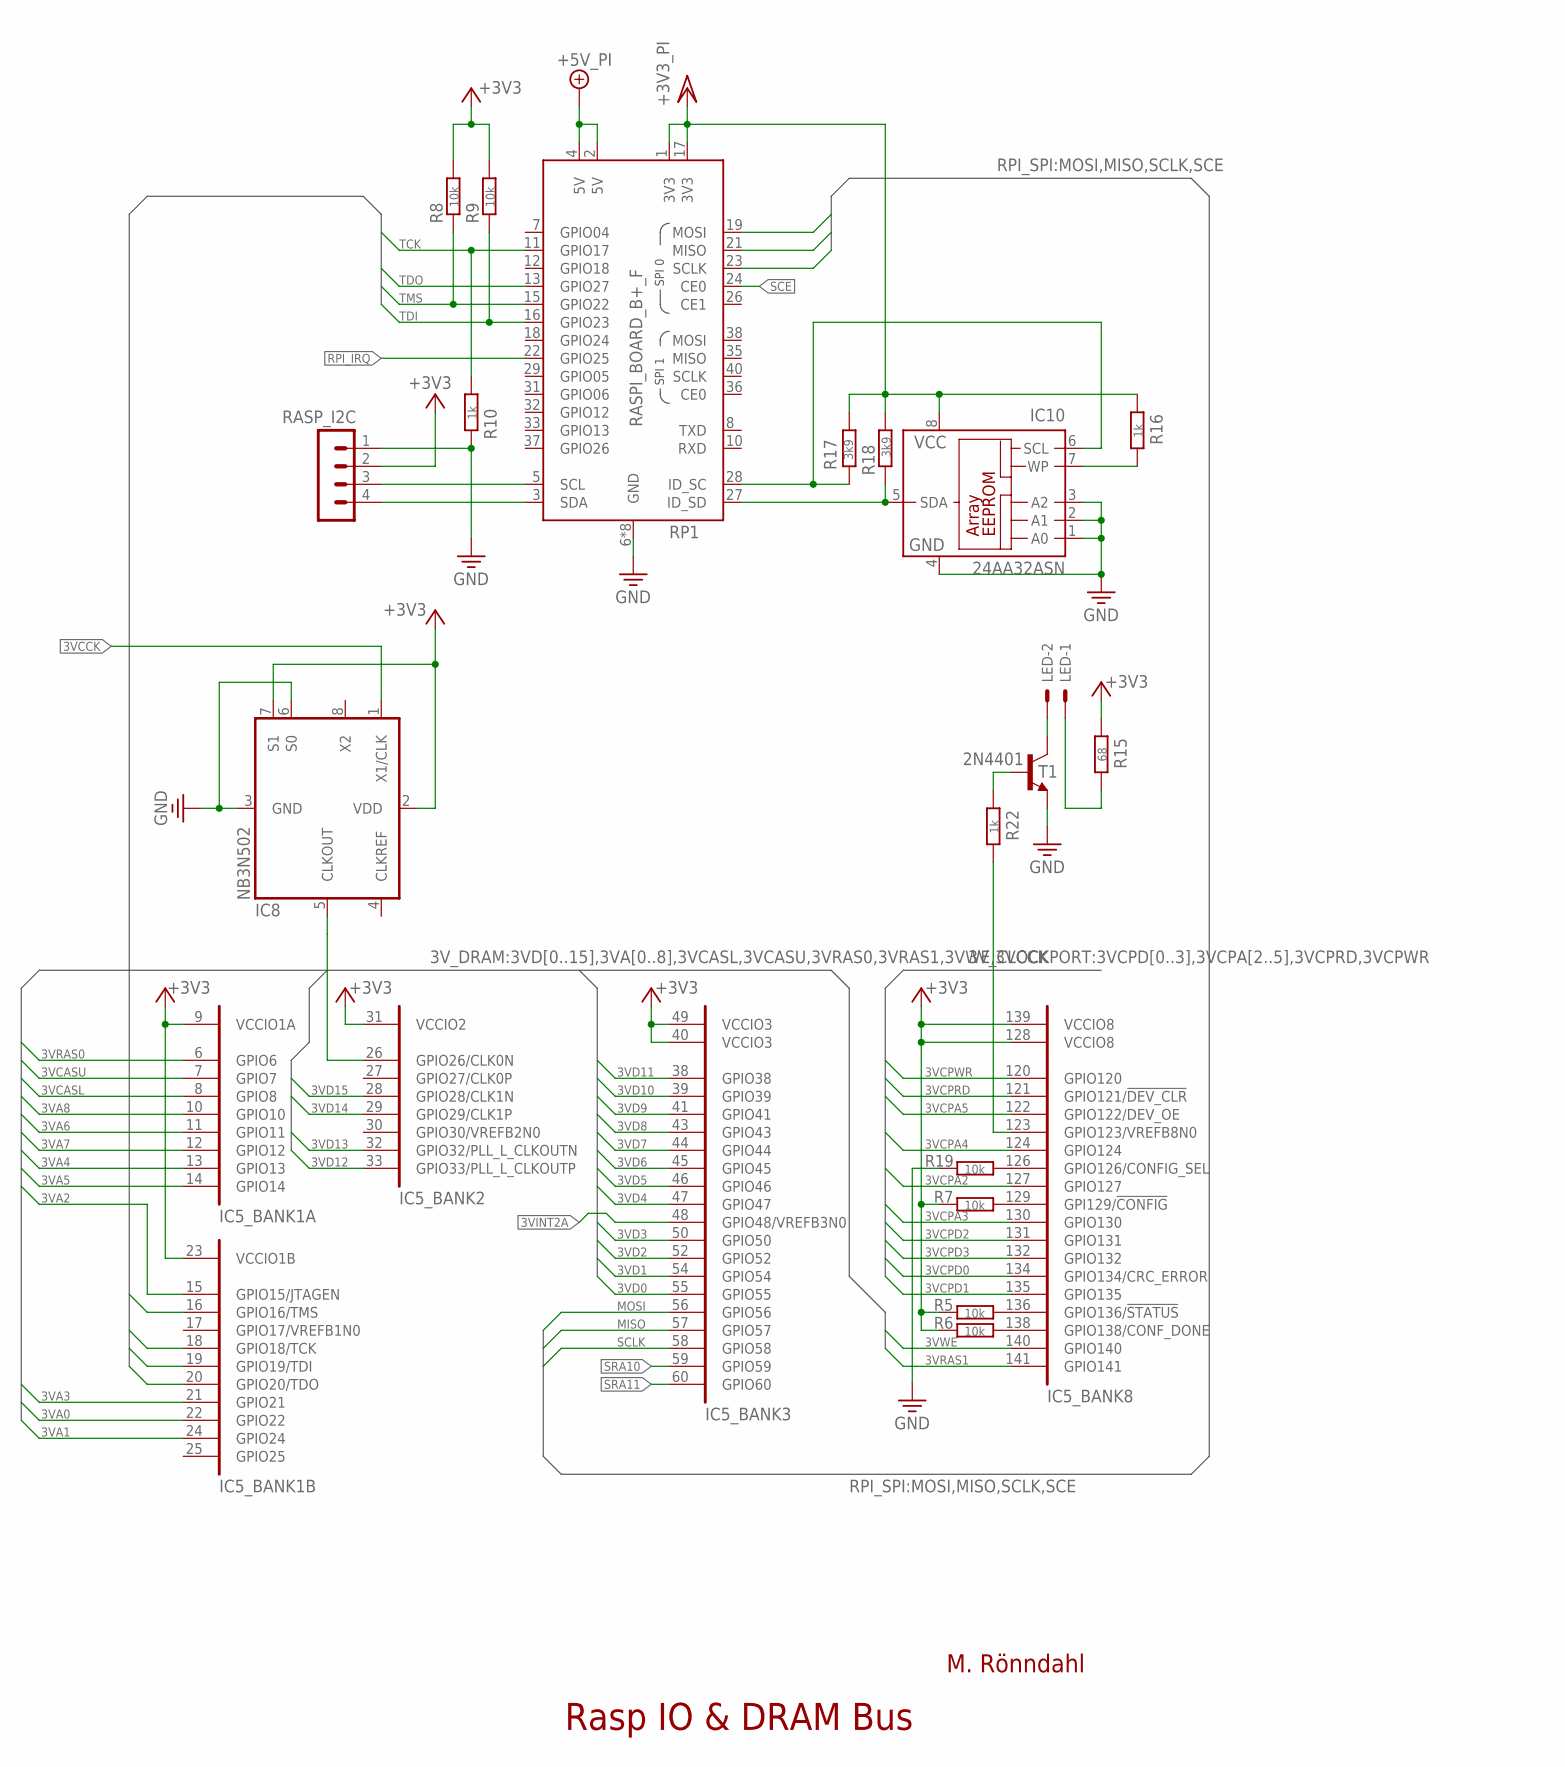
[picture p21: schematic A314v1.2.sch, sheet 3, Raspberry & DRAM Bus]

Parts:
IC5: 10M08SCE144; SQFP-S-20X20-144
IC8: NB3N502; SO08
IC10: 24AA32ASN; SO-08
LED: 22-23-2021
R5, R6, R7, R8, R9, R19: 10k; R0805
R10, R16, R22: 1k; R0805
R15: 68; R0805
R17, R18: 3k9; R0805
RASP_I2C: MA04-1
RP1: RASPI_BOARD_B+_F; RASPI_BOARD_B+_FULL
T1: 2N4401; SOT23-BEC

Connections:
3VA0: IC5.22 (GPIO22); also elsewhere on the board
3VA1: IC5.24 (GPIO24); also elsewhere on the board
3VA2: IC5.15 (GPIO15/JTAGEN); also elsewhere on the board
3VA3: IC5.21 (GPIO21); also elsewhere on the board
3VA4: IC5.13 (GPIO13); also elsewhere on the board
3VA5: IC5.14 (GPIO14); also elsewhere on the board
3VA6: IC5.11 (GPIO11); also elsewhere on the board
3VA7: IC5.12 (GPIO12); also elsewhere on the board
3VA8: IC5.10 (GPIO10); also elsewhere on the board
3VCASL: IC5.8 (GPIO8); also elsewhere on the board
3VCASU: IC5.7 (GPIO7); also elsewhere on the board
3VCCK: IC8.1 (X1/CLK); also elsewhere on the board
3VCPA2: IC5.127 (GPIO127); also elsewhere on the board
3VCPA3: IC5.130 (GPIO130); also elsewhere on the board
3VCPA4: IC5.124 (GPIO124); also elsewhere on the board
3VCPA5: IC5.122 (GPIO122/DEV_OE); also elsewhere on the board
3VCPD0: IC5.134 (GPIO134/CRC_ERROR); also elsewhere on the board
3VCPD1: IC5.135 (GPIO135); also elsewhere on the board
3VCPD2: IC5.131 (GPIO131); also elsewhere on the board
3VCPD3: IC5.132 (GPIO132); also elsewhere on the board
3VCPRD: IC5.121 (GPIO121/!DEV_CLR); also elsewhere on the board
3VCPWR: IC5.120 (GPIO120); also elsewhere on the board
3VD0: IC5.55 (GPIO55); also elsewhere on the board
3VD1: IC5.54 (GPIO54); also elsewhere on the board
3VD2: IC5.52 (GPIO52); also elsewhere on the board
3VD3: IC5.50 (GPIO50); also elsewhere on the board
3VD4: IC5.47 (GPIO47); also elsewhere on the board
3VD5: IC5.46 (GPIO46); also elsewhere on the board
3VD6: IC5.45 (GPIO45); also elsewhere on the board
3VD7: IC5.44 (GPIO44); also elsewhere on the board
3VD8: IC5.43 (GPIO43); also elsewhere on the board
3VD9: IC5.41 (GPIO41); also elsewhere on the board
3VD10: IC5.39 (GPIO39); also elsewhere on the board
3VD11: IC5.38 (GPIO38); also elsewhere on the board
3VD12: IC5.33 (GPIO33/PLL_L_CLKOUTP); also elsewhere on the board
3VD13: IC5.32 (GPIO32/PLL_L_CLKOUTN); also elsewhere on the board
3VD14: IC5.29 (GPIO29/CLK1P); also elsewhere on the board
3VD15: IC5.28 (GPIO28/CLK1N); also elsewhere on the board
3VINT2A: IC5.48 (GPIO48/VREFB3N0); also elsewhere on the board
3VRAS0: IC5.6 (GPIO6); also elsewhere on the board
3VRAS1: IC5.141 (GPIO141); also elsewhere on the board
3VWE: IC5.140 (GPIO140); also elsewhere on the board
14MHZ: IC5.26 (GPIO26/CLK0N), IC8.5 (CLKOUT)
!CFG: IC5.129 (GPI129/!CONFIG), R7.2
!STAT: IC5.136 (GPIO136/!STATUS), R5.2
+3V3: IC5.9 (VCCIO1A), IC5.23 (VCCIO1B), IC5.31 (VCCIO2), IC5.40 (VCCIO3), IC5.49 (VCCIO3), IC5.128 (VCCIO8), IC5.139 (VCCIO8), IC8.2 (VDD), IC8.7 (S1), R5.1, R6.1, R7.1, R8.2, R9.2, R15.2, RASP_I2C.2; also elsewhere on the board
+5V/1: RP1.2 (5V), RP1.4 (5V); also elsewhere on the board
CFG_DNE: IC5.138 (GPIO138/CONF_DONE), R6.2
CFG_SEL: IC5.126 (GPIO126/CONFIG_SEL), R19.2
GND: IC8.3 (GND), IC8.6 (S0), IC10.1 (A0), IC10.2 (A1), IC10.3 (A2), IC10.4 (GND), R10.1, R19.1, RASP_I2C.1, RP1.6 (GND), RP1.9 (GND), RP1.14 (GND), RP1.20 (GND), RP1.25 (GND), RP1.30 (GND), RP1.34 (GND), RP1.39 (GND), T1.E; also elsewhere on the board
HAT_SCL: IC10.6 (SCL), R17.2, RP1.28 (ID_SC)
HAT_SDA: IC10.5 (SDA), R18.1, RP1.27 (ID_SD)
LED_CTRL: IC5.123 (GPIO123/VREFB8N0), R22.1
LED_PWR: LED.1, R15.1
LED_RTN: LED.2, T1.C
MISO: IC5.57 (GPIO57), RP1.21 (MISO)
MOSI: IC5.56 (GPIO56), RP1.19 (MOSI)
unnamed: R22.2, T1.B
PI_SCL: RASP_I2C.3, RP1.5 (SCL)
PI_SDA: RASP_I2C.4, RP1.3 (SDA)
RPI_IRQ: RP1.22 (GPIO25); also elsewhere on the board
SCE: RP1.24 (CE0); also elsewhere on the board
SCLK: IC5.58 (GPIO58), RP1.23 (SCLK)
SRA10: IC5.59 (GPIO59); also elsewhere on the board
SRA11: IC5.60 (GPIO60); also elsewhere on the board
TCK: IC5.18 (GPIO18/TCK), R10.2, RP1.11 (GPIO17)
TDI: IC5.19 (GPIO19/TDI), R9.1, RP1.16 (GPIO23)
TDO: IC5.20 (GPIO20/TDO), RP1.13 (GPIO27)
TMS: IC5.16 (GPIO16/TMS), R8.1, RP1.15 (GPIO22)
VCC/2: IC10.8 (VCC), R16.2, R17.1, R18.2, RP1.1 (3V3), RP1.17 (3V3); also elsewhere on the board
WP: IC10.7 (WP), R16.1

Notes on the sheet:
Rasp IO & DRAM Bus
M. Rönndahl

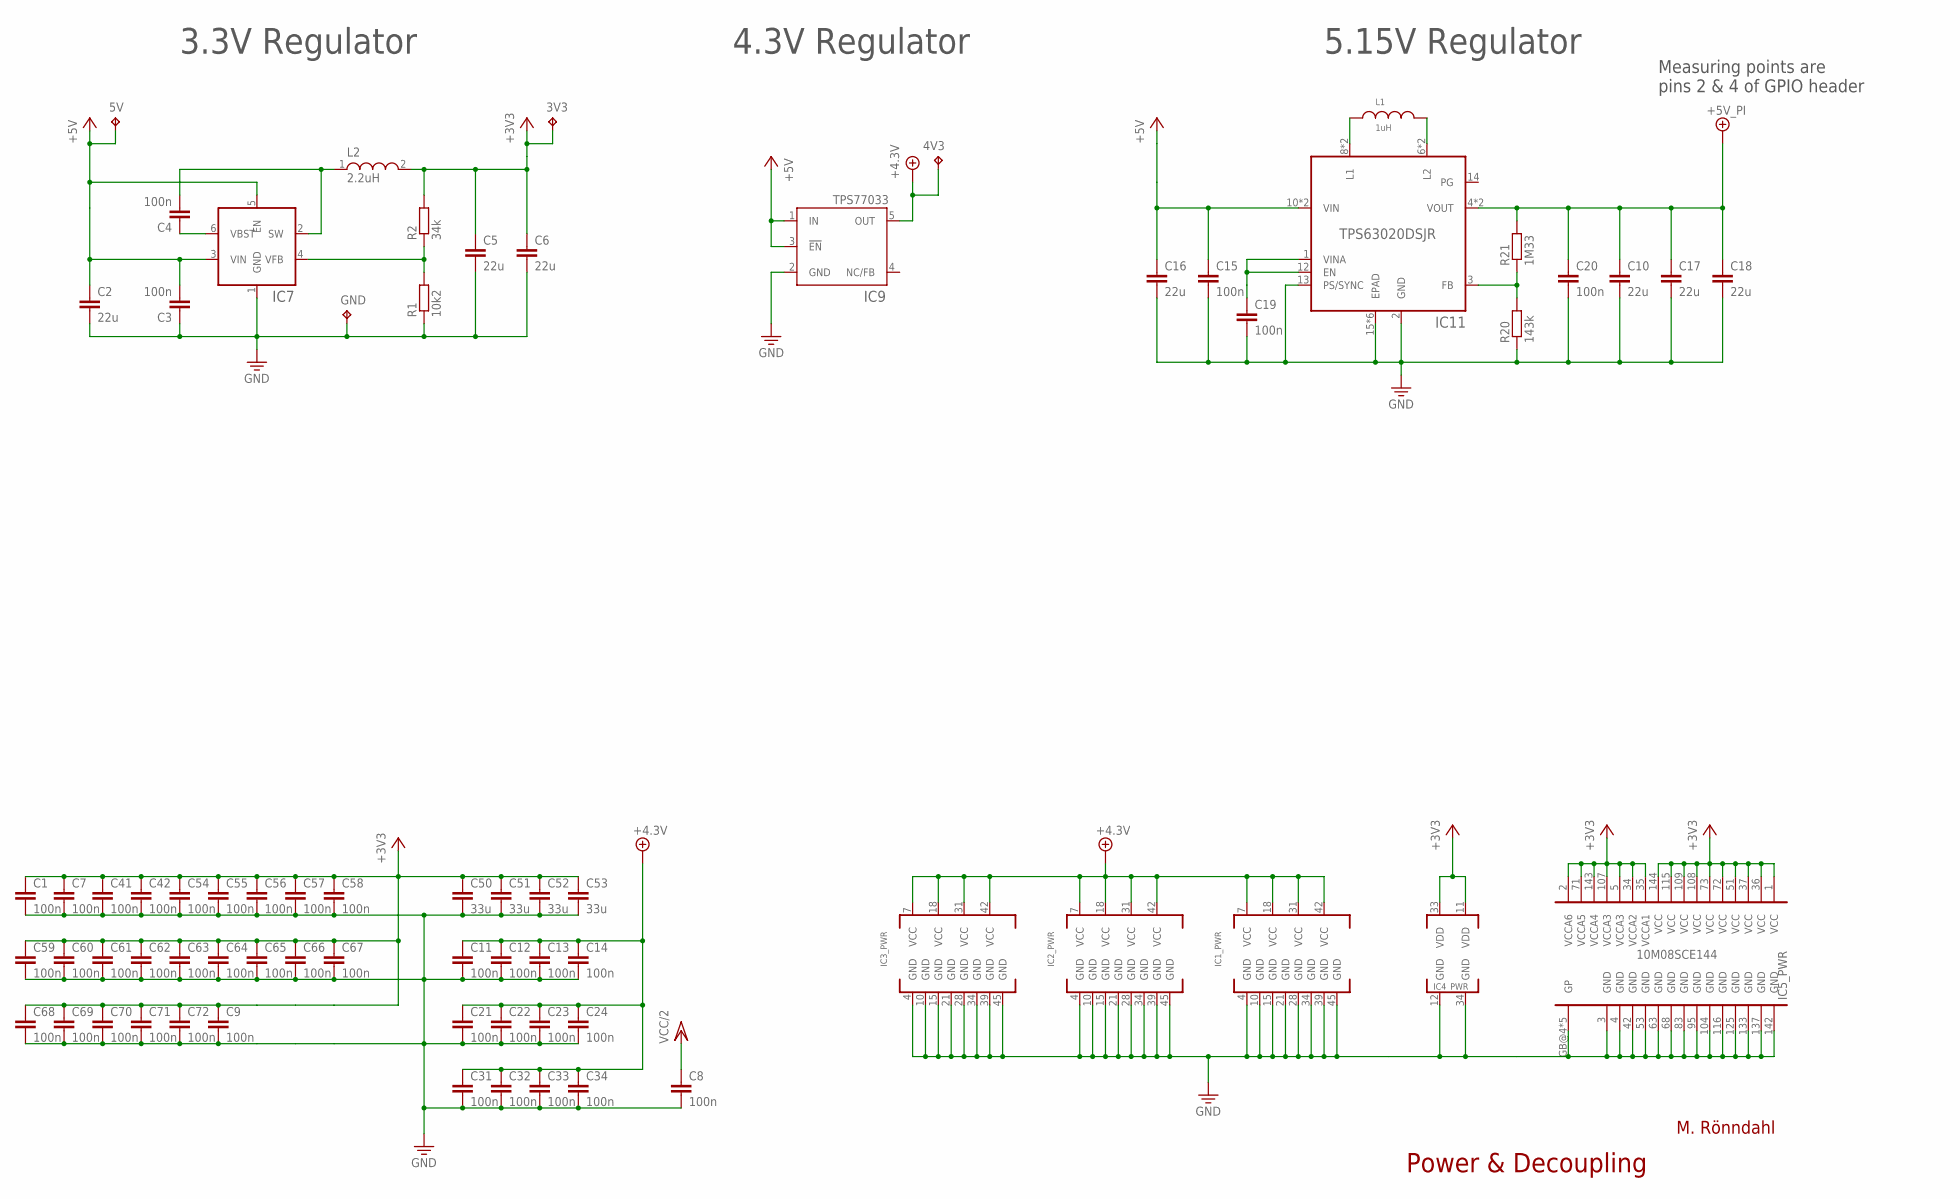
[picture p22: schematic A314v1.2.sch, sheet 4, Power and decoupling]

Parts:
3V3, 4V3, 5V: TPPAD1-13; P1-13
C1, C3, C4, C7, C8, C9, C11, C12, C13, C14, C15, C19, C20, C21, C22, C23, C24, C31, C32, C33, C34, C41, C42, C54, C55, C56, C57, C58, C59, C60, C61, C62, C63, C64, C65, C66, C67, C68, C69, C70, C71, C72: 100n; C0805
C2, C5, C6, C10, C16, C17, C18: 22u; C1812K; MOUSER 810-CGA8P1X7R1E226M
C50, C51, C52, C53: 33u; C0805
GND: TPPAD1-13; P1-13
IC1, IC2, IC3: SN74CBT16244CDL; SSOP-DL48
IC4: IS61WV51216BLL-10TLI; TSOP-2
IC5: 10M08SCE144; SQFP-S-20X20-144
IC7: TPS565208DDC; THIN_SO23; MOUSER 595-TPS565208DDCR
IC9: TPS77033; SOT23-DBV
IC11: TPS63020DSJR; DSJ14_2P85X1P58
L1: 1uH; WE-TPC_6823
L2: 2.2uH; WE-TPC_1028/1038; MOUSER 710-7440650022
R1: 10k2; R0805
R2: 34k; R0805
R20: 143k; R0805
R21: 1M33; R0805

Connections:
+3V3: 3V3.TP, C1.1, C5.1, C6.1, C7.1, C9.1, C41.1, C42.1, C50.1, C51.1, C52.1, C53.1, C54.1, C55.1, C56.1, C57.1, C58.1, C59.1, C60.1, C61.1, C62.1, C63.1, C64.1, C65.1, C66.1, C67.1, C68.1, C69.1, C70.1, C71.1, C72.1, IC4.11 (VDD), IC4.33 (VDD), IC5.1 (VCC), IC5.2 (VCCA6), IC5.5 (VCCA3), IC5.34 (VCCA2), IC5.35 (VCCA1), IC5.36 (VCC), IC5.37 (VCC), IC5.51 (VCC), IC5.71 (VCCA5), IC5.72 (VCC), IC5.73 (VCC), IC5.107 (VCCA3), IC5.108 (VCC), IC5.109 (VCC), IC5.115 (VCC), IC5.143 (VCCA4), IC5.144 (VCC), L2.2, R2.2; also elsewhere on the board
+4.3V: 4V3.TP, C11.1, C12.1, C13.1, C14.1, C21.1, C22.1, C23.1, C24.1, C31.1, C32.1, C33.1, C34.1, IC1.7 (VCC), IC1.18 (VCC), IC1.31 (VCC), IC1.42 (VCC), IC2.7 (VCC), IC2.18 (VCC), IC2.31 (VCC), IC2.42 (VCC), IC3.7 (VCC), IC3.18 (VCC), IC3.31 (VCC), IC3.42 (VCC), IC9.5 (OUT); also elsewhere on the board
+5V: 5V.TP, C2.1, C3.2, C15.2, C16.1, IC7.3 (VIN), IC7.5 (EN), IC9.1 (IN), IC9.3 (!EN), IC11.10 (VIN), IC11.11 (VIN); also elsewhere on the board
+5V/1: C10.1, C17.1, C18.1, C20.2, IC11.4 (VOUT), IC11.5 (VOUT), R21.2; also elsewhere on the board
BST1: C4.1, IC7.6 (VBST)
FB1: IC7.4 (VFB), R1.2, R2.1
FB2: IC11.3 (FB), R20.2, R21.1
GND: C1.2, C2.2, C3.1, C5.2, C6.2, C7.2, C8.2, C9.2, C10.2, C11.2, C12.2, C13.2, C14.2, C15.1, C16.2, C17.2, C18.2, C19.1, C20.1, C21.2, C22.2, C23.2, C24.2, C31.2, C32.2, C33.2, C34.2, C41.2, C42.2, C50.2, C51.2, C52.2, C53.2, C54.2, C55.2, C56.2, C57.2, C58.2, C59.2, C60.2, C61.2, C62.2, C63.2, C64.2, C65.2, C66.2, C67.2, C68.2, C69.2, C70.2, C71.2, C72.2, GND.TP, IC1.4 (GND), IC1.10 (GND), IC1.15 (GND), IC1.21 (GND), IC1.28 (GND), IC1.34 (GND), IC1.39 (GND), IC1.45 (GND), IC2.4 (GND), IC2.10 (GND), IC2.15 (GND), IC2.21 (GND), IC2.28 (GND), IC2.34 (GND), IC2.39 (GND), IC2.45 (GND), IC3.4 (GND), IC3.10 (GND), IC3.15 (GND), IC3.21 (GND), IC3.28 (GND), IC3.34 (GND), IC3.39 (GND), IC3.45 (GND), IC4.12 (GND), IC4.34 (GND), IC5.3 (GND), IC5.4 (GND), IC5.42 (GND), IC5.53 (GND), IC5.63 (GND), IC5.68 (GND), IC5.83 (GND), IC5.95 (GND), IC5.104 (GND), IC5.116 (GND), IC5.125 (GND), IC5.133 (GND), IC5.137 (GND), IC5.142 (GND), IC5.GB@4 (GP), IC5.GP@1 (GP), IC5.GP@2 (GP), IC5.GP@3 (GP), IC5.GP@5 (GP), IC7.1 (GND), IC9.2 (GND), IC11.2 (GND), IC11.13 (PS/SYNC), IC11.15 (EPAD), IC11.V_1 (EPAD), IC11.V_2 (EPAD), IC11.V_3 (EPAD), IC11.V_4 (EPAD), IC11.V_5 (EPAD), R1.1, R20.1; also elsewhere on the board
L1: IC11.8 (L1), IC11.9 (L1), L1.1
L2: IC11.6 (L2), IC11.7 (L2), L1.2
SW: C4.2, IC7.2 (SW), L2.1
VCC/2: C8.1; also elsewhere on the board
VINA: C19.2, IC11.1 (VINA), IC11.12 (EN)

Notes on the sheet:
Power & Decoupling
3.3V Regulator
4.3V Regulator
5.15V Regulator
M. Rönndahl
Measuring points are pins 2 & 4 of GPIO header

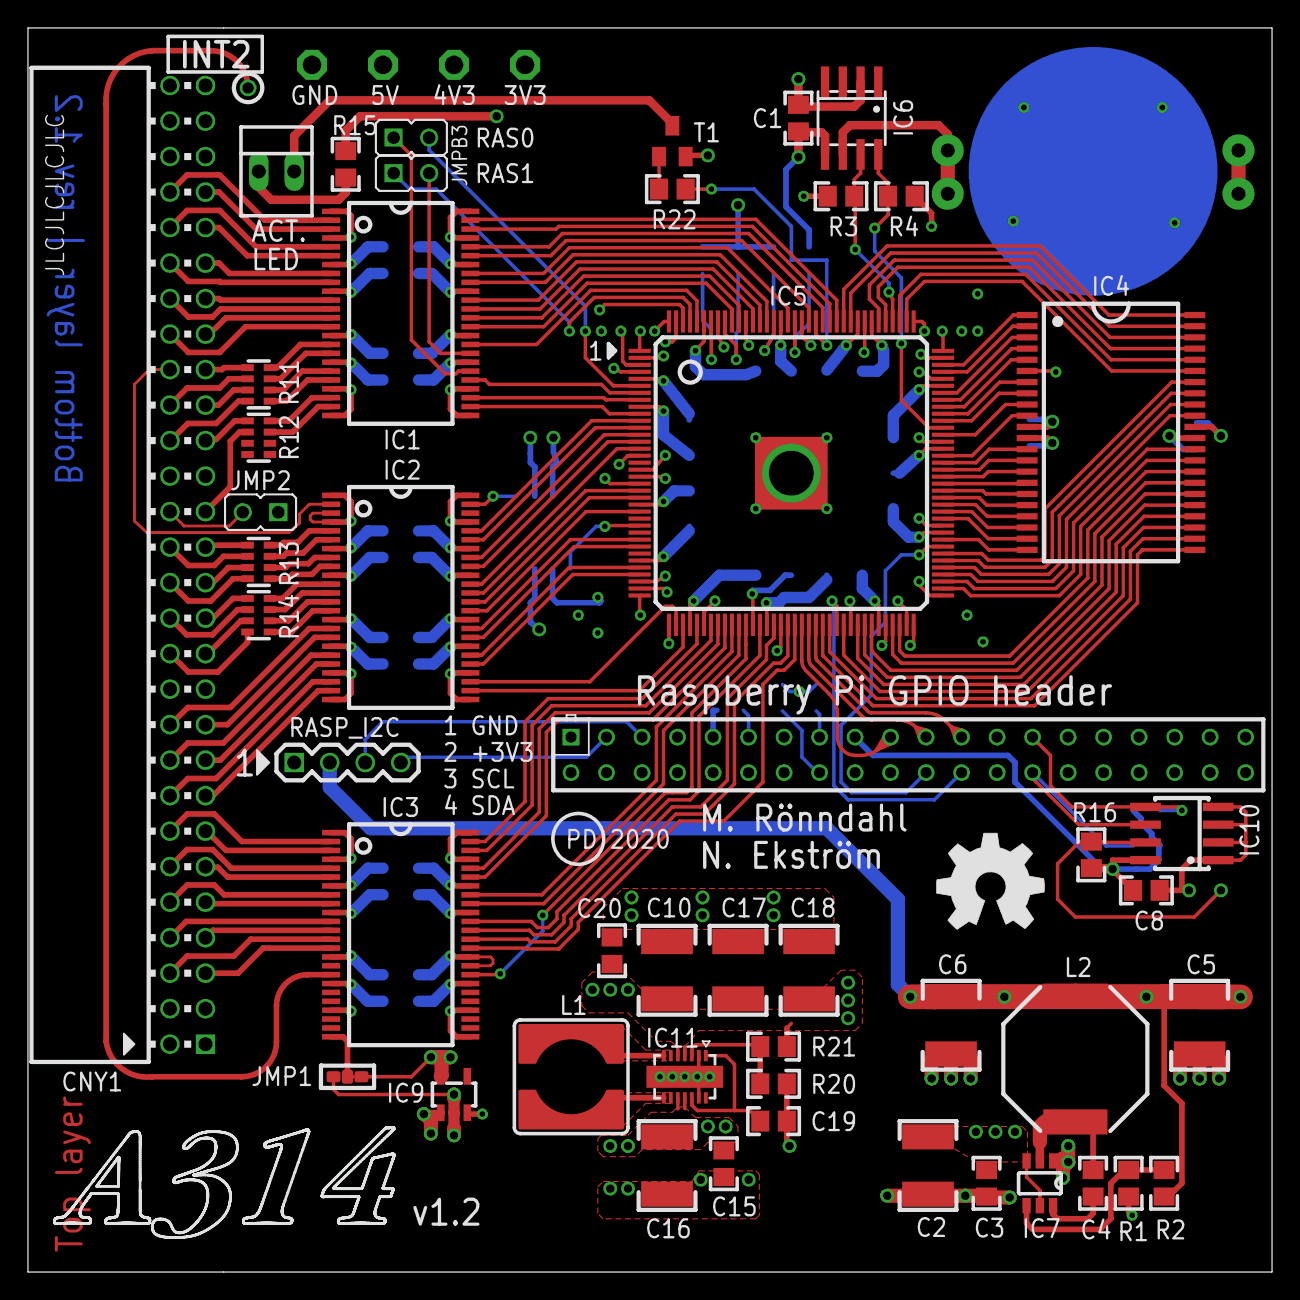
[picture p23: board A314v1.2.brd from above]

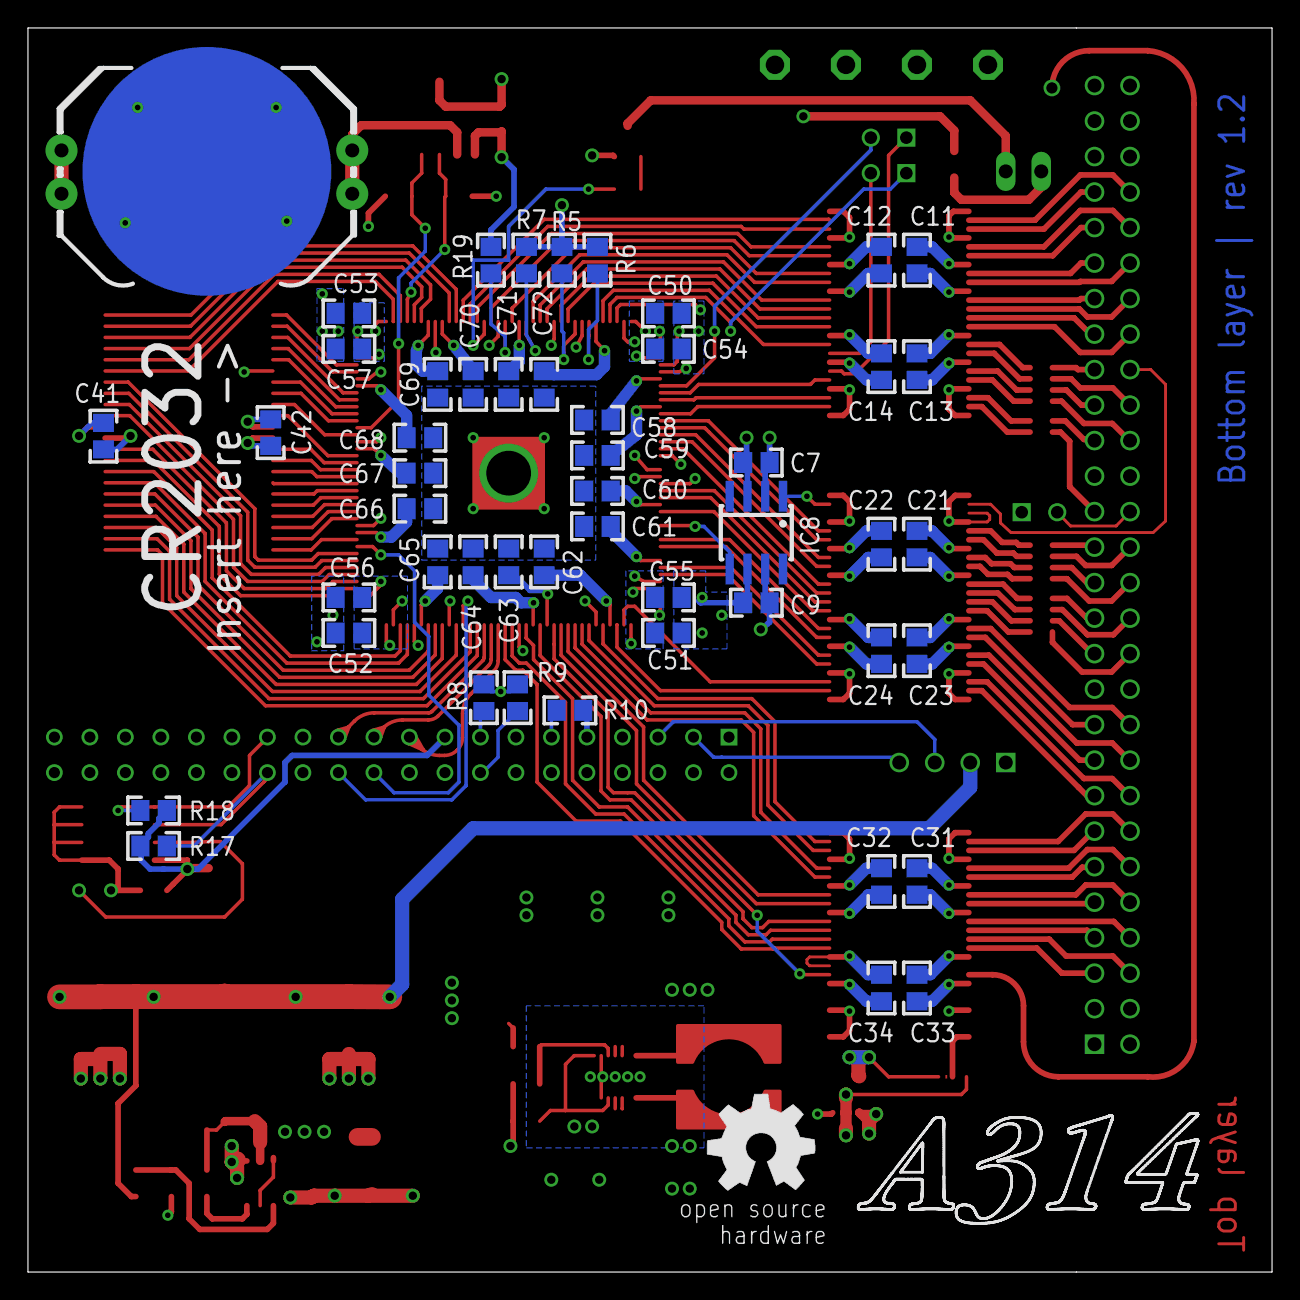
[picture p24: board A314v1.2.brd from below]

Board: 4 copper layers, 89.0 x 89.0 mm, 107 parts (53 on the bottom side), 180 nets.

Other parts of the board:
U$1: OSHW_8_NOTEXT
U$2, U$3: A314_LOGO
U$4: OSHW_8MM

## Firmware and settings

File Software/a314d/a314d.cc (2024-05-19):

/*
 * Copyright (c) 2018-2023 Niklas Ekström
 */

#include <arpa/inet.h>

#include <linux/spi/spidev.h>
#include <linux/types.h>
#include <linux/gpio.h>

#include <netinet/in.h>
#include <netinet/tcp.h>

#include <sys/epoll.h>
#include <sys/ioctl.h>
#include <sys/mman.h>
#include <sys/socket.h>
#include <sys/stat.h>
#include <sys/types.h>

#include <ctype.h>
#include <errno.h>
#include <fcntl.h>
#include <signal.h>
#include <stdint.h>
#include <stdio.h>
#include <stdlib.h>
#include <string.h>
#include <time.h>
#include <unistd.h>

#include <algorithm>
#include <list>
#include <string>
#include <vector>

#if !defined(MODEL_TD) && !defined(MODEL_FE) && !defined(MODEL_CP)
#error Need to define MODEL_TD, MODEL_FE or MODEL_CP
#elif defined(MODEL_TD) && defined(MODEL_FE) || defined(MODEL_TD) && defined(MODEL_CP) || defined(MODEL_FE) && defined(MODEL_CP)
#error The MODEL_XX flags cannot be combined
#endif

#define LOGLEVEL_TRACE      10
#define LOGLEVEL_DEBUG      20
#define LOGLEVEL_INFO       30
#define LOGLEVEL_WARNING    40
#define LOGLEVEL_ERROR      50

static int loglevel = LOGLEVEL_INFO;

#define logger_trace(...) do { if (loglevel <= LOGLEVEL_TRACE) fprintf(stdout, __VA_ARGS__); } while (0)
#define logger_debug(...) do { if (loglevel <= LOGLEVEL_DEBUG) fprintf(stdout, __VA_ARGS__); } while (0)
#define logger_info(...) do { if (loglevel <= LOGLEVEL_INFO) fprintf(stdout, __VA_ARGS__); } while (0)
#define logger_warning(...) do { if (loglevel <= LOGLEVEL_WARNING) fprintf(stdout, __VA_ARGS__); } while (0)
#define logger_error(...) do { if (loglevel <= LOGLEVEL_ERROR) fprintf(stderr, __VA_ARGS__); } while (0)

// Packets that are communicated across physical channels (A2R and R2A).
#define PKT_CONNECT             4
#define PKT_CONNECT_RESPONSE    5
#define PKT_DATA                6
#define PKT_EOS                 7
#define PKT_RESET               8

// Valid responses for PKT_CONNECT_RESPONSE.
#define CONNECT_OK              0
#define CONNECT_UNKNOWN_SERVICE 3

// Messages that are communicated between driver and client.
#define MSG_REGISTER_REQ        1
#define MSG_REGISTER_RES        2
#define MSG_DEREGISTER_REQ      3
#define MSG_DEREGISTER_RES      4
#define MSG_READ_MEM_REQ        5
#define MSG_READ_MEM_RES        6
#define MSG_WRITE_MEM_REQ       7
#define MSG_WRITE_MEM_RES       8
#define MSG_CONNECT             9
#define MSG_CONNECT_RESPONSE    10
#define MSG_DATA                11
#define MSG_EOS                 12
#define MSG_RESET               13

#define MSG_SUCCESS             1
#define MSG_FAIL                0

#define R2A_TAIL_UPDATED        1
#define A2R_HEAD_UPDATED        2

// TODO: These constants should be the same for both TD/FE and CP.
// Need to update a314.device in order to change these.
#if defined(MODEL_TD)
// Offset relative to communication area for queue pointers.
#define A2R_TAIL_OFFSET         0
#define R2A_HEAD_OFFSET         1
#define R2A_TAIL_OFFSET         2
#define A2R_HEAD_OFFSET         3

// Addresses of fixed data structures in shared memory.
#define CAP_BASE                0
#define A2R_BASE                4
#define R2A_BASE                260
#elif defined(MODEL_FE)
// Offset relative to communication area for queue pointers.
#define A2R_TAIL_OFFSET         0
#define R2A_HEAD_OFFSET         1
#define R2A_TAIL_OFFSET         2
#define A2R_HEAD_OFFSET         3

// Addresses of fixed data structures in shared memory.
#define HANDSHAKE_BASE          0
#define CAP_BASE                4
#define A2R_BASE                8
#define R2A_BASE                264
#elif defined(MODEL_CP)
// Offset relative to communication area for queue pointers.
#define R2A_TAIL_OFFSET         0
#define A2R_HEAD_OFFSET         1
#define A2R_TAIL_OFFSET         2
#define R2A_HEAD_OFFSET         3

// Addresses of fixed data structures in shared memory.
#define A2R_BASE                0
#define R2A_BASE                256
#define CAP_BASE                512
#endif

#if defined(MODEL_TD)
#define IRQ_GPIO                25
#define IRQ_GPIO_EDGE           GPIO_V2_LINE_FLAG_EDGE_RISING | GPIO_V2_LINE_FLAG_EDGE_FALLING
#elif defined(MODEL_FE)
#define IRQ_GPIO                23
#define IRQ_GPIO_EDGE           GPIO_V2_LINE_FLAG_EDGE_RISING
#elif defined(MODEL_CP)
#define IRQ_GPIO                2
#define IRQ_GPIO_EDGE           GPIO_V2_LINE_FLAG_EDGE_RISING
#endif

#if defined(MODEL_TD)
// SPI commands.
#define READ_SRAM_CMD           0
#define WRITE_SRAM_CMD          1
#define READ_CMEM_CMD           2
#define WRITE_CMEM_CMD          3
#define SPI_PROTO_VER_CMD       255

#define READ_SRAM_HDR_LEN       4

// Addresses to variables in CMEM.
#define BASE_ADDRESS_LEN        6
#define R_EVENTS_ADDRESS        12
#define R_ENABLE_ADDRESS        13
#define A_EVENTS_ADDRESS        14
#define A_ENABLE_ADDRESS        15

// Events that are communicated via IRQ from Amiga to Raspberry.
#define R_EVENT_A2R_TAIL        1
#define R_EVENT_R2A_HEAD        2
#define R_EVENT_BASE_ADDRESS    4

// Events that are communicated from Raspberry to Amiga.
#define A_EVENT_R2A_TAIL        1
#define A_EVENT_A2R_HEAD        2

#elif defined(MODEL_FE)
#define PIN_D(x)                (4 + x)
#define PIN_WR                  20
#define PIN_REQ                 21
#define PIN_ACK                 22
#define PIN_IRQ                 23
#define PIN_A(x)                (24 + x)

#define GPIO_DIR_0_MASK         0x3ffff000
#define GPIO_DIR_0_DIN          0x00000000
#define GPIO_DIR_0_DOUT         0x09249000
#define GPIO_DIR_1_MASK         0x3fffffff
#define GPIO_DIR_1_DIN          0x00000000
#define GPIO_DIR_1_DOUT         0x09249249
#define GPIO_DIR_2_MASK         0x00ffffff
#define GPIO_DIR_2              0x00249009

#define GPIO_PULL_NONE          0
#define GPIO_PULL_DOWN          1
#define GPIO_PULL_UP            2

#define REG_SRAM_BYTE           0
#define REG_SRAM_WORD           1
#define REG_ADDR_LO             2
#define REG_ADDR_HI             3
#define REG_INT_REQ             4
#define REG_INT_ENA             5
#define REG_CA_BASE_ADDR        6

#define IRQ_SET                 0x8000
#define IRQ_CLR                 0x0000
#define IRQ_R2A_TAIL            0x0001
#define IRQ_A2R_HEAD            0x0002
#define IRQ_A2R_TAIL            0x0004
#define IRQ_R2A_HEAD            0x0008
#define IRQ_BASE_ADDRESS        0x0010

#elif defined(MODEL_CP)
#define PIN_IRQ                 2
#define PIN_CLK                 4
#define PIN_REQ                 14
#define PIN_ACK                 15
#define PIN_D(x)                (16 + x)
#define PIN_A(x)                (24 + x)
#define PIN_WR                  27

#define PINS_OUT            ((0xff << PIN_D(0)) | (3 << PIN_A(0)) | (1 << PIN_WR) | (1 << PIN_REQ))
#define PINS_OUT_NOT_WR     ((0xff << PIN_D(0)) | (3 << PIN_A(0)) | (1 << PIN_REQ))

#define GPIO_DIR_0              0x08004000
#define GPIO_DIR_0_MASK         0x3f0071c0
#define GPIO_DIR_1_DIN          0x00001009
#define GPIO_DIR_1_DOUT         0x09241009
#define GPIO_DIR_2_DIN          0x08209000
#define GPIO_DIR_2_DOUT         0x08209249

#define GPIO_PULL_NONE          0
#define GPIO_PULL_DOWN          1
#define GPIO_PULL_UP            2

#define REG_SRAM                0
#define REG_IRQ                 1
#define REG_ADDR_LO             2
#define REG_ADDR_HI             3

#define REG_IRQ_SET             0x80
#define REG_IRQ_CLR             0x00
#define REG_IRQ_PI              0x02
#define REG_IRQ_CP              0x01
#endif

// Global variables.
static sigset_t original_sigset;

static uint8_t tx_buf[65536];
static uint8_t rx_buf[65536];

static volatile unsigned int *gpio;

#if defined(MODEL_TD)
static uint8_t mode = SPI_CS_HIGH;
static uint8_t bits = 8;
static uint32_t speed = 67000000;

static int spi_fd = -1;
static int spi_proto_ver = 0;
#elif defined(MODEL_FE)
static unsigned int current_address;
static int current_dir = 0; // 0 = input, 1 = output.
#elif defined(MODEL_CP)
static unsigned short current_address;
static int current_dir = 0; // 0 = input, 1 = output.

static bool read_a314_magic = false;
static int restart_counter;
#endif

static int gpio_irq_fd = -1;

static bool auto_clear_irq = false;
static time_t auto_clear_irq_after;

static int server_socket = -1;

static int epfd = -1;

static bool have_base_address = false;
static unsigned int base_address = 0;

#if defined(MODEL_TD) || defined(MODEL_FE)
#define BASE_ADDRESS base_address
#elif defined(MODEL_CP)
#define BASE_ADDRESS 0
#endif

static uint8_t channel_status[4];
static uint8_t channel_status_updated = 0;

static uint8_t recv_buf[256];
static uint8_t send_buf[256];

struct LogicalChannel;
struct ClientConnection;

#pragma pack(push, 1)
struct MessageHeader
{
    uint32_t length;
    uint32_t stream_id;
    uint8_t type;
}; //} __attribute__((packed));
#pragma pack(pop)

struct MessageBuffer
{
    int pos;
    std::vector<uint8_t> data;
};

struct RegisteredService
{
    std::string name;
    ClientConnection *cc;
};

struct PacketBuffer
{
    int type;
    std::vector<uint8_t> data;
};

struct ClientConnection
{
    int fd;

    int next_stream_id;

    int bytes_read;
    MessageHeader header;
    std::vector<uint8_t> payload;

    std::list<MessageBuffer> message_queue;

    std::list<LogicalChannel*> associations;
};

struct LogicalChannel
{
    int channel_id;

    ClientConnection *association;
    int stream_id;

    bool got_eos_from_ami;
    bool got_eos_from_client;

    std::list<PacketBuffer> packet_queue;
};

static void remove_association(LogicalChannel *ch);
static void clear_packet_queue(LogicalChannel *ch);
static void create_and_enqueue_packet(LogicalChannel *ch, uint8_t type, uint8_t *data, uint8_t length);

static std::list<ClientConnection> connections;
static std::list<RegisteredService> services;
static std::list<LogicalChannel> channels;
static std::list<LogicalChannel*> send_queue;

struct OnDemandStart
{
    std::string service_name;
    std::string program;
    std::vector<std::string> arguments;
};

std::vector<OnDemandStart> on_demand_services;

static void load_config_file(const char *filename)
{
    FILE *f = fopen(filename, "rt");
    if (f == nullptr)
        return;

    char line[256];
    std::vector<char *> parts;

    while (fgets(line, 256, f) != nullptr)
    {
        char org_line[256];
        strcpy(org_line, line);

        bool in_quotes = false;

        int start = 0;
        for (int i = 0; i < 256; i++)
        {
            if (line[i] == 0)
            {
                if (start < i)
                    parts.push_back(&line[start]);
                break;
            }
            else if (line[i] == '"')
            {
                line[i] = 0;
                if (in_quotes)
                    parts.push_back(&line[start]);
                in_quotes = !in_quotes;
                start = i + 1;
            }
            else if (isspace(line[i]) && !in_quotes)
            {
                line[i] = 0;
                if (start < i)
                    parts.push_back(&line[start]);
                start = i + 1;
            }
        }

        if (parts.size() >= 2)
        {
            on_demand_services.emplace_back();
            auto &e = on_demand_services.back();
            e.service_name = parts[0];
            e.program = parts[1];
            for (int i = 1; i < parts.size(); i++)
                e.arguments.push_back(std::string(parts[i]));
        }
        else if (parts.size() != 0)
            logger_warning("Invalid number of columns in configuration file line: %s\n", org_line);

        parts.clear();
    }

    fclose(f);

    if (on_demand_services.empty())
        logger_warning("No registered services\n");
}

#if defined(MODEL_TD)
static int init_spi()
{
    spi_fd = open("/dev/spidev0.0", O_RDWR | O_CLOEXEC);
    if (spi_fd < 0)
        return -1;

    int ret = ioctl(spi_fd, SPI_IOC_WR_MODE, &mode);
    ret |= ioctl(spi_fd, SPI_IOC_WR_BITS_PER_WORD, &bits);
    ret |= ioctl(spi_fd, SPI_IOC_WR_MAX_SPEED_HZ, &speed);
    if (ret != 0)
        return ret;

    return 0;
}

static void shutdown_spi()
{
    if (spi_fd != -1)
        close(spi_fd);
}

static int check_spidev_bufsiz()
{
    int fd = open("/sys/module/spidev/parameters/bufsiz", O_RDONLY);
    if (fd == -1)
        return -1;

    char buf[32];
    auto actual = read(fd, buf, strlen(buf));

    close(fd);

    if (strncmp(buf, "65536", actual) != 0)
        return -2;

    return 0;
}

static int spi_transfer(int len)
{
    struct spi_ioc_transfer tr =
    {
        .tx_buf = (uintptr_t)tx_buf,
        .rx_buf = (uintptr_t)rx_buf,
        .len = (uint32_t)len,
        .speed_hz = speed,
        .delay_usecs = 0,
        .bits_per_word = bits,
        .cs_change = 0,
    };

    return ioctl(spi_fd, SPI_IOC_MESSAGE(1), &tr);
}

static int spi_protocol_version()
{
    tx_buf[0] = (uint8_t)SPI_PROTO_VER_CMD;
    tx_buf[1] = 0;
    spi_transfer(2);
    logger_trace("SPI protocol version = %d\n", rx_buf[1]);
    return (int)rx_buf[1];
}

static void spi_read_shm_rxbuf(unsigned int address, unsigned int length)
{
    logger_trace("SPI read mem address = %d length = %d\n", address, length);

    unsigned int header;
    if (spi_proto_ver == 1)
        header = (READ_SRAM_CMD << 21) | (address & 0x1fffff);
    else
        header = (READ_SRAM_CMD << 20) | (address & 0xfffff);

    tx_buf[0] = (uint8_t)((header >> 16) & 0xff);
    tx_buf[1] = (uint8_t)((header >> 8) & 0xff);
    tx_buf[2] = (uint8_t)(header & 0xff);
	tx_buf[3] = 0;

    spi_transfer(length + 4);
}

static void spi_read_shm(unsigned char *data, unsigned int address, unsigned int length)
{
    spi_read_shm_rxbuf(address, length);
    memcpy(data, &rx_buf[READ_SRAM_HDR_LEN], length);
}

static void spi_write_shm(unsigned int address, uint8_t *buf, unsigned int length)
{
    logger_trace("SPI write mem address = %d length = %d\n", address, length);

    unsigned int header;
    if (spi_proto_ver == 1)
        header = (WRITE_SRAM_CMD << 21) | (address & 0x1fffff);
    else
        header = (WRITE_SRAM_CMD << 20) | (address & 0xfffff);

    tx_buf[0] = (uint8_t)((header >> 16) & 0xff);
    tx_buf[1] = (uint8_t)((header >> 8) & 0xff);
    tx_buf[2] = (uint8_t)(header & 0xff);

    memcpy(&tx_buf[3], buf, length);
    spi_transfer(length + 3);
}

static uint8_t spi_read_cmem(unsigned int address)
{
    if (spi_proto_ver == 1)
        tx_buf[0] = (uint8_t)((READ_CMEM_CMD << 5) | (address & 0xf));
    else
        tx_buf[0] = (uint8_t)((READ_CMEM_CMD << 4) | (address & 0xf));
    tx_buf[1] = 0;
    spi_transfer(2);
    logger_trace("SPI read cmem, address = %d, returned = %d\n", address, rx_buf[1]);
    return rx_buf[1];
}

static void spi_write_cmem(unsigned int address, unsigned int data)
{
    logger_trace("SPI write cmem, address = %d, data = %d\n", address, data);

    if (spi_proto_ver == 1)
        tx_buf[0] = (uint8_t)((WRITE_CMEM_CMD << 5) | (address & 0xf));
    else
        tx_buf[0] = (uint8_t)((WRITE_CMEM_CMD << 4) | (address & 0xf));
    tx_buf[1] = (uint8_t)(data & 0xf);
    spi_transfer(2);
}

static uint8_t spi_ack_irq()
{
    logger_trace("SPI ack_irq\n");
    return spi_read_cmem(R_EVENTS_ADDRESS);
}

static void spi_read_base_address()
{
    have_base_address = false;

    unsigned int ba1 = 0;
    for (int i = 0; i < BASE_ADDRESS_LEN; i++)
        ba1 |= spi_read_cmem(i) << (i * 4);

    if ((ba1 & 1) == 1)
    {
        unsigned int ba2 = 0;
        for (int i = 0; i < BASE_ADDRESS_LEN; i++)
            ba2 |= spi_read_cmem(i) << (i * 4);

        if (ba1 == ba2)
        {
            have_base_address = true;
            base_address = ba1 & ~1;
        }
    }
}

#define read_shm spi_read_shm
#define write_shm spi_write_shm
#endif

#if defined(MODEL_FE) || defined(MODEL_CP)
static int create_dev_gpiomem_mapping()
{
    int fd = open("/dev/gpiomem", O_RDWR | O_SYNC);
    if (fd < 0)
    {
        logger_error("Unable to open /dev/gpiomem\n");
        return -1;
    }

    void *gpio_map = mmap(NULL, 4096, PROT_READ | PROT_WRITE, MAP_SHARED, fd, 0);

    close(fd);

    if (gpio_map == MAP_FAILED)
    {
        logger_error("mmap failed, errno = %d\n", errno);
        return -1;
    }

    gpio = (volatile unsigned int *)gpio_map;
    return 0;
}

static void set_gpio_pull_mode(int mask, int mode)
{
    *(gpio + 37) = mode;
    usleep(50);
    *(gpio + 38) = mask;
    usleep(50);
    *(gpio + 38) = 0;
    *(gpio + 37) = 0;
    usleep(50);
}
#endif

#if defined(MODEL_FE)
static inline void set_dir_read()
{
    if (current_dir == 1)
    {
        *(gpio + 0) = (*(gpio + 0) & ~GPIO_DIR_0_MASK) | GPIO_DIR_0_DIN;
        *(gpio + 1) = GPIO_DIR_1_DIN;
        current_dir = 0;
    }
}

static inline void set_dir_write()
{
    if (current_dir == 0)
    {
        *(gpio + 0) = (*(gpio + 0) & ~GPIO_DIR_0_MASK) | GPIO_DIR_0_DOUT;
        *(gpio + 1) = GPIO_DIR_1_DOUT;
        current_dir = 1;
    }
}

static unsigned int read_sram_reg(unsigned int reg)
{
    set_dir_read();

    *(gpio + 7) = (reg << PIN_A(0)) | (1 << PIN_REQ);

    // Delay so that the ACK pin is sure to be negated after previous access.
    *(gpio + 7) = 0;
    *(gpio + 7) = 0;
    *(gpio + 7) = 0;
    *(gpio + 7) = 0;

    // Additional delay to hopefully do only one read when there is no contention.
    *(gpio + 7) = 0;
    *(gpio + 7) = 0;
    *(gpio + 7) = 0;

    unsigned int value;
    while (!((value = *(gpio + 13)) & (1 << PIN_ACK)))
        ;

    value = (value >> PIN_D(0)) & 0xffff;

    *(gpio + 10) = (1 << PIN_REQ);
    *(gpio + 10) = (15 << PIN_A(0)) | (1 << PIN_WR) | (0xffff << PIN_D(0));

    return value;
}

static void write_sram_reg(unsigned int reg, unsigned int value)
{
    set_dir_write();

    *(gpio + 7) = (reg << PIN_A(0)) | (1 << PIN_REQ) | (1 << PIN_WR) | ((value & 0xffff) << PIN_D(0));

    // Delay so that the ACK pin is sure to be negated after previous access.
    *(gpio + 7) = 0;
    *(gpio + 7) = 0;
    *(gpio + 7) = 0;
    *(gpio + 7) = 0;

    // Additional delay to hopefully do only one read when there is no contention.
    *(gpio + 7) = 0;
    *(gpio + 7) = 0;
    *(gpio + 7) = 0;

    while (!(*(gpio + 13) & (1 << PIN_ACK)))
        ;

    *(gpio + 10) = (1 << PIN_REQ);
    *(gpio + 10) = (15 << PIN_A(0)) | (1 << PIN_WR) | (0xffff << PIN_D(0));
}

static unsigned int read_reg(unsigned int reg)
{
    set_dir_read();

    *(gpio + 7) = (reg << PIN_A(0)) | (1 << PIN_REQ);
    *(gpio + 7) = 0;
    *(gpio + 7) = 0;
    *(gpio + 7) = 0;

    unsigned int value = *(gpio + 13);
    value = (value >> PIN_D(0)) & 0xffff;

    *(gpio + 10) = (1 << PIN_REQ);
    *(gpio + 7) = 0;
    *(gpio + 10) = (15 << PIN_A(0)) | (1 << PIN_WR) | (0xffff << PIN_D(0));

    return value;
}

static void write_reg(unsigned int reg, unsigned int value)
{
    set_dir_write();

    *(gpio + 7) = (reg << PIN_A(0)) | (1 << PIN_REQ) | (1 << PIN_WR) | ((value & 0xffff) << PIN_D(0));
    *(gpio + 7) = 0;
    *(gpio + 10) = (1 << PIN_REQ);
    *(gpio + 7) = 0;
    *(gpio + 10) = (15 << PIN_A(0)) | (1 << PIN_WR) | (0xffff << PIN_D(0));
}

static void set_address(unsigned int address)
{
    if ((address & 0xffff) != (current_address & 0xffff))
        write_reg(REG_ADDR_LO, address & 0xffff);

    if (((address >> 16) & 0x3) != ((current_address >> 16) & 0x3))
        write_reg(REG_ADDR_HI, (address >> 16) & 0x3);

    current_address = address;
}

static void gpio_read_shm(unsigned char *data, unsigned int address, unsigned int length)
{
    set_address(address);

    current_address = (address + length) & 0x3ffff;

    unsigned int v;

    if (address & 1)
    {
        v = read_sram_reg(REG_SRAM_BYTE);
        *data++ = v & 0xff;
        length--;
    }

    while (length >= 2)
    {
        v = read_sram_reg(REG_SRAM_WORD);
        *data++ = (v >> 8) & 0xff;
        *data++ = v & 0xff;
        length -= 2;
    }

    if (length)
    {
        v = read_sram_reg(REG_SRAM_BYTE);
        *data++ = (v >> 8) & 0xff;
    }
}

static void gpio_write_shm(unsigned int address, unsigned char *data, unsigned int length)
{
    set_address(address);

    current_address = (address + length) & 0x3ffff;

    unsigned int v;

    if (address & 1)
    {
        v = *data++;
        write_sram_reg(REG_SRAM_BYTE, v);
        length--;
    }

    while (length >= 2)
    {
        v = ((*data++) << 8) | (*data++);
        write_sram_reg(REG_SRAM_WORD, v);
        length -= 2;
    }

    if (length)
    {
        v = (*data++) << 8;
        write_sram_reg(REG_SRAM_BYTE, v);
    }
}

#define write_shm gpio_write_shm
#define read_shm gpio_read_shm
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
int main(int argc, char **argv)
{
    std::string conf_filename("/etc/opt/a314/a314d.conf");

    int used_args = 1;

    if (argc >= 3 && strcmp(argv[1], "--loglevel") == 0)
    {
        used_args += 2;
        if (strcasecmp(argv[2], "trace") == 0) loglevel = LOGLEVEL_TRACE;
        else if (strcasecmp(argv[2], "debug") == 0) loglevel = LOGLEVEL_DEBUG;
        else if (strcasecmp(argv[2], "info") == 0) loglevel = LOGLEVEL_INFO;
        else if (strcasecmp(argv[2], "warning") == 0) loglevel = LOGLEVEL_WARNING;
        else if (strcasecmp(argv[2], "error") == 0) loglevel = LOGLEVEL_ERROR;
        else fprintf(stderr, "Invalid log level '%s', defaulting to INFO\n", argv[2]);
    }

    if (argc > used_args)
        conf_filename = argv[used_args];

    load_config_file(conf_filename.c_str());

    if (init_driver() == 0)
        main_loop();
    shutdown_driver();
    return 0;
}

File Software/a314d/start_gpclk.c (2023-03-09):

#include <errno.h>
#include <fcntl.h>
#include <stddef.h>
#include <stdio.h>
#include <stdlib.h>
#include <string.h>
#include <sys/mman.h>
#include <sys/stat.h>
#include <sys/types.h>
#include <unistd.h>
#include <time.h>

#include <bcm_host.h>

#define GPIO_ADDR 0x200000
#define GPCLK_ADDR 0x101000

#define CLK_GP0_CTL 0x070
#define CLK_GP0_DIV 0x074

#define CTL_PASSWD (0x5a << 24)
#define CTL_BUSY (1 << 7)
#define CTL_KILL (1 << 5)
#define CTL_ENAB (1 << 4)

#define CTL_SRC_PLLC 5
#define CTL_SRC_PLLD 6

volatile unsigned int *gpio;
volatile unsigned int *gpclk;

static void create_dev_mem_mapping(size_t base, size_t size)
{
    int fd = open("/dev/mem", O_RDWR | O_SYNC);
    if (fd < 0)
    {
        printf("Unable to open /dev/mem. Run as root using sudo?\n");
        exit(-1);
    }

    void *gpio_map = mmap(NULL, size, PROT_READ | PROT_WRITE, MAP_SHARED, fd, base);

    close(fd);

    if (gpio_map == MAP_FAILED)
    {
        printf("mmap failed, errno = %d\n", errno);
        exit(-1);
    }

    gpio = ((volatile unsigned *)gpio_map) + GPIO_ADDR / 4;
    gpclk = ((volatile unsigned *)gpio_map) + GPCLK_ADDR / 4;
}

static void start_gpclk(int divisor)
{
    volatile unsigned int *ctl = gpclk + (CLK_GP0_CTL / 4);
    volatile unsigned int *div = gpclk + (CLK_GP0_DIV / 4);

    *ctl = CTL_PASSWD | CTL_KILL;
    usleep(10);
    while (*ctl & CTL_BUSY)
        ;
    usleep(100);
    *div = CTL_PASSWD | (divisor << 12);
    usleep(10);
    *ctl = CTL_PASSWD | CTL_ENAB | CTL_SRC_PLLC;
    usleep(10);
    while (!(*ctl & CTL_BUSY))
        ;
    usleep(100);

    // GPIO pin 4 takes alternate function 0 (GPCLK0).
    *(gpio + 0) = (*(gpio + 0) & ~0x00007000) | 0x00004000;
}

int main(int argc, char **argv)
{
    size_t base = bcm_host_get_peripheral_address();
    size_t size = bcm_host_get_peripheral_size();

    create_dev_mem_mapping(base, size);

    int requested_mhz = 90;

    if (argc > 1)
    {
        requested_mhz = atoi(argv[1]);
        if (requested_mhz < 10 || requested_mhz > 200)
        {
            printf("Requested clock frequency \"%d\" (MHz) is outside of range 10..200\n", requested_mhz);
            return 0;
        }
    }

    int divisor = (1200 + requested_mhz - 1) / requested_mhz;
    int actual_mhz = 1200 / divisor;
    if (actual_mhz == requested_mhz)
        printf("Starting GPCLK0 with frequency=%d, divisor=%d\n", actual_mhz, divisor);
    else
        printf("Starting GPCLK0 with frequency=%d (requested=%d), divisor=%d\n", actual_mhz, requested_mhz, divisor);

    start_gpclk(divisor);

    return 0;
}

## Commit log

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2019-03-20 Initial commit of hardware related files
    [A314B2.brd, A314B2.sch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]
2019-03-23 Added pi command, that lets the user execute commands in the raspberry from the Amiga CLI.
2019-03-27 Request and wait for a window bounds report before sending the startup message to the raspberry.
2019-03-30 The IRQ GPIO pin was changed from GPIO 19 to GPIO 25 on PCB beta 2.
2019-03-31 Added support in driver for INT2 interrupt handling. The idea is that this should lead to lower latency than using periodic polling using the VERTB interrupt.
2019-04-02 Only signal driver task if both a bit in A_EVENTS and A_ENABLE are set. Note that, currently, the driver relies on the vblank interrupt server for correctness; there is a sequence of events such that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
2019-04-04 Rewrote how interrupts are handled. Vblank and INT2 interrupts are now handled uniformly. Reads and writes of CMEM registers are now guarded by Disable()/Enable() pairs, which my make the code slight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
2019-04-22 Fixes handling of base address so that a314d can differentiate between base address zero and the case when no base address has been written. Also makes reading the base address atomic relative to a w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
    [a314d.cc]
2019-04-22 Missed a small change. Fixes #8.
    [a314d.cc]
2019-04-23 Fixed handling of how logical channels are closed, for example due to a pair of EOSs. Could be further improved by separating the socket and the logical channel into two different objects.
2019-04-28 Added CAD and Gerbers for v1.0 of the PCB
    Issue #5 and #9 were resolved, and the PCB promoted from Beta-2 to v1.0
    [A314v1.brd, A314v1.sch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]
2019-04-30 Added BOM
    Bill of Materials with part# references to DigiKey. The project is not affiliated with DigiKey, we just though it was convinient to use one-stop-shopping. You can find these parts elesewhere, most pr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
2019-07-18 Added ability to play audio from RPi with Amiga as audio output device. You need to first run piaudio on the Amiga, which connects to piaudio.py that is running on the RPi. Then you can do 'pi mpg123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
2019-08-17 Support for A500+.
    These changes let A314 work in an A500+, providing an additional 1MB of chip ram for a total of 2MB chip.
    The SPI protocol had to be modified so that addresses are sent as 20 bits instead of 19 bits, so that the entire 1MB of SRAM can be addressed.
    The GetA314MemBase() API function exposed by a314.device was replaced with a more general TranslateAddressA314() function. All applications that previously used GetA314MemBase() had to be updated. This fixes #12.
    At this time a small change needs to be made in HDL/a314_top.v at line 107, and the Verilog then needs to be recompiled and written to the FPGA, in order to use A314 in an A500+. The reason is that when A314 is used in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
    [a314d.cc]
2019-09-14 Set weak pull-up on RAS0
    This change enables an internal (to the FPGA) weak pull-up on the RAS0 pin.
    Once #11 is implemented in hardware, the RAS0 pin on the FPGA will either be
    connected to the RAS0 pin on the trapdoor connector or be disconnected.
    If RAS0 is disconnected then the weak pull-up makes sure the RAS0 is inactive.
2019-09-25 PCB Update (1.1) that addresses issues #10 and #11
    This is a minor update that will allow for a single firmware to serve all A500 motherboards up to rev.8.
    A500+ owners will get an additional 1MB of chipram, previous boards (up to rev.6) will use ½MB.
    [A314v1.1.brd, A314v1.1.sch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]
2019-10-05 Added Makefile that builds software
    The rpi_docker_build.sh script uses a public docker image containing vbcc
    to build all software to Software/bin using the makefile on a Raspberry Pi.
    To use the script, docker must first be installed on the RPi.
    sudo make install copies all RPi files into the appropriate directories.
    After that, the a314d daemon is enabled using:
    sudo systemctl daemon-reload
    sudo systemctl enable a314d
    sudo systemctl start a314d
    This commit addresses #15, but doesn't remove the binaries yet.
2019-10-27 Added instructions for installing software
    The instructions will build and install software for both Raspberry Pi and Amiga.
2020-02-22 Refactored a314.device
    Refactored a314.device by grouping related procedures and moving them to new
    source code files.
    No functional changes were made.
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2020-04-12 Added remote-mouse service
    The remote-mouse service takes input events from a mouse connected to the Pi
    from /dev/input/mice, and feeds the events to input.device on the Amiga.
    You may want to disable the mouse in X11 if your Pi is running a GUI.
    Use the command "xinput list" to find the id of your mouse to disable,
    and then use "xinput --disable <id>".
2020-04-20 Added PCB v1.2 and related documents
    Updated the Hardware folder with PCB files for v1.2
    [A314v1.2.brd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]
2020-06-30 Update A314-500 v1.2 BOM.pdf
    Correction of resistor amount
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2020-08-07 Set weak pull-up on RAS1
    With the v1.2 PCB it is possible to change how the RAS signals are mapped
    between the motherboard and A314. As RAS1 may then be disconnected it has to be
    weakly pulled up by the FPGA in order to not be left in an undeterminate state.
2020-08-07 Unused RegA slots return zero
    Previously any unused RegA slot would return the firmware version number.
    This should have been harmless since before reading a RegA slot other than the
    version number the driver should read the firmware version number to figure out
    if a particular slot is implemented or not.
    Nevertheless, with this change, reading from an unused slot returns zero.
2020-08-20 Amiga 600 version PCB and BOM
    [A314-600_v1.0.brd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]
2020-08-20 Added support for A314-600 to master branch
    Previously there was a separate branch for the A600 version of A314, but this
    functionality has now been merged into the master branch.
    A new revision, a314_600, has been added to the Quartus project.
    A macro, is_a600, is used to control the compilation in a few places, mostly in
    the top entity a314_top.v.
    A new SPI protocol command has been added, SPI_PROTOCOL_VERSION. On older HDL
    this command returns the default value zero, and this version returns one.
    The a314d uses this protocol version number to be able to communicate with both
    the current and older versions of the HDL.
    The firmware version number has been replaced with a firmware flags v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
    [a314d.cc, cmem.h]
2020-09-16 Add device tree overlay to make SPI CS active high
    Changes made going from Linux kernel 4.19 to 5.4 to the SPI driver makes
    the driver ignore the SPI_CS_HIGH flag. Instead the property spi-cs-high
    is set on the SPI device tree node that tells the driver to make
    chip select active high instead of active low.
    This fixes #49.
2020-10-23 Add support for ACTION_EXAMINE_FH to a314fs
    This action is performed when doing a drag-n-drop copy from the PiDisk
    to an other device in Workbench 3.1.4
2020-11-16 Removes faulty Gerbers for A314-600
    It was found that there is a problem with the current PCB layouts for
    A314-600. The Eagle and Gerber files are removed, and when a corrected
    revision has been created it will be uploaded.
    [A314-600_v1.0.brd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]
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2021-05-12 Add a314disk.device virtual floppy drive driver
    The a314disk.device lets you mount ADF files that are stored on the
    Raspberry Pi as disks in drives PD0: to PD3:.
    The a314disk.device is ROMable, meaning that it can be added to the
    kickstart ROM image and the Amiga can then boot off of the boot block
    on the disk inserted in one of those drives.
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2021-07-22 Drop frames without corresponding read requests to avoid clogging up buffers.
2022-08-11 Use SPARE_CS address instead of RTC_CS address
    The PCB was updated so that the chip select of the cp_pi_if interface
    connects to the SPARE_CS pin on the clockport rather than to the
    RTC_CS pin. This change reflects that.
2022-08-11 Change default target frequency to 90 MHz
    This is the frequency of the clock that the Raspberry Pi outputs,
    that acts as the main clock driving the logic in the CPLD.
    Note that a target frequency of 90 MHz is rounded down to 85.7 MHz.
    And this assumes that the PLLC clock in the Pi is running at 1200 MHz.
    If the Pi is using dynamic overclocking, which is the default unless
    the line force_turbo=1 is in /boot/config.txt, then the Pi will
    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
2022-08-11 Remove hardcoded peripheral base and size constants
    Different models of Raspberry Pi have the memory mapped registers that
    controls peripherals (such as GPIO) at different addresses.
    This change uses the official method to find those base and size
    values, instead of hardcoding them.
2022-12-25 Add PiHid service
    The PiHid service is an extension of the RemoteMouse service,
    as the PiHid service allows both mice and keyboards to be connected
    to the Raspberry Pi, and the generated input events are sent to
    input.device on the Amiga.
    The service supports hot-plugging so that a mouse/keyboard can be
    added or removed at any time.
2023-01-05 Add constant for invalid A314 address
    Previously AllocMemA314 returned 0 on failure, but now that changed
    to return -1 instead. Technically this is a breaking API change,
    but hopefully it doesn't cause any issues.
    In any case, if someone is updating a314.device then the other binaries
    should typically be recompiled too.
2023-02-26 Fix typo in hid.py
    The support for the middle mouse button has likely not been tested,
    which would explain why this typo wasn't noticed before.
2023-03-07 Add support for scroll wheel mouse events
    Contributed by HeathenUK from the Discord server.
2023-07-25 Add script to install software on Raspberry Pi
    Also update instructions for building and installing using script.
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2023-11-01 Fix a314d GPIO direction change bug
    When changing GPIO directions for CP and FE models, a314d overrided
    any settings made by other applications. With this change I2C channel
    0 now works with for example RTC on the A314-FE board.
    [a314d.cc]
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

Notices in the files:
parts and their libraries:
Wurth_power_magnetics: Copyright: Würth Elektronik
